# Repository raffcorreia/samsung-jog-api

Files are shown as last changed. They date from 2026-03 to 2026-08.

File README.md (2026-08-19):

# samsung-jog-api

`samsung-jog-api` is a hardware-and-software project to make a Samsung `CJ791` monitor locally programmable by electrically emulating its front-panel `JOG` control, exposing that behavior through a local REST API, and hosting a touch-first local control interface on a Raspberry Pi-based control deck.

This repository is organized around the Samsung `LC34J791WTNXZA / CJ791` hardware in my setup. Related Samsung monitors with a similar multi-jog front-panel board may be adaptable, but the measurements and assumptions here are specific to this unit unless noted otherwise.

## Monitor photo

<p align="center">
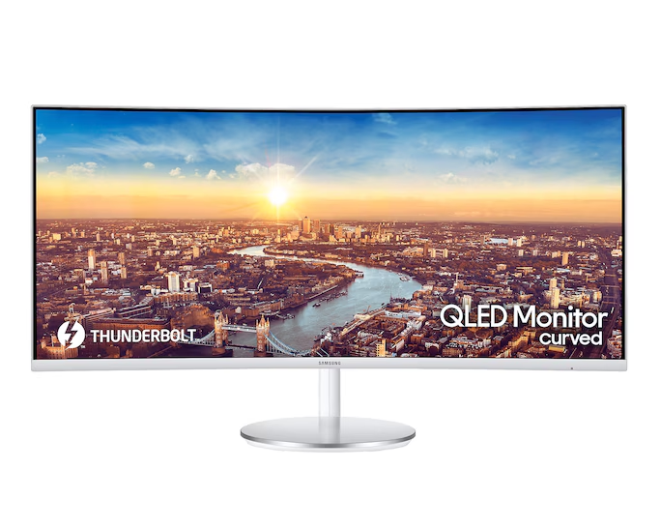
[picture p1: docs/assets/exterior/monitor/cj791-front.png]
Samsung CJ791 front view
  
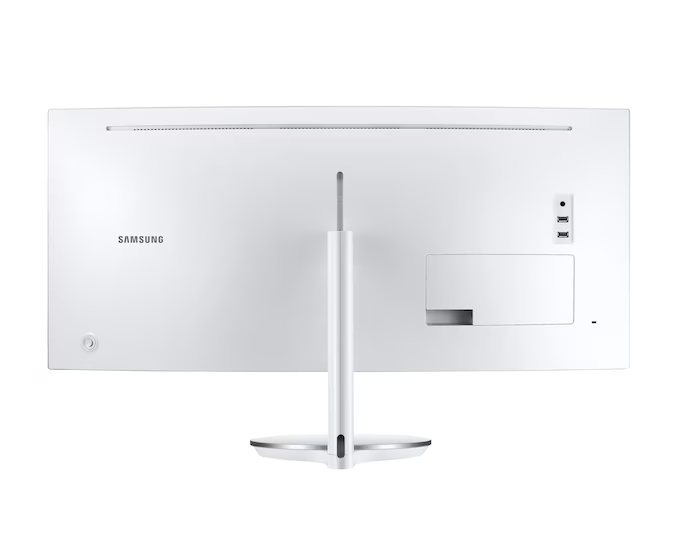
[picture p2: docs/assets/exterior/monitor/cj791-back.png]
Samsung CJ791 rear view
  
</p>

## Status

Current state of the repository:

- completed: `Phase 0: Documentation and Evidence Capture`
- completed: `Phase 1: Host Preparation and Conservative OS Cleanup`
- completed: `Phase 2: Hardware Validation`
- completed: `Phase 3: Bus Observation Circuit Design`
- completed: `Phase 4: Analog Drive Circuit Design` (design docs, KiCad schematic/PCB, BOM, and concept schematic)
- completed: `Phase 5: HDMI and DDC Communication Design`
- completed: `Phase 6: Discrete-Component Protoboard Validation`
- completed: `Phase 8: GPIO Assignment and Low-Level Control Prototype` — [execution record](docs/implementation/phase-8-execution.md)
- completed: `Phase 9: Local Platform Bring-Up` — [execution record](docs/implementation/phase-9-execution.md), [runbook](docs/runbooks/phase-9-platform-bring-up.md) (`systemd` unit `config/systemd/pi-deck.service`, kiosk scripts under `scripts/kiosk/`)
- completed: `Phase 10: Local API` — [execution record](docs/implementation/phase-10-execution.md) (REST `/api/v1`, WebSocket `/ws/events`)
- completed: `Phase 11: Low-Level JOG Console UI` — [execution record](docs/implementation/phase-11-execution.md) (React JOG console in [`frontend/`](frontend/); **live GPIO on the deck host** verified — UI drives real JOG on the appliance)
- completed: `Phase 12: Deployment and Version Tracking` — [execution record](docs/implementation/phase-12-execution.md) (`scripts/deploy.sh`, deploy counter/version badge, kiosk reload workflow)
- completed: `Phase 13: Full-Screen UI Layout with Placeholders` — [execution record](docs/implementation/phase-13-execution.md) (1280×800 deck shell, real JOG/log, calendar and notes placeholders, settings route, popup template, seven-segment clock, LED/record stubs)
- completed: `Phase 14: Log Architecture Refactor` — [execution record](docs/implementation/phase-14-execution.md) (backend-owned live log buffer, WebSocket replay on connect, synced multi-client log stream)
- completed: `Phase 15: Observation Bus and Hardware Interface` — [execution record](docs/implementation/phase-15-execution.md) (interrupt-driven ADS1115 + GPIO observation bus, single websocket authority for holds/releases/LED)
- parked, hardware access pending: `Phase 16: Recording and Replay Subsystem` — recording workspace, sequence runner, upload/download/edit/replay UI complete; on-device validation is blocked until hardware access is available
- completed: `Phase 17: Development Fixture` — [execution record](docs/implementation/phase-17-execution.md) (crude open support to hold monitor/control-deck hardware together for development)
- completed: `Phase 18: Display and Touch Validation` — [execution record](docs/implementation/phase-18-execution.md) (Waveshare DSI display/touch working; HDMI disabled as a display and retained for DDC/CI only; safe brightness ceiling `170/255`)
- completed: `Phase 19: Display Usability and Power Hardening` — [execution record](docs/implementation/phase-19-execution.md) (display/Pi power menu, brightness API/UI cap, color/edge validation page, Xwayland/font readability pass, power measurements)
- completed: `Phase 21: Display Power Control Circuit` — [execution record](docs/implementation/phase-21-execution.md) (high-side 5V switch + RC soft-start to prevent Pi 5 shutdown on display reconnect; hardware design complete)
- completed: `Phase 23: Documentation Reorganization, Versioning, and Deploy Harness` — [execution record](docs/implementation/phase-23-execution.md) (artifact-based naming for all docs and KiCad projects, git-tag versioning, auto-tag on deploy, version panel in settings UI, deploy runbook)
- next: `Phase 20: Raspberry Pi 5 Rebuild and Display Performance Validation` — [execution record scaffold](docs/implementation/phase-20-execution.md), [GPIO schema](docs/hardware/pi5-gpio-schema.md)
- in parallel: `Phase 7: Integrated Controller Board Design` (KiCad / layout in progress)
- repository now includes Phase 1 runbooks and host-preparation scripts
- repository now includes a Phase 2 execution record for hardware validation
- repository now includes a Phase 3 execution record for bus-observation hardware design
- repository now includes a Phase 4 execution record, KiCad design files, and analog-drive BOM artifacts
- repository now includes completed Phase 5 transport design documentation and execution record
- repository now includes completed Phase 6 protoboard validation documentation, schematic, BOM, and execution record
- hardware findings for the `JOG` board and DDC behavior
- requirements, design, test strategy, and implementation planning for a Raspberry Pi kiosk-style control deck
- Application code layout: [`backend/`](backend/) (Python package **`pi_deck`**: `api`, `services`, `hardware`, … per [Architecture](docs/architecture.md)), [`frontend/`](frontend/) (React/TypeScript UI; `npm run build` copies assets into `backend/src/pi_deck/static/`; **`npm run test:e2e`** in `frontend/` builds the UI, runs Playwright against mock `pi-deck` on 8756, or set `E2E_BASE_URL` for a live Pi); protoboard GPIO helpers live under `backend/src/pi_deck/hardware/`. Bring-up script: `scripts/pi-deck-gpio-probe` (see [runbook](docs/runbooks/gpio-bench-probe.md)) — see [Phase 8 Execution Record](docs/implementation/phase-8-execution.md). Host metrics / Pi baseline: `scripts/pi-deck-host-health.py` (see [Phase 9 execution](docs/implementation/phase-9-execution.md) and [Host health gate](docs/implementation/plan.md#host-health-gate-feature-phases-1028)).

## Why this project exists

The CJ791 is a capable monitor, but it is frustrating to automate cleanly.

- It has multiple useful inputs: `HDMI`, `DisplayPort`, and `Thunderbolt / USB-C`
- It has a rear-mounted `JOG` control that can navigate the on-screen display and trigger functions the normal software control path cannot, but it is inconvenient to use repeatedly
- It exposes DDC/CI, which is enough to read some state and control some functions
- It does not reliably expose the full monitor control surface over DDC alone on this unit

In practice, this project uses a hybrid model:

- `JOG` emulation for actions that need true front-panel behavior
- `DDC/CI` for machine-readable feedback and the functions that already work reliably
- front-panel `LED` observation for local feedback cues such as input-change blink patterns, idle state, and possible OSD boundary signals
- a local Raspberry Pi touch device as the always-on operator-facing control surface

This matters especially for input switching. On this monitor, source selection is effectively a cycle through available inputs rather than a reliable direct jump to a named source, so current-state feedback is what tells the controller when to stop cycling.

## System overview

High-level system shape:

- custom inline controller sits between the original `JOG` board and the monitor main board
- controller reproduces the same resistance-to-ground states the monitor expects on `KEY_ADC1` and `KEY_ADC2`
- controller observes the front-panel `LED` state as an additional feedback signal
- local backend software exposes high-level actions through a REST API
- a local touch UI runs in kiosk mode on a Raspberry Pi and calls the same API
- DDC/CI provides state readback and supported direct controls such as brightness and power

The system is expected to support three operating modes:

- `JOG` mode for raw low-level control, investigation, and recovery
- `DDC` mode, where the controller can read the current input and stop source-cycling or `PIP` navigation at the correct state
- `Blind` mode, where the UI asks the user for current and desired input so the controller can perform blind source cycling from a known starting point

## Documentation index

Use these section indexes to navigate the repository documentation:

- [Hardware Reference](docs/hardware/README.md) — GPIO wiring, Raspberry Pi pinout, monitor connections, schematics, and bills of materials
- [Implementation Plan](docs/implementation/plan.md) — planned phases and links to phase execution records
- [Investigation Data](docs/investigation/) — register captures, I2C/DDC scans, and hardware-analysis notes
- [Runbooks](docs/runbooks/) — Raspberry Pi preparation, deployment, and hardware bring-up procedures

Core project documents:

- [Requirements](docs/requirements.md)
- [Solution Overview](docs/design/solution-overview.md)
- [Architecture](docs/architecture.md)
- [Implementation Plan](docs/implementation/plan.md)
- [Test Strategy](docs/testing/test-strategy.md)
- [Code Guidelines](docs/development/code-guidelines.md)

Hardware and reverse-engineering entry points:

- [Hardware Reference index](docs/hardware/README.md)
- [Raspberry Pi 5 GPIO schema and 40-pin header reference](docs/hardware/pi5-gpio-schema.md)
- [Protoboard schematic and Raspberry Pi pinout diagram](docs/hardware/protoboard-schematic.md)
- [CJ791 JOG board notes](docs/hardware/cj791-jog-board.md)
- [CJ791 DDC and VCP Behavior](docs/ddc/cj791-vcp-behavior.md)

Operational docs:

- [Prepare Raspberry Pi](docs/runbooks/prepare-raspberry-pi.md)
- [Phase 9: Local platform bring-up](docs/runbooks/phase-9-platform-bring-up.md)
- [GPIO bench probe (protoboard)](docs/runbooks/gpio-bench-probe.md) — GPIO/I²C bring-up script on the Pi
- [Phase 2 Execution Record](docs/implementation/phase-2-execution.md)
- [Phase 3 Execution Record](docs/implementation/phase-3-execution.md)
- [Phase 4 Execution Record](docs/implementation/phase-4-execution.md)
- [Phase 5 Execution Record](docs/implementation/phase-5-execution.md)
- [Phase 6 Execution Record](docs/implementation/phase-6-execution.md)
- [Phase 8 Execution Record](docs/implementation/phase-8-execution.md)
- [Phase 12 Execution Record](docs/implementation/phase-12-execution.md)
- [Phase 13 Execution Record](docs/implementation/phase-13-execution.md)
- [Phase 14 Execution Record](docs/implementation/phase-14-execution.md)
- [Phase 15 Execution Record](docs/implementation/phase-15-execution.md)
- [Recording Syntax](docs/design/recording-syntax.md)

## Start here

Recommended reading order:

1. [README.md](README.md)
2. [Requirements](docs/requirements.md)
3. [Solution Overview](docs/design/solution-overview.md)
4. [Hardware Reference](docs/hardware/README.md)
5. [CJ791 JOG Board Notes](docs/hardware/cj791-jog-board.md)
6. [CJ791 DDC and VCP Behavior](docs/ddc/cj791-vcp-behavior.md)
7. [Implementation Plan](docs/implementation/plan.md)

## Safety and scope

This project intentionally modifies monitor hardware and is not warranty-safe.

- opening the monitor can damage clips, cables, or boards
- cutting or extending the `JOG` harness can permanently alter the monitor
- mistakes on the key lines can damage the monitor input circuitry
- nothing here should be treated as stock-safe or supportable by the manufacturer

The goal is not to preserve stock condition. The goal is to create a practical, local, programmable control interface for a monitor whose original user interface is difficult to automate cleanly.

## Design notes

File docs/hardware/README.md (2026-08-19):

# Hardware Reference

Living reference documents for the Samsung CJ791 JOG project hardware. These are named by artifact, not by the phase that created them. Phase-specific decisions and validation evidence belong in the corresponding execution records under `docs/implementation/`.

Return to the [project README](../../README.md), or choose a hardware topic below.

## Raspberry Pi and current protoboard

| Document | What it covers |
|---|---|
| [Raspberry Pi 5 GPIO schema](pi5-gpio-schema.md) | BCM numbers, physical pins, signal names, direction, and a visual 40-pin header reference |
| [Protoboard schematic](protoboard-schematic.md) | Wiring and circuit description for the Phase 6 protoboard, including the Raspberry Pi pinout diagram and display power control additions |
| [Protoboard BOM](protoboard-bom.md) | Component list for the Phase 6 discrete-component protoboard (current bring-up hardware) |

## Monitor interface and circuit references

| Document | What it covers |
|---|---|
| [CJ791 JOG board](cj791-jog-board.md) | Samsung CJ791 front-panel JOG board connector pinout, measured signal levels, and resistor-ladder values |
| [Observation circuit BOM](observation-bom.md) | Components for the CN1001 bus observation circuit (`KEY_ADC1`, `KEY_ADC2`, and `KEY_LED` conditioning) |
| [Analog drive circuit BOM](analog-drive-bom.md) | Components for reproducing the analog JOG resistor ladder |
| [HDMI and DDC transport](hdmi-ddc-transport.md) | HDMI/DDC/CI signal path, level shifting, and host integration |

## Diagrams and images

Diagrams are kept under [`docs/assets/hardware/`](../assets/hardware/) and are presented from the relevant reference document. For GPIO wiring, start with the [Raspberry Pi 5 GPIO schema](pi5-gpio-schema.md); for the complete circuit, use the [protoboard schematic](protoboard-schematic.md).

## Naming rule

- **This directory**: artifact-named living references (schematic descriptions, BOMs, GPIO maps, signal characterization)
- **`docs/implementation/phase-*-execution.md`**: frozen phase history (decisions made, measurements taken, work done)
- **`docs/assets/hardware/`**: diagrams and images referenced by the documents above

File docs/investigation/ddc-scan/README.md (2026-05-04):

# DDC VCP Scan — Phase 24 Investigation

Monitor: **Samsung C34J79x** (`SAM`, product code `0x0F1C`)
Host: Raspberry Pi 5 — I2C bus 13 (HDMI0 / `card2-HDMI-A-1`)
Tool: `tools/scripts/ddc-scan.py`

## Methodology

Three independent passes were run to rule out any order-dependent or state-dependent response behaviour.
The retry policy in each pass: if the previous command succeeded but the current one fails, wait 5 s and retry once before moving on.

| Pass | File | Order | Codes scanned | Codes responding |
|---|---|---|---|---|
| 1 | `ddc-scan-20260501-153903` | Ascending (0x00→0xFF) | 256 | **32** |
| 2 | `ddc-scan-20260501-161242` | Descending (0xFD→0x00) — only the 224 that did not respond in Pass 1 | 224 | **0** |
| 3 | `ddc-scan-20260501-161655` | Random (all 256) | 256 | **32** |

**Conclusion: the monitor exposes exactly 32 VCP codes regardless of scan order.** No codes are shy or order-dependent. The capability string returned nothing in all three passes — brute-force was the only reliable method.

## Responding Codes (ground truth)

| Code | Name | Type | Current (Pass 1) | Max / SL |
|---|---|---|---|---|
| `0x02` | New Control Value | CNC | — | x00 xff x00 x02 |
| `0x0B` | Color Temperature Increment | CNC | — | xff xff x00 x32 |
| `0x0C` | Color Temperature Request | C | 40 | 170 |
| `0x10` | Brightness | C | 59 | 100 |
| `0x12` | Contrast | C | 75 | 100 |
| `0x14` | Select Color Preset | SNC | — | x04 |
| `0x16` | Red Video Gain | C | 70 | 100 |
| `0x18` | Green Video Gain | C | 70 | 100 |
| `0x1A` | Blue Video Gain | C | 70 | 100 |
| `0x52` | Active Control | CNC | — | x00 xff x00 x00 |
| `0x60` | Input Source | SNC | — | x04 (value meaning TBD) |
| `0x62` | Audio Speaker Volume | C | 3 | 100 |
| `0x6C` | Video Black Level: Red | C | 50 | 100 |
| `0x6E` | Video Black Level: Green | C | 50 | 100 |
| `0x70` | Video Black Level: Blue | C | 50 | 100 |
| `0x8D` | Audio Mute | SNC | — | x02 |
| `0xAA` | Screen Orientation | SNC | — | x00 |
| `0xAC` | Horizontal Frequency | C | 23364 | 65281 |
| `0xAE` | Vertical Frequency | C | 6000 | 65535 |
| `0xB2` | Flat Panel Sub-Pixel Layout | SNC | — | x01 |
| `0xB6` | Display Technology Type | SNC | — | x03 |
| `0xC0` | Display Usage Time | C | 200 | 65535 |
| `0xC6` | Application Enable Key | CNC | — | xff xff x00 x6f |
| `0xC8` | Display Controller ID | CNC | — | xff xff x00 x12 |
| `0xC9` | Display Firmware Level | CNC | — | xff xff x01 x20 |
| `0xCA` | OSD/Button Control | SNC | — | x02 |
| `0xCC` | OSD Language | SNC | — | x02 (English) |
| `0xD6` | Power Mode | SNC | — | x01 (On) |
| `0xDC` | Display Application | SNC | — | x02 |
| `0xDF` | VCP Version | CNC | — | x02 x01 (v2.1) |
| `0xFE` | Unknown — manufacturer-specific | CNC | — | x00 x02 x00 x02 |
| `0xFF` | Unknown — manufacturer-specific | CNC | — | x00 x01 x00 x00 |

## Notable observations

- **No capability string** — the monitor does not advertise supported codes; brute-force was required.
- **Retry logic fired heavily** — a successful read frequently causes the next query to fail. The 5 s retry is necessary for accurate results.
- **`0xAE` Vertical Frequency** read as `6000` in Pass 1 and `6010` in Pass 3 — minor variance, likely centihz (60.00 / 60.10 Hz).
- **`0xFE` and `0xFF`** respond but are not defined in the MCCS standard — manufacturer-specific, worth further investigation.
- **`0x60` Input Source** current value `x04` — exact Samsung mapping TBD (next step).
- **`0xD6` Power Mode** current value `x01` = On (MCCS standard: 1=On, 2=Standby, 3=Suspend, 4=Off).

## Next steps

1. Decode `0x60` Input Source: enumerate valid values by switching inputs and reading back.
2. Test `0xD6` Power Mode writes for standby/wake control.
3. Investigate `0xFE` and `0xFF` manufacturer-specific codes.

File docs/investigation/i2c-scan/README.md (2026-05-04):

# Samsung C34J79x — Raw I2C Scan Findings

Phase 24 investigation. Raw I2C reads via `smbus2` on I2C bus 13, bypassing DDC/CI protocol.
DDC only surfaces what the firmware advertises; direct I2C exposes the full scaler register map.

Script: `tools/scripts/collect-register-capture.py`

---

## Device map — I2C bus 13

| Address | Device | Notes |
|---|---|---|
| `0x37` | DDC/CI controller (8051 MCU) | Raw I2C returns bus echo only; must use DDC/CI protocol |
| `0x50` | EDID ROM | |
| `0x54` | Likely HDCP controller | Activates when Pi HDMI port is outputting; not display-state-dependent |
| `0x58` | Novatek scaler SoC (probable) | 256/256 registers readable; holds live scaler and pipeline state |

---

## DDC VCP 0x60 — most reliable source indicator

Read via DDC/CI protocol on device 0x37 (no ddcutil needed). Unaffected by OSD or overlays.

| Value | Source |
|---|---|
| `0x01` | HDMI |
| `0x03` | DisplayPort |
| `0x04` | Thunderbolt / USB-C |

In PBP mode: reports the left/primary source.
In PIP mode: reports the main (large) source.

---

## Device 0x58 — register reference

### Reliable registers

| Register | Meaning |
|---|---|
| `0x48=0x0F` | PIP mode active (was `0x00` in all PBP and single-source captures) |
| `0x48=0x00` | PBP or single-source mode |
| `0x4A=0x00` | Sound routed left |
| `0x4A=0x02` | Sound routed right |
| `0xA1=0x00` | No active video signal |
| `0x02=0x79` | Scan sanity check — confirms scaler is in a normal active state |

### Persistently noisy registers — exclude from detection logic

These change between reads of the same state and carry no reliable state information:

- `0x3C`, `0x3D`, `0x3E` — free-running counters
- `0xA0`, `0xA3`, `0xA5` — active-state noise, no stable value
- `0xA1` — toggles between `0x21` and `0x22` unpredictably during active video
- `0x0B`, `0x0C`, `0x0D` — toggle between two fixed values on a ~2–4s period; likely frame sync counters
- `0x1F` — oscillates between `0x00` and `0xEE`

---

## PIP mode — E0–E3 pipeline register matrix

> All PIP scans: style = **Wide**, position = **top-left** (position has no effect on any register — see below).
> All confirmed clean: `0x58:0x02=0x79`, `0xE1≠0xFA` at scan time.

| Directory | Main | PIP | Size | VCP 0x60 | 0xE0 | 0xE1 | 0xE2 | 0xE3 |
|---|---|-----|---|---|---|---|---|---|
| `pip-size1-tb-small-dp-main` | DP | TB | 1 | `0x03` | `0x80` | `0xE2` | `0x00` | `0x00` |
| `pip-size2-tb-small-dp-main` | DP | TB | 2 | `0x03` | `0x40` | `0x8C` | `0x01` | `0x2E` |
| `pip-size3-tb-small-dp-main` | DP | TB | 3 | `0x03` | `0x40` | `0x8C` | `0x01` | `0x2E` |
| `pip-size1-hdmi-small-dp-main` | DP | HDMI | 1 | `0x03` | `0x40` | `0x4E` | `0x00` | `0x00` |
| `pip-size2-hdmi-small-dp-main` | DP | HDMI | 2 | `0x03` | `0x40` | `0x8C` | `0x01` | `0x2E` |
| `pip-size3-hdmi-small-dp-main` | DP | HDMI | 3 | `0x03` | `0x80` | `0xE2` | `0x00` | `0x00` |
| `pip-size1-hdmi-small-tb-main` | TB | HDMI | 1 | `0x04` | `0x40` | `0x35` | `0x05` | `0x20` |
| `pip-size3-hdmi-small-tb-main` | TB | HDMI | 3 | `0x04` | `0x40` | `0x35` | `0x05` | `0x20` |
| `pip-size3-tb-small-hdmi-main` | HDMI | TB | 3 | `0x01` | `0x80` | `0xE2` | `0x00` | `0x00` |

### Key findings from the matrix

- **TB main is fully blind** — E0–E3 are identical (`0x40/0x35/0x05/0x20`) regardless of PIP source or size.
  Cannot detect PIP source, size, or position from registers when TB is the main source.
- **PIP source is not independently detectable for DP main** — TB pip and HDMI pip at size2 produce identical
  E0–E3 values; same at size3 vs size1. Only size1 HDMI pip has a unique value (`0xE1=0x4E`).
- **E0–E3 encode a non-linear combination** of main source, PIP source, and size simultaneously.
  Cannot decode any single dimension independently.
- **VCP 0x60 identifies main source reliably** regardless of PIP source, size, or position.

### Contamination note

`pip-size1-hdmi-small-dp-main` was recaptured on 2026-05-02 after the original scan was found contaminated —
E0–E3 matched the Menu2 OSD state exactly, indicating the OSD was still open when the original scan ran.
The recheck confirmed the clean values above.

---

## PIP window position — register invisible

Tested on HDMI pip / TB main / size1 across all four positions (top-left, top-right, bottom-left, bottom-right).
Full 256-register diff showed no differences in any stable register across all positions.
**PIP window position has no effect on any 0x58 register.**

---

## OSD / overlay register behaviour

Tested 2026-05-02 via scripted button presses, full 256-register scan at 1s intervals.
State: TB main / HDMI pip / size1 / Wide / top-left.

### What is reliable

- **`0xE1=0xFA`** — fires when Menu1 OSD is open (including after UP navigation). Use as a scan guard:
  if `0xE1=0xFA`, abort and retry — the scan will be contaminated.
- **`0xE3=0x6E`** — appears after UP navigation within Menu1. `0x00` at the first Menu1 item.
- **`0xA7=0x00`** — drops during a physical button press, recovers to `0xF8` within ~500ms.

### What cannot be tracked

- **Menu2 is register-identical to baseline.** When CENTER is pressed from Menu1+UP, `0xE1` drops from
  `0xFA` back to its baseline value within ~1s. Registers look exactly like OSD-closed from that point.
  There is no way to tell from 0x58 whether Menu2 is on screen.
- **OSD inactivity close (~18–20s after last input in Menu2) produces no detectable register change.**
  Full 256-register scans at 1s intervals throughout the close window showed nothing definitive.
- **`0xE1=0xFA` is a Menu1 indicator only, not a universal OSD indicator.** The clean-scan guard
  only protects against Menu1 contamination; Menu2 contamination is invisible.

### Suspicious registers observed at OSD close

A one-sample transient was caught at the moment the OSD appeared to close (~+18s after Menu2 entry):
`0x4A`, `0x0D`, and `0x11` all read `0x00` simultaneously, recovering at the next 1s sample.
`0x4A` (sound routing) is normally rock-solid at rest. Not conclusive — the full scan takes ~1s to
execute, so these may have been caught mid-transition rather than representing a stable state.

---

## ⚠️ E0–E3 contamination warning

All PBP scan data for `0xE0`–`0xE3` is potentially contaminated — input-change notifications and OSD
menus were likely displayed during those captures.

**Protocol for clean captures:**
1. Wait for all on-screen messages to fully dismiss
2. Confirm `0xE1 ≠ 0xFA` (no Menu1 OSD open)
3. Be aware that Menu2 is undetectable — wait at least 25s after any OSD interaction before scanning

**Retake policy:** validate every capture inline before moving to the next state. If any of the following fail, call it immediately and retake on the spot — do not defer:
- `0x02 ≠ 0x79` — scaler not in normal state
- `0xE1 = 0xFA` — Menu1 OSD still open
- Values match a known-contaminated pattern (e.g. E0–E3 matching a Menu2 or wrong-mode fingerprint)
- Result looks inconsistent with the expected mode

---

## Scan file index

### Baseline / single-source (Phase 24 initial scans)

| File | State |
|---|---|
| `i2c-scan-idle-20260501-210013.jsonl` | Monitor idle, no active source |
| `i2c-0x58-on-idle-20260501-212914.jsonl` | 0x58 only, post-reboot idle |
| `i2c-0x58-tb-active-20260501-214114.jsonl` | 0x58 only, Thunderbolt active |
| `i2c-all-tb-active-20260501-215231.jsonl` | All devices, Thunderbolt active |
| `i2c-all-dp-active-20260501-220136.jsonl` | All devices, DisplayPort active |
| `i2c-all-hdmi-active-20260501-222201.jsonl` | All devices, HDMI active (Pi, incompatible resolution) |

### PBP (contaminated — E0–E3 not trustworthy)

`pbp-*/` — all 6 combinations × 2 sound positions. E0–E3 captured with input-change messages on screen.

### PIP (clean, Wide style, top-left unless noted)

See matrix table above. Position scans (top-right, bottom-left, bottom-right) stored under
`pip-size1-hdmi-small-tb-main-{topright,bottomleft,bottomright}/` — confirmed identical to top-left.

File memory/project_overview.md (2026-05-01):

---
name: Project Overview — samsung-jog-api-2
description: High-level goal, phase structure, current status, Phase 7 architecture decisions, and Phase 14 UI/log state
type: project
---

Hardware + software project to build a Raspberry Pi 2B-based control deck for a Samsung LC34J791WTNXZA (CJ791) ultrawide monitor. The monitor's only input mechanism is a physical JOG (joystick) on the rear. The goal is to electrically emulate the JOG via resistance-to-ground states on KEY_ADC1/KEY_ADC2 lines, observe KEY_LED feedback, maintain DDC/CI communication, and expose control through a local REST API + WebSocket with a React/TypeScript kiosk UI on a Waveshare 7" DSI display.

**Deck UI:** Phase 13 complete. Single-screen kiosk layout (**1280×800** target). Widgets use **fixed layout bands** so panels do not reflow when the log grows (log scrolls internally). Final Phase 13 geometry: top bar `48px`, left JOG column `350px`, bottom log band `200px`. Optional widget visibility is user-driven later — not implicit layout shift. Identity ("pi-deck") stays in the status/version area, not duplicated as nested marketing chrome around each control.

**Phase structure (28 phases, 0–27). Phases 0–6, 8–15, and 17–18 are closed. Phase 16 is parked because hardware access is unavailable for validation. Phase 7 KiCad/layout remains in progress. Phase 19 has not started.**

**Phase 13 UI state:** Full-screen deck shell is implemented and deployed (`0.1.0+r20`). The real JogPad remains the priority control and lives in the fixed left column. The clock uses `DSEG7 Classic` seven-segment font, enlarged and vertically centered without increasing the `48px` top bar. Settings cog is top-right. LED is an 8mm-style gray default indicator and should turn blue only for future blink/feedback events, not for steady backend `key_led_active`. Record control exists as a visual/logging stub in the upper-right of the JOG column. Calendar, notes, settings, and OSD popup are realistic stubs/placeholders for later phases.

**Phase 14 log state:** Backend-owned live logging is implemented and deployed (`0.1.0+r22`). `LiveLogService` owns the `220`-entry replay buffer and emits structured `log/entry` WebSocket events. New clients receive replayed history immediately; multiple clients receive the same live stream. Frontend log code no longer formats command/control/bus events into local history.

**Phase 16 state:** Recording and replay subsystem code is complete and merged to main. Recording workspace popup, sequence runner, upload/download/edit, and replay UI are all implemented. Hardware validation (on-device recording/replay runs, KEY_ADC2 stall visibility during long captures) is still pending, but the phase is parked because hardware access is unavailable.

**Phase 17 state:** Closed on 2026-04-20 with a crude open support to hold the monitor/control-deck hardware together. This is intentionally not a polished enclosure or detailed mechanical design.

**Phase 18 state:** Closed on 2026-04-22. Waveshare 7" DSI display and touch are working on the Pi 2 deck host. Safe maximum brightness is `170/255`. HDMI visual output destabilized DSI scanout on this stack, so HDMI is disabled as a Linux display with `video=HDMI-A-1:d` and retained for DDC/CI communication only. DDC/CI Get VCP `0x60` succeeded on HDMI DDC while DSI/touch and ADS observation remained active.

**Phase 19 state:** Planned next. Display usability and power hardening: functional display/Pi power menu, capped brightness control, display color/edge validation page, and documentation of display power-off behavior.

**Log / event hygiene (backlog):** WebSocket and derived log traffic may feel excessive or not representative of what operators care about (duplicate `bus/snapshot` with `deck_control`, telemetry poll cadence, verbosity of `command`/`control` lines). Plan a later pass to coalesce, filter, or re-level categories so the live log stays readable without losing auditability.

**Active defect:** `KEY_ADC2` live observation has stalled twice across Phase 15/16 work. In the later case, redeploying the app restored directional observation without changing wiring. Treat this as an unresolved observation-path/runtime defect, not a closed protoboard-only issue.

**Hardware vs software sequencing:** Phase 8+ low-level software is brought up on the **Phase 6 GPIO map** first. When Phase 7 boards are fabricated, an **extra migration phase** will be inserted (slot TBD) to remap GPIO and retest software against the **Phase 7 pinout** — see `docs/implementation/plan.md` ("Deferred integrated-board GPIO and software migration").

**Why:** Input switching on the CJ791 is cycle-through-inputs only. DDC alone can't switch; JOG alone can't read state. Both are needed together.

## Phase 7 Build Path

The original Phase 7 intent was a home-built board using through-hole transistors, resistors, and capacitors (except the ADS1115 which was always SMD). That path is still valid. The KiCad/PCBWay route with SMD components and proper OpAmps is an exciting upgrade opportunity that emerged during design, not a replacement for the original plan. Either path closes Phase 7 — the choice depends on how far the PCBWay enthusiasm carries through layout completion.

**Why:** Keeping the through-hole option alive avoids blocking the project on PCB fabrication if motivation or timeline shifts.

## Phase 7 Architecture (settled as of 2026-04-11)

**Two-board design:**
- Board 1 (Controller): Phase 3 + Phase 4 merged. JST PH 2.0mm 4-pin monitor harness, 2×20 IDC Pi header, 2×7 IDC inter-board connector.
- Board 2 (HDMI DDC): Phase 5 unchanged except J3 replaced with 2×7 IDC inter-board header.

**Connectors:**
- Monitor harness: JST PH 2.0mm 4-pin (B4B-PH-K-S, C157929 at JLCPCB). 30AWG 4-core cable.
- Pi interface: 2×20 shrouded IDC box header + 40-pin ribbon cable.
- Inter-board: 2×7 shrouded IDC box header + 14-pin ribbon cable (pre-made IDC cables).

**Power:** Pi powered by its own 3A micro-USB supply. Pi GPIO rails power boards (no onboard regulation on boards). Pi 2B + Waveshare 7" DSI + USB WiFi + boards = ~1.82A, well within 3A supply.

**GPIO (17 signals used, 9 free):**
- GPIO2/3: I2C SDA/SCL (fixed)
- GPIO17,27,22,23,24: ADC2_LEFT/RIGHT/DOWN/UP_EN, ADC1_CENTER_EN (outputs)
- GPIO25: PI_DDC_DISC_REQ (output)
- GPIO5: MON_5V_DISABLE (output)
- GPIO6,12,13: KEY1_IN_GPIO, LED_IN_GPIO, ADC_ALERT (inputs)
- GPIO19,16,26,20,21: DDC_READY, SRC_5V_SENSE, RESERVED, PIN18_STAT, HPD_SENSE (inputs)

**Passives:** All 0603 metric throughout both boards.

**Peripherals:**
- Waveshare 7" DSI LCD (E), 1280×800 (~700mA)
- USB WiFi adapter (~300mA)
- Logitech USB dongle (development only, ~100mA)

**KiCad files location:**
- Board 1: hardware/kicad/controller-board/
- Board 2: hardware/kicad/hdmi-ddc-board/

**Execution record:** docs/implementation/phase-7-execution.md

**Status as of 2026-04-11:** Execution record written. KiCad schematics in progress. PCB layout not yet done.

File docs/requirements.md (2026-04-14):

# Requirements

## Purpose

This document defines the functional and non-functional requirements for `samsung-jog-api` as a local control deck for the Samsung `CJ791` monitor. The system combines a local kiosk UI, a backend control service, analog `JOG` emulation, `DDC/CI` readback, and front-panel `LED` observation.

This is explicitly a hardware-and-software project. The system requires interface hardware that can bridge between the host's control interfaces and the monitor's analog key and signal paths.

The purpose of this document is to define the system's required behavior, constraints, and acceptance expectations. Setup procedures, implementation details, and exploratory notes belong in other documents unless they are necessary to clarify a requirement.

## System overview

The system consists of:

- a local host device with a display and kiosk-style user interface
- a local frontend UI
- a local backend service
- custom hardware that emulates the monitor's front-panel `JOG` inputs through the monitor's analog key lines
- custom hardware that reads the front-panel `LED` signal and other relevant monitor-side signals
- `DDC/CI` integration for monitor-state readback and supported direct controls

The target monitor is currently the Samsung `LC34J791WTNXZA / CJ791`.

## Functional requirements

### Device and UI

- The system must run as a dedicated local appliance on a control deck or equivalent local host device.
- The system must present a touch-first graphical UI on the device display.
- The UI must run in kiosk mode.
- The UI must be accessible both on the device itself and remotely from other clients on the same trusted local network, such as a phone or another computer.
- The UI must be fully implemented in English.
- The UI must support light mode and dark mode.
- The device must auto-start the application stack on boot.
- The device must recover automatically after process crashes or system reboots.
- Normal operation must not require a keyboard.

### Dashboard and widgets

- The UI must display a clock widget.
- The UI must display a month calendar widget with today's date selected and today's appointments list.
- The UI must display a notes widget.
- The UI must display system performance widgets including:
  - throttling status
  - CPU usage
  - memory usage
- The performance area must support a detailed view showing:
  - storage usage
  - network usage

### Monitor control

- The system must control the monitor by electrically reproducing the analog behavior of the front-panel `JOG` controls.
- The system must expose low-level `JOG` actions equivalent to `up`, `down`, `left`, `right`, and center press.
- The system should preserve use of the original front-panel `JOG` board when practical and electrically safe.
- The system must support recording and replaying `JOG` action sequences so repeatable OSD workflows can be captured and reused.
- The system must expose monitor control through a local backend API.
- The API must support both low-level primitives and higher-level monitor actions.

### Input switching and operating modes

- The system must model input switching as source cycling rather than assuming reliable direct selection is available.
- The system must treat current input state as operationally important for source switching.
- The system must support a `DDC` mode in which current input state is read from the monitor and used to terminate source-cycling at the correct target input.
- The system must support a `Blind` mode for workflows where `DDC` readback is unavailable or unreliable.
- In `Blind` mode, the UI must let the user choose the current input and desired input so the controller can calculate how far to cycle.
- In `DDC` mode, the UI should allow simplified target-driven source selection.

### Picture-in-Picture and related monitor workflows

- The system must support enabling and configuring `PiP`.
- The UI must provide a `PiP` action that lets the user choose the left input and right input.
- In `DDC` mode, the system should simplify `PiP` configuration by using available monitor-state feedback.
- In `Blind` mode, the system must still allow `PiP` workflows using user-provided starting state and blind `JOG` sequencing.

### DDC and LED feedback

- The system must read monitor state through `DDC/CI` whenever reliable and available.
- The system must provide direct software control for features that already work over `DDC`, such as brightness and power state.
- The system must preserve practical use of the monitor's `HDMI` input while maintaining a `DDC` communication path for the control deck.
- The system must include interface hardware that allows an external device to use the monitor's `HDMI` input while the control deck also communicates with the monitor over `DDC`.
- The system must observe the front-panel `LED` state as a feedback input.
- The system should use front-panel `LED` behavior as an additional confirmation signal for monitor-state changes and OSD workflows.
- The UI should reflect relevant `LED` activity visually.
- `LED` signals may be used as command acknowledgment where their meaning is sufficiently characterized.

### Shared state and synchronization

- The system must maintain a single coherent model of `JOG` control ownership and current monitor interaction state.
- The system must prevent conflicting concurrent `JOG` actions from being executed at the same time.
- The system must support real-time communication between frontend clients and the backend.
- Any action performed in one UI instance must be reflected in all connected UI instances.
- Real-time synchronization must include:
  - button presses
  - state changes
  - monitor interactions

## Hardware requirements

### JOG control path

- The system must simulate the monitor's resistive analog key inputs.
- The system must interface with `KEY_ADC1` and `KEY_ADC2`.
- The system must reproduce the required analog states safely and repeatably.
- The project must define and document the electronic components used in the control path.

### Signal reading

- The system must be able to observe the relevant monitor-side signals needed for control-state awareness.
- The system must read or infer the state of `KEY_ADC1` and `KEY_ADC2` as needed for validation and arbitration.
- The system must detect both:
  - system-generated inputs
  - manual user inputs on the physical control path
- The system must provide a hardware path for shared or multiplexed `HDMI` and `DDC` access so monitor input availability is not unnecessarily reduced by the control deck.

### LED input

- The `KEY_LED` signal must be connected as input only.
- The system must not drive the monitor's `LED` output line.

### Physical controls and design outputs

- The system must include a physical button for toggling the display power, while the deck itself remains powered so it can continue controlling the monitor.
- The project must include and document:
  - circuit design and schematic
  - component specification and `BOM`
  - integrated controller board design
  - PCB design, if applicable

## Software architecture requirements

### Layers

The system must be organized into these logical layers:

- hardware control layer
- backend API layer
- frontend UI layer

### Communication

- The frontend and backend must communicate locally over `localhost`.
- The system must support bidirectional communication between frontend and backend.
- Real-time communication is required.

### Deployment

- Deployment may be manual in the current phase.
- Host-device administration may be performed over the local network using `SSH` with public-key authentication when applicable.
- `CI/CD` is out of scope for the current phase.

## Security requirements

### Current phase

- The system must run with an auto-login kiosk user.
- No password is required for local UI access on the kiosk device itself.
- Remote UI and API access must be limited to the trusted local network.
- External internet exposure is out of scope and should be avoided by default.

### Minimal protection

- The system should support optional token-based authentication for API access.

### Future considerations

- authentication and authorization mechanisms
- secure remote access
- role-based access control
- API security hardening

## Non-functional requirements

### Testing

- Testing is a project requirement.
- Testing must cover:
  - backend logic
  - frontend behavior
  - hardware interaction
- No task should be treated as complete before the relevant test coverage has passed.

### Performance

- The system must monitor host-device performance continuously during normal operation.
- The system must detect and expose throttling conditions.
- The software stack should remain lightweight enough for the initial target host class.

### Reliability

- The system must operate continuously in kiosk mode.
- The UI must recover automatically after crashes or reboot.
- The system should degrade gracefully when `DDC` readback is unavailable.
- The system should remain usable in `Blind` mode when `DDC` state is unavailable.

### Usability

- The UI must be touch-friendly.
- The initial UI design target is the **7" DSI capacitive touch display at `1280×800`** while remaining responsive for other screen sizes used through the host URL.
- The UI must adapt to the target screen size and orientation used by the control deck.
- The UI should make the active operating mode clear to the user.

### Maintainability

- The system should preserve a clear separation between hardware control, monitor-state readback, API behavior, and UI logic.
- Hardware assumptions and measured monitor behavior must be documented explicitly.

## Assumptions

- The monitor decodes front-panel actions by measuring analog thresholds on `KEY_ADC1` and `KEY_ADC2`.
- Reproducing the original resistance values closely enough will allow the monitor to interpret emulated actions as native `JOG` input.
- `DDC/CI` remains useful as a feedback and telemetry channel even where it is incomplete as a control channel.
- Input changes are reached by cycling through sources rather than reliably selecting a named input directly.
- The front-panel `LED` exposes observable behavior that can help confirm state changes such as input switching, idle state, and some menu boundary conditions.
- Common user goals can be represented as a combination of low-level button actions, `DDC` readback, `LED`-assisted feedback, and user-provided current-state information when needed.

## Constraints

- The target monitor is currently the Samsung `LC34J791WTNXZA / CJ791`.
- The monitor does not appear to expose full input switching reliably through `DDC/CI` alone.
- Occupying the monitor's `HDMI` path for `DDC` communication would reduce practical input availability unless compensated by custom interface hardware.
- The front-panel control path is analog, not purely digital.
- Hardware modification is expected and accepted.

## Acceptance criteria

The following criteria should be used to judge whether the initial implementation satisfies the requirements:

- Kiosk recovery: after reboot or a forced frontend crash, the device returns automatically to the kiosk UI without manual intervention.
- Local and remote UI access: the UI is usable on the kiosk itself and from another device on the same local network.
- `JOG` control: the system can perform each low-level `JOG` action and the monitor responds as expected.
- `DDC` mode source switching: from a known source, requesting a target source results in the monitor stopping on the requested source as confirmed by `DDC`.
- `Manual` mode source switching: given a user-selected `from` source and `to` source, the system performs the expected source-cycle sequence without relying on hidden state.
- `PiP` configuration: the system can execute a `PiP` workflow where the user selects left and right inputs.
- `LED` capture: the system can observe and expose `LED` behavior during at least idle state and source switching.
- `HDMI` preservation: the control deck maintains `DDC` communication without permanently sacrificing the monitor's practical `HDMI` input for external devices.
- Arbitration: conflicting simultaneous `JOG` actions are blocked, queued, or rejected consistently.
- Synchronization: actions and state changes in one client are reflected in other connected clients in near real time.
- Testing gate: backend, frontend, and hardware-facing tests pass before a feature is considered complete.

## Out of scope for the current phase

- support for unrelated monitor models without confirmed measurements
- external internet-facing access
- mobile native applications
- a physical volume knob, even though monitor volume control over `DDC` has been confirmed to work
- voice control
- multi-deck scaling
- `CI/CD`
- advanced authentication and authorization

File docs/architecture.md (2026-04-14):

# Architecture

## Summary

`samsung-jog-api` is built around a hybrid control architecture for the Samsung `CJ791` monitor:

- electrically emulate the front-panel `JOG` control path
- expose that behavior through a local REST API
- pair it with a small local touch UI running on a Raspberry Pi control deck
- use DDC/CI and front-panel `LED` observation as complementary feedback and status channels whenever possible

The guiding idea is simple: the monitor already knows how to respond to its own front-panel controls, so the most robust path to full control is to reproduce those same electrical states instead of relying on unsupported software-only shortcuts.

## Why this project exists

The CJ791 is a capable monitor, but it is frustrating to automate.

- It has multiple useful inputs: `HDMI`, `DisplayPort`, and `Thunderbolt / USB-C`
- It has a rear-mounted `JOG` control that can navigate the on-screen display and trigger functions the normal software control path cannot, but it is inconvenient to use repeatedly
- It exposes DDC/CI, which is enough to read some state and control some functions
- But it does not reliably expose the full monitor control surface over DDC alone

In a setup where the monitor acts like part of a desk controller, KVM-like workflow, wall panel, or local touch-screen system, blind software-only control is not enough. It needs a control path that matches what a human can do with the physical `JOG` button.

## Why the destructive part

This project intentionally takes an invasive approach.

The front-panel `JOG` assembly is connected to the monitor main board through a small harness. Rather than using motors, servos, or guessed internal software protocols, the plan is to intercept that harness and electrically reproduce the same button states the monitor already understands.

That is the destructive part:

- the monitor must be opened
- access to the front-panel control board and cable is required
- the cable may need to be cut, extended, or replaced with an inline harness
- a custom controller board can then sit between the original `JOG` board and the monitor

This is destructive in the sense that it modifies the physical monitor wiring and is not a stock, warranty-safe accessory. It is still a pragmatic choice because it targets the monitor's native control mechanism instead of relying on brittle mechanical hacks.

## Control model

The intended control model combines two different paths:

- `JOG` emulation for actions that require authentic front-panel behavior
- `DDC/CI` for readback, health checks, and functions that already work reliably
- front-panel `LED` observation for local visual confirmation of monitor behavior
- a local kiosk device as the dedicated human interface layer

At the API layer, the monitor should look like a normal controllable device rather than a collection of resistor values and timing hacks.

One important constraint is that input changes are not reliably direct-addressable. In practice, the monitor behaves like it exposes `next input` behavior through the OSD path, so source control depends on knowing the current input and cycling until the desired state is reached.

## Planned control method

The hardware plan is to insert a controller inline with the `JOG` harness.

The controller will:

- leave the original front-panel board usable when desired
- reproduce the same resistance-to-ground states for `KEY_ADC1` and `KEY_ADC2`
- observe the front `LED` line and expose its state to higher layers
- expose a local API for high-level actions such as `up`, `down`, `left`, `right`, `enter`, `back`, `open-menu`, and scripted navigation sequences
- support a Raspberry Pi-based local touch UI that calls the same API in kiosk mode

Example higher-level actions:

- switch to the next available input
- cycle from one known input to another known input
- open source list
- navigate to `Picture-by-Picture`
- toggle a known setting
- wake or sleep the monitor

## How DDC fits into the design

DDC/CI is a complementary readback channel, not the only control path.

Instead of using DDC as the entire solution, `samsung-jog-api` uses it where it is strongest:

- confirm current input with `VCP 0x60`
- read or set brightness with `VCP 0x10`
- control standby with `VCP 0xD6`
- verify that the monitor is alive and reachable over the video link
- provide state to the local UI without inferring everything from blind menu timing

The front-panel `LED` is the other important feedback source:

- observe blink patterns during input changes
- detect visible confirmation cues when a menu or scroll path reaches its boundary
- distinguish some idle versus active monitor states even when `DDC` is incomplete or delayed

## Operating modes

Two obvious operating modes fall out of this design:

- `DDC` mode: use `DDC` readback to know the current input and stop source-cycling or `PIP` navigation when the target state is reached
- `Blind` mode: when `DDC` is unavailable or untrustworthy, ask the user for current input and desired input, then execute the required blind cycling sequence

This distinction matters because the monitor does not provide a reliable direct `go to HDMI` or `go to Thunderbolt` control path. The safe abstraction is not direct selection. It is controlled cycling with feedback where available.

This hybrid model is the point of the project:

- `JOG` emulation gives access to the same menu and navigation path as a human user
- `DDC` provides machine-readable feedback and state
- `LED` observation provides immediate local feedback from the front-panel path itself
- the control deck turns those capabilities into an always-on appliance-like interface

That is much more robust than using only blind button presses, and much more capable than relying on DDC alone on this monitor. Blind-button operation is still possible, but this project prefers a feedback-aware path when available.

## Project goals

- build a reliable inline `JOG` controller for the Samsung `CJ791`
- expose monitor actions through a local REST API
- provide a Raspberry Pi-based local touch-screen UI for everyday use
- use `DDC/CI` and front-panel `LED` state for feedback and status, and `DDC/CI` for supported direct controls
- keep the design understandable enough that other Samsung owners can adapt it

## Repository layout

The repository is split so **documentation**, **KiCad hardware**, **host scripts**, and **application code** stay separate.

| Path | Purpose |
|---|---|
| `backend/` | Python package **`pi_deck`** (`backend/pyproject.toml`, distribution name `pi-deck`). Source: `backend/src/pi_deck/`. Layers: `api`, `services`, `hardware`, `storage`, `models`. Matches the system model *UI → API → services → hardware (+ DDC)* in [Solution Overview](design/solution-overview.md). |
| `frontend/` | React / TypeScript **JOG console** (kiosk + LAN); `npm run build` emits into `backend/src/pi_deck/static/` ([Code Guidelines](development/code-guidelines.md#frontend-guidelines)). |
| `docs/` | Requirements, design, implementation records, runbooks. |
| `hardware/kicad/` | Schematics and boards (not Python). |
| `scripts/` | Operational shell helpers, **bench / bring-up Python** (e.g. GPIO smoke tests, [`pi-deck-host-health.py`](../../scripts/pi-deck-host-health.py) — not part of the `pi_deck` installable surface). |
| `config/` | Example configs for host preparation and systemd unit templates (`config/systemd/`). |

Application code for Phases 9–12 lands in **`backend/`** and **`frontend/`**; KiCad stays under **`hardware/`**.

## Related documents

- [Requirements](requirements.md)
- [Solution Overview](design/solution-overview.md)
- [Code Guidelines](development/code-guidelines.md)
- [CJ791 JOG Board Notes](hardware/cj791-jog-board.md)
- [CJ791 DDC and VCP Behavior](ddc/cj791-vcp-behavior.md)

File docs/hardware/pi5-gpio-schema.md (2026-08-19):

# Phase 20 Raspberry Pi 5 GPIO Schema

This schema maps the existing Phase 6 discrete protoboard wiring onto a Raspberry Pi 5 16GB host for Phase 20 validation.

[Hardware Reference](README.md) · [Protoboard schematic](protoboard-schematic.md) · [Project README](../../README.md)

The Raspberry Pi 5 keeps the same 40-pin GPIO header pinout used by the earlier Raspberry Pi deck host. Phase 20 therefore uses the same BCM GPIO assignments as `backend/src/pi_deck/hardware/protoboard_pins.py` unless validation proves a Pi 5-specific compatibility issue.

## Interfaces

### Monitor Harness `J1`

No monitor-side wiring changes are planned for Phase 20.

| Pin | Net |
| --- | --- |
| `1` | `GND` |
| `2` | `MON_KEY_ADC2` |
| `3` | `MON_KEY_ADC1` |
| `4` | `MON_KEY_LED` |

### Raspberry Pi 5 Direct GPIO Wiring

Use BCM numbering in software and the physical header pins below for wiring.

| Pi Function | Raspberry Pi 5 Pin |
| --- | --- |
| `logic / ADC rail` | `3.3V`, physical pin `1` or `17` |
| `GND` | physical pin `6` or any other header `GND` |
| `I2C SDA` | `GPIO2`, physical pin `3` |
| `I2C SCL` | `GPIO3`, physical pin `5` |
| `ADS1115 ALERT/RDY` | `GPIO17`, physical pin `11` |
| `KEY_ADC1` input | `GPIO27`, physical pin `13` |
| `KEY_LED` input | `GPIO22`, physical pin `15` |
| `display_power_en` output (Phase 21) | `GPIO24`, physical pin `18` |
| `CENTER` drive | `GPIO5`, physical pin `29` |
| `UP` drive | `GPIO6`, physical pin `31` |
| `DOWN` drive | `GPIO13`, physical pin `33` |
| `LEFT` drive | `GPIO19`, physical pin `35` |
| `RIGHT` drive | `GPIO26`, physical pin `37` |

## 40-Pin Header Reference

Use the board silkscreen, square pad, or a known-good Raspberry Pi 40-pin reference to identify pin `1` before wiring. Do not rely on cable color or ribbon orientation alone.

Raspberry Pi 40-pin GPIO header with project connections

| Physical | Function | Phase 20 use | Physical | Function | Phase 20 use |
| --- | --- | --- | --- | --- | --- |
| `1` | `3.3V` | logic / ADC rail | `2` | `5V` | display 5V only, if header-powered |
| `3` | `GPIO2 / SDA1` | project I2C SDA | `4` | `5V` | display 5V only, if header-powered |
| `5` | `GPIO3 / SCL1` | project I2C SCL | `6` | `GND` | common ground |
| `7` | `GPIO4` | display toggle button SW1 (Phase 22) | `8` | `GPIO14` | unused |
| `9` | `GND` | common ground | `10` | `GPIO15` | unused |
| `11` | `GPIO17` | `ADS1115 ALERT/RDY` | `12` | `GPIO18` | unused |
| `13` | `GPIO27` | `KEY_ADC1` input | `14` | `GND` | common ground |
| `15` | `GPIO22` | `KEY_LED` input | `16` | `GPIO23` | unused |
| `17` | `3.3V` | optional logic / ADC rail | `18` | `GPIO24` | `display_power_en` (Phase 21) |
| `19` | `GPIO10` | WS2812B LED SPI0 MOSI direct (level shifter removed — caused corruption) | `20` | `GND` | common ground |
| `21` | `GPIO9` | unused | `22` | `GPIO25` | unused |
| `23` | `GPIO11` | unused | `24` | `GPIO8` | unused |
| `25` | `GND` | common ground | `26` | `GPIO7` | unused |
| `27` | `GPIO0 / ID_SD` | leave unused | `28` | `GPIO1 / ID_SC` | leave unused |
| `29` | `GPIO5` | `CENTER` drive | `30` | `GND` | common ground |
| `31` | `GPIO6` | `UP` drive | `32` | `GPIO12` | unused |
| `33` | `GPIO13` | `DOWN` drive | `34` | `GND` | common ground |
| `35` | `GPIO19` | `LEFT` drive | `36` | `GPIO16` | unused |
| `37` | `GPIO26` | `RIGHT` drive | `38` | `GPIO20` | unused |
| `39` | `GND` | common ground | `40` | `GPIO21` | unused |

## Display and Touch Connections

The Waveshare DSI display path is not part of the 40-pin GPIO signal map, but it is part of Phase 20 validation:

- connect the display data ribbon to the appropriate Raspberry Pi 5 DSI connector using the correct Pi 5-compatible ribbon/adapter for the panel
- power the display from the Pi 5 `5V` header pin only if the Waveshare wiring expects header power; use physical pin `2` for `5V` and a nearby `GND`
- do not connect display power to the `3.3V` logic rail
- do not hot-plug the display 5V line while the Pi is powered; Phase 18/19 showed display power transients can reset or destabilize the host
- keep the project I2C bus on `GPIO2/GPIO3`; the DSI touch/panel devices should appear on the DSI controller/mux path, not as extra devices on the project I2C bus

## Software Mapping

The expected software map remains:

| Software field | BCM GPIO | Physical pin |
| --- | --- | --- |
| `i2c_sda` | `2` | `3` |
| `i2c_scl` | `3` | `5` |
| `ads_alert` | `17` | `11` |
| `key_adc1_digital` | `27` | `13` |
| `key_led_digital` | `22` | `15` |
| `display_power_en` | `24` | `18` |
| `drive_center` | `5` | `29` |
| `drive_up` | `6` | `31` |
| `drive_down` | `13` | `33` |
| `drive_left` | `19` | `35` |
| `drive_right` | `26` | `37` |

If Phase 20 requires a different pin factory, set it in the systemd environment and record it in the execution record. Do not change these BCM assignments unless a Pi 5-specific conflict is measured and documented.

## Validation Checklist

- `i2cdetect -y 1` sees the ADS1115 on the project I2C bus at the expected address
- `ADS1115 ALERT/RDY` toggles or is observable on `GPIO17`
- `KEY_ADC1` and `KEY_LED` digital inputs read idle and active states correctly
- each drive GPIO actuates only its intended `JOG` direction
- no unused GPIO on the header is accidentally connected to the protoboard
- display touch/panel devices enumerate on the DSI path and do not collide with the project I2C bus
- host health snapshot shows no active under-voltage or throttling during sustained kiosk use

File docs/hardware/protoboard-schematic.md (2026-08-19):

# Phase 6 Protoboard Schematic

This note matches the KiCad schematic and names every active component explicitly.

[Hardware Reference](README.md) · [Raspberry Pi 5 GPIO schema](pi5-gpio-schema.md) · [Project README](../../README.md)

## Interfaces

### Monitor Harness `J1`

| Pin | Net |
| --- | --- |
| `1` | `GND` |
| `2` | `MON_KEY_ADC2` |
| `3` | `MON_KEY_ADC1` |
| `4` | `MON_KEY_LED` |

### Raspberry Pi Direct GPIO Wiring

There is no `J2` or `J3` header in this phase.

| Pi Function | Raspberry Pi Pin |
| --- | --- |
| `logic / ADC rail` | `3.3V`, physical pin `1` |
| `GND` | physical pin `6` |
| `I2C SDA` | `GPIO2`, physical pin `3` |
| `I2C SCL` | `GPIO3`, physical pin `5` |
| `ADS1115 ALERT/RDY` | `GPIO17`, physical pin `11` |
| `KEY_ADC1` input | `GPIO27`, physical pin `13` |
| `KEY_LED` input | `GPIO22`, physical pin `15` |
| `CENTER` drive | `GPIO5`, physical pin `29` |
| `UP` drive | `GPIO6`, physical pin `31` |
| `DOWN` drive | `GPIO13`, physical pin `33` |
| `LEFT` drive | `GPIO19`, physical pin `35` |
| `RIGHT` drive | `GPIO26`, physical pin `37` |
| `display_power_en` output (Phase 21) | `GPIO24`, physical pin `18` |
| `5V power rail for display branch` (Phase 21) | physical pin `2` |

Phase 6 Raspberry Pi pinout

## ADC Block

| Ref | Value | Connection |
| --- | --- | --- |
| `U1` | `ADS1115` | `AIN0 -> R20`, `SDA -> GPIO2`, `SCL -> GPIO3`, `ALERT/RDY -> GPIO17`, `VDD -> 3.3V`, `GND -> GND` |
| `R20` | `100 kOhm` | `MON_KEY_ADC2 -> ADS1115 AIN0` series isolation resistor |
| `C1` | `100 nF` | `3.3V` to `GND` near `U1` |
| `C2` | `1 uF` | `3.3V` to `GND` near `U1` |

`AIN1`, `AIN2`, and `AIN3` are unused in this phase. `ADDR` is strapped to `GND`.

`R20` was added after display bring-up exposed a power-sequencing defect: with the Pi off, the unpowered `ADS1115` input could load `MON_KEY_ADC2` and pull the monitor line near a valid key state. The `100 kOhm` series resistor prevents the unpowered ADC from disturbing the monitor. Bench check: with the Pi off, and even with Pi power disconnected, the monitor no longer sees a false `KEY_ADC2` action.

## Observation Channels

### `KEY_ADC1`

| Ref | Value | Connection |
| --- | --- | --- |
| `R1` | `100 kOhm` | `MON_KEY_ADC1 -> Q1 base` |
| `Q1` | `2N3904` | base from `R1`, collector (`C`) to `GPIO27`, emitter (`E`) to `GND` |
| `R2` | `10 kOhm` | `3.3V -> GPIO27` pull-up |

### `KEY_LED`

| Ref | Value | Connection |
| --- | --- | --- |
| `R3` | `100 kOhm` | `MON_KEY_LED -> Q2 base` |
| `Q2` | `2N3904` | base from `R3`, collector (`C`) to `GPIO22`, emitter (`E`) to `GND` |
| `R4` | `10 kOhm` | `3.3V -> GPIO22` pull-up |

## Drive Channels

Each drive channel uses:
- one GPIO net into a base resistor
- one `100 kOhm` base pull-down to `GND`
- one `2N3904` low-side transistor
- one action resistor between the monitor key line and the transistor collector

### Center

| Ref | Value | Connection |
| --- | --- | --- |
| `R5` | `4.7 kOhm` | `GPIO5 -> Q3 base` |
| `R15` | `100 kOhm` | `Q3 base -> GND` |
| `Q3` | `2N3904` | emitter `-> GND`, collector `-> R10` |
| `R10` | `22 Ohm` | `MON_KEY_ADC1 -> Q3 collector` |

### Up

| Ref | Value | Connection |
| --- | --- | --- |
| `R6` | `4.7 kOhm` | `GPIO6 -> Q4 base` |
| `R16` | `100 kOhm` | `Q4 base -> GND` |
| `Q4` | `2N3904` | emitter `-> GND`, collector `-> R11` |
| `R11` | `22 Ohm` | `MON_KEY_ADC2 -> Q4 collector` |

### Down

| Ref | Value | Connection |
| --- | --- | --- |
| `R7` | `4.7 kOhm` | `GPIO13 -> Q5 base` |
| `R17` | `100 kOhm` | `Q5 base -> GND` |
| `Q5` | `2N3904` | emitter `-> GND`, collector `-> R12` |
| `R12` | `3.3 kOhm` | `MON_KEY_ADC2 -> Q5 collector` |

### Left

| Ref | Value | Connection |
| --- | --- | --- |
| `R8` | `4.7 kOhm` | `GPIO19 -> Q6 base` |
| `R18` | `100 kOhm` | `Q6 base -> GND` |
| `Q6` | `2N3904` | emitter `-> GND`, collector `-> R13` |
| `R13` | `30 kOhm` | `MON_KEY_ADC2 -> Q6 collector` |

### Right

| Ref | Value | Connection |
| --- | --- | --- |
| `R9` | `4.7 kOhm` | `GPIO26 -> Q7 base` |
| `R19` | `100 kOhm` | `Q7 base -> GND` |
| `Q7` | `2N3904` | emitter `-> GND`, collector `-> R14` |
| `R14` | `10 kOhm` | `MON_KEY_ADC2 -> Q7 collector` |

## Display Power Control Block (Phase 21)

This block is added in Phase 21. It switches the display's 5V supply via a PNP high-side transistor driven by a GPIO-controlled NPN stage, with an RC soft-start network to limit inrush.

| Ref | Value | Connection |
| --- | --- | --- |
| `Q8` | `S8550` PNP | emitter → Pi 5V rail (pin 2), collector → `DISP_5V`, base → `R23`/`R24`/`C3` junction |
| `Q9` | `2N3904` NPN | base → `R21`, collector → `R24` → Q8 base junction, emitter → `GND` |
| `R21` | `1 kΩ` | `GPIO24` (physical pin 18) → Q9 base |
| `R22` | `10 kΩ` | Q9 base → `GND` (default-off pull-down; holds display off during boot and reset) |
| `R23` | `10 kΩ` | Pi 5V → Q8 base (default-off pull-up; keeps Q8 off when Q9 is off) |
| `R24` | `4.7 kΩ` | Q8 base junction → Q9 collector (base drive resistor; forms voltage divider with R23) |
| `C3` | `10 µF` electrolytic, + toward 5V | Pi 5V → Q8 base junction (soft-start: delays base pull-down, ramps collector current over ~100 ms, τ ≈ 32 ms) |
| `C4` | `100 µF` electrolytic, + toward display | `DISP_5V` → `GND` (bulk output capacitor; smooths load transients) |

### Net: `DISP_5V`

The display's 5V supply wire is disconnected from the Pi 5V header and reconnected to the `DISP_5V` node (Q8 collector). Display GND remains directly wired to Pi GND — only the 5V supply side is switched.

### GPIO24 logic

- **GPIO24 LOW** (boot default): Q9 off → Q8 base held at 5V by R23 → Q8 off → `DISP_5V` = 0 V → display unpowered.
- **GPIO24 HIGH**: Q9 saturated → Q8 base pulled to ~1.7 V via R23/R24 divider → Q8 on → `DISP_5V` rises to ~4.8 V (Vce(sat) ≈ 0.2 V drop).

## Important Interpretation

- The observation transistors `Q1` and `Q2` are simple inverting open-collector buffers into Pi GPIO: `C` goes to the GPIO input and `E` goes to `GND`.
- The drive transistors `Q3-Q7` do not source voltage onto the monitor lines.
- Each drive action connects a tested resistor leg to ground only when its GPIO is asserted.
- `ADS1115`, `I2C`, and Pi-facing pull-ups all stay on `3.3V`.

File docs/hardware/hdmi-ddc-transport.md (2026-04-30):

# Phase 5 HDMI And DDC Transport Design

## Purpose

This document records the selected transport direction for preserving practical `HDMI` use on the Samsung `CJ791` while still maintaining a reliable `DDC/CI` path for the controller.

It turns the Phase 5 transport brainstorming into a concrete project direction that later hardware phases can consume.

## Problem Statement

The project wants the controller to use `DDC/CI` over the monitor's `HDMI` path without permanently occupying that `HDMI` input.

The controller should be able to:

- read monitor state through `DDC/CI`
- send supported `DDC/CI` commands
- coexist with a normal external `HDMI` source
- preserve a stable user experience for that external source

At the same time, the connected computer should keep seeing behavior close to a normal monitor connection.

## Relevant HDMI Signals

The critical `HDMI` sideband signals for this phase are:

- `pin 15`: `DDC SCL`
- `pin 16`: `DDC SDA`
- `pin 17`: `DDC GND`
- `pin 18`: `+5V`
- `pin 19`: `HPD`

These lines matter because `DDC` is already used by the source and monitor for:

- `EDID`
- ordinary monitor-side `DDC/CI`
- other source/display coordination that may occur after initial connect

Practical direction notes for these lines:

- `pin 18` must be treated as both a source-presence signal and a controllable monitor-side presence input
- the controller should sense whether an external computer is presenting `+5V` on source-side `pin 18`
- the controller should also be able to present monitor-side `pin 18` from either the external source or a Pi-generated local `+5V` rail
- the project must not assume the monitor will answer `HDMI`-side `DDC` normally when no monitor-side `pin 18` `+5V` is present
- `pin 19` `HPD` is a monitor-to-source signal, so the clean default is pass-through plus Pi-side observation unless later testing proves active `HPD` conditioning is required

## Why Passive Tapping Is Rejected

A raw parallel connection between:

- source
- monitor
- Raspberry Pi controller

is not an acceptable final design.

Reasons:

- the source and monitor already assume ownership of the `DDC` bus
- the Pi would become an additional master on a live bus
- extra capacitance and stubs can degrade signal integrity
- uncontrolled multi-master behavior creates collision and retry risk
- failures could affect `EDID`, display bring-up, or later monitor communication

The issue is not just `I2C` addressing. The issue is uncontrolled shared ownership of an already-live `HDMI` control channel.

## Candidate Directions

### Candidate A: Passive Parallel DDC Tap

Attach the Pi directly to the same `DDC` wires used by the computer and monitor.

Decision:

- rejected for final design

Why:

- electrically risky
- protocol ownership is ambiguous
- too fragile for a production-worthy transport design

### Candidate B: Switched DDC Ownership

Only one controller talks to the monitor-side `DDC` bus at a time.

Normal model:

- external computer owns `DDC` during normal attached operation
- Pi remains electrically disconnected from monitor-side `DDC`
- Pi temporarily takes ownership only for short monitor transactions

Decision:

- selected as the core transport direction

Why:

- avoids uncontrolled shared-master behavior
- preserves a realistic path to custom hardware
- gives the Pi direct monitor access when needed
- keeps the design much simpler than a full `HDMI` proxy

### Candidate D: Attached Pi Listener/Slave Plus Temporary Source Disconnect

Keep the Pi attached to the live `DDC` bus during ordinary source-owned operation as an additional non-owning bus participant so it can observe traffic and detect idle without extra observation GPIOs.

Normal model:

- external computer remains the only `DDC` master during normal attached operation
- monitor remains the real target slave
- Pi remains attached in a listener or slave-capable role and may log traffic
- when the Pi needs a monitor transaction, hardware disconnects the external source from monitor-side `DDC`
- Pi then uses its own master-mode `I2C` interface to talk to the monitor
- after the short transaction, the source path is restored

Decision:

- selected for current Phase 5 exploration

Why:

- avoids extra GPIOs dedicated only to `SCL` / `SDA` idle observation
- allows the Pi to observe and log host-side `DDC` traffic for later learning
- preserves the rule that only one master owns monitor-side `DDC` at a time
- stays materially simpler than full monitor emulation

### Candidate C: Full HDMI Proxy Or Bridge

Insert hardware that behaves like a full `HDMI` intermediary, potentially managing `EDID`, `HPD`, and all `DDC` traffic in a fully active way.

Decision:

- rejected for the current project phase

Why:

- too complex for the current hardware plan
- would require specialized `HDMI` hardware beyond the current direction
- poor fit for a Raspberry Pi-centric control deck architecture

## Selected Direction

The selected Phase 5 direction is:

- attached Pi listener/slave plus temporary source disconnect for Pi-owned transactions
- preserve ordinary source access to monitor `EDID` over the normal path
- external-source `pin 18` presence sensing
- selectable monitor-side `pin 18` source: external pass-through or Pi-generated `+5V`
- plus careful `HPD` handling

Current implementation bias inside that direction:

- keep the Pi attached to the source-owned `DDC` bus in a non-owning listener or slave-capable role during normal operation
- use that attached Pi path to observe traffic and infer bus-idle state without extra dedicated `SCL` / `SDA` observation GPIOs
- when the Pi needs its own monitor transaction, disconnect the external source path from monitor-side `DDC`, then let the Pi act as master
- sense source-side `pin 18` to detect whether an external computer is attached
- allow the controller to drive monitor-side `pin 18` from a local regulated `+5V` rail when Pi-only `DDC` access is needed
- isolate the external source `+5V` path from the Pi-generated `+5V` path so they can never backfeed into each other
- treat `pin 18` as a small source-selection problem, not as a permanently fixed pass-through signal
- treat `pin 19` as direct monitor-to-source `HPD` pass-through with observation first
- only add active `HPD` conditioning or source-presence assist circuitry if later validation shows it is required

This is best described as a smart `HDMI` intermediary for the `DDC` and presence sideband signals, not as a passive tap and not as a full `HDMI` video proxy.

## Reference Diagram

Current transport concept diagram:

Phase 5 HDMI and DDC transport concept

The diagram shows:

- which `HDMI` pins pass through directly
- which sideband pins are intercepted or controlled
- the intended `DDC` ownership switch point
- the `HPD` and source / Pi-selected `+5V` handling blocks
- the Raspberry Pi control relationship to those blocks

## Design Intent

The final transport subsystem should provide these behaviors.

### Toward the external computer

It should preserve a usable monitor connection as much as practical without adding unnecessary transport complexity in this phase.

That means:

- the source should still be able to query the monitor's ordinary `EDID`
- `HPD` should not toggle unnecessarily
- normal display re-enumeration should be avoided during routine Pi monitor queries
- when an external source is attached, its `+5V` should remain the default monitor-side `pin 18` source unless the controller deliberately changes state

### Toward the monitor

The controller should be able to access the monitor-side `DDC` bus when needed.

That means:

- the Pi can temporarily own monitor-side `SCL` and `SDA`
- the Pi may remain attached to the source-owned `DDC` bus in a non-owning listener or slave-capable role during normal operation
- Pi monitor transactions should be short and explicit
- the computer and Pi should not both be active as masters on monitor-side `DDC` at the same time
- the controller may need to present monitor-side `pin 18` from a local `+5V` source when no external computer is attached
- Pi takeover should only occur after the source-owned `DDC` bus appears idle

## Required Subsystems

The transport design now assumes the need for these functional blocks:

- source-side `HDMI` connector interface
- monitor-side `HDMI` connector interface
- attached Pi `DDC` interface that can remain present during source-owned operation
- source-path disconnect or ownership-switch hardware for temporary Pi master transactions
- source-side `pin 18` presence sensing
- local regulated `+5V` generation for optional monitor-side `pin 18` assertion
- `pin 18` source-selection and backfeed-isolation hardware
- `HPD` handling or controlled pass-through path
- Raspberry Pi control interface for selecting `DDC` ownership

This means the long-term hardware design is not just "add an `HDMI` connector to the main controller board." It needs a defined sideband-transport strategy.

## PCB Design Approach

The Phase 5 PCB should be designed as a deliberate sideband-transport board, not as an autorouted generic breakout.

Selected PCB-design approach:

- place `HDMI source` and `HDMI monitor` connectors side by side on the same external board edge
- keep the Raspberry Pi control header on the opposite side of the board
- route the high-speed `HDMI` pass-through pins as short, direct connector-to-connector connections with minimal interruption
- route only the controlled sideband signals through the active circuitry:
  - `DDC SCL`
  - `DDC SDA`
  - `pin 18 +5V`
  - `pin 19 HPD`
- treat the board as a mixed-criticality layout:
  - direct pass-through for the untouched `HDMI` lines
  - deliberate manual escape routing for the sideband and control nets
- prefer solid copper reference planes and short fanout paths over long stitched ground traces
- use at least a 2-layer board, with permission to move to 4 layers if routing quality or return-path quality demands it

Explicit Phase 5 rule:

- do not rely on generic autorouting or AI-generated routing as the design method for this board

Why:

- the board combines dense `HDMI` connector geometry with a small number of intentionally intercepted sideband nets
- the routing priorities are architectural, not just net-completion oriented
- careless auto-generated routing can easily create shorts, poor connector escapes, and misleadingly "complete" boards that are not manufacturable

So the expected implementation method is:

- manual placement
- manual routing strategy
- DRC-driven cleanup
- explicit review of connector escape quality and sideband net ownership paths

## Expected Operating States

### State 1: No external computer attached

- Pi presents monitor-side `pin 18` from the local regulated `+5V` source
- Pi owns monitor-side `DDC`
- Pi may query the monitor freely
- Pi may issue supported `DDC/CI` commands

This state assumes the monitor will treat the locally presented `pin 18` `+5V` as sufficient presence for `HDMI`-side `DDC`. That remains a validation target until tested on the actual unit.

### State 2: External computer attached, normal operation

- external source `+5V` is detected on source-side `pin 18`
- external source `+5V` is the default monitor-side `pin 18` source
- computer owns monitor-side `DDC`
- Pi remains attached in a non-owning listener or slave-capable role and may observe traffic
- `EDID` and `HPD` remain stable for the computer

### State 3: Pi temporary control transaction

- monitor-side `pin 18` remains valid from the selected source
- the external source path is disconnected from monitor-side `DDC`
- Pi temporarily owns monitor-side `DDC` as master
- Pi performs a short query or command
- the external source path is restored

This state should be used sparingly. The project should not assume aggressive polling while a normal source is attached.

### State 4: Source-selection conflict or fault

- external-source `+5V` and Pi-generated `+5V` must never be tied together
- hardware defaults should prevent backfeed even if firmware is misconfigured
- on ambiguous state or fault, the transport should prefer isolating the two `+5V` sources over trying to preserve a guessed operating mode

## Practical Rules

The selected transport direction implies these design rules:

- do not rely on passive parallel multi-master `DDC`
- do not assume `EDID` is only read once at startup
- do not toggle `HPD` casually
- do not poll monitor `DDC` aggressively while an external computer is attached
- keep Pi `DDC` ownership windows short
- prefer monitor queries on demand rather than continuous high-rate monitoring over shared `HDMI`
- treat source `pin 18` sensing and monitor-side `pin 18` source selection as separate functions
- never allow Pi-generated `+5V` to backfeed into the external source
- keep the monitor-side `pin 18` source-selection logic explicit rather than implicit
- treat `SCL` and `SDA` as a controlled pair during source disconnect and Pi master takeover
- treat `DDC` bus idle as `SCL = high` and `SDA = high`
- require a bus-idle determination before Pi takeover
- assume the bus may be busy whenever either `SCL` or `SDA` is low
- use temporary source disconnect and master ownership control, not Pi-side monitor emulation, to avoid source/Pi communication conflicts

## DDC Takeover Rules

The current Phase 5 communication-arbitration rule is:

- the external computer is the default `DDC` owner whenever attached
- the Pi may remain attached to the live bus in a non-owning listener or slave-capable role during source-owned operation
- the Pi may only take monitor-side `DDC` for short, explicit transactions after the external source path is disconnected
- the Pi must not emulate the monitor or answer computer-side `DDC` requests in this phase

Practical bus-idle interpretation:

- idle bus: `SCL = high` and `SDA = high`
- potentially busy bus: either `SCL` or `SDA` low

Recommended Pi takeover sequence:

1. detect that an external source is attached if source-side `pin 18` is present
2. observe or infer source-bus idle from the attached Pi listener/slave role
3. wait until the source-owned bus appears idle
4. disconnect the external source path from monitor-side `DDC`
5. let the Pi act as master for one short query or command
6. restore the external source path

Important limitation:

- seeing both lines high means the bus is currently idle, but it does not guarantee the source will not begin a new transaction immediately after that observation
- Pi takeover should therefore be treated as a deliberate, brief interruption window rather than as perfectly cooperative arbitration
- the viability of an attached Pi listener or slave-capable role still depends on clean electrical behavior and reliable bus-role transition under Raspberry Pi OS

## Proposed Electrical Architecture

The current Phase 5 electrical direction is a sideband-only intermediary that leaves the `HDMI` high-speed video lanes untouched and only intervenes on:

- `DDC SCL`
- `DDC SDA`
- `pin 18` `+5V`
- `pin 19` `HPD`
- `GND`

This is not a full `HDMI` repeater or proxy. It is a controlled sideband transport board.

### Electrical Design Goals

The electrical schematic should satisfy these rules:

- the external computer must be the default `DDC` owner when attached
- the Pi must talk only to the real monitor, not emulate it
- the Pi `I2C` domain must not be directly exposed to a raw `HDMI/DDC` voltage domain without proper interfacing
- the monitor-side `DDC` bus must connect to only one master at a time
- source-side `pin 18` and Pi-generated `pin 18` must never backfeed each other
- loss of Pi software control should fall back to a safe source-owned state whenever possible

### DDC Electrical Topology

The preferred schematic shape is:

1. source-side `HDMI` connector exposes `SCL_SRC` and `SDA_SRC`
2. monitor-side `HDMI` connector exposes `SCL_MON` and `SDA_MON`
3. Pi-side `I2C` exposes `SCL_PI_3V3` and `SDA_PI_3V3`
4. Pi-side `I2C` passes through a bidirectional level-translation stage to create a Pi-owned `DDC`-compatible side
5. during normal operation, the translated Pi `DDC` path remains attached to the live `DDC` bus in a non-owning listener or slave-capable role
6. a controlled source-disconnect function can temporarily isolate the external source path from monitor-side `DDC` so the Pi can act as master

Functionally:

- source-owned state:
  - `SCL_SRC -> SCL_MON`
  - `SDA_SRC -> SDA_MON`
  - Pi translated `DDC` path remains attached for observation or slave-capable presence, but is not the active master

- Pi-owned state:
  - source path to monitor-side `DDC` is disconnected
  - Pi translated `SCL -> SCL_MON`
  - Pi translated `SDA -> SDA_MON`

This means the design uses explicit source disconnect and Pi master takeover rather than a strict two-fully-detached-masters mux as the primary architecture.

### Why Level Translation Is Included

The Pi-side `I2C` bus is a `3.3V` domain. `HDMI/DDC` must be treated as a separate bus domain whose pull-up and electrical expectations are not assumed to be safely Pi-native.

So the Phase 5 electrical direction is:

- no direct Pi GPIO connection to raw `HDMI` `SCL` / `SDA`
- include a bidirectional `I2C`-appropriate level-translation stage on the Pi path
- place ownership switching on the translated `DDC` side, not directly on raw Pi GPIO pins

This keeps the Pi electrically conservative and avoids baking an unsafe single-voltage assumption into the design.

### DDC Switch Requirements

The `DDC` control block should meet these functional requirements:

- allow the Pi to remain attached during source-owned operation without becoming the active master
- disconnect the external source path from monitor-side `DDC` when the Pi needs master ownership
- treat `SCL` and `SDA` as a coordinated pair during disconnect and reconnect
- present low added capacitance and low on-resistance
- tolerate open-drain bidirectional signaling cleanly
- default to the external-source path when unpowered or when the controller is not actively taking ownership

The preferred class of part is therefore:

- an `I2C`-appropriate disconnect or bus-control element that can isolate the source path cleanly during Pi-owned transactions

The preferred class is not:

- passive parallel wiring
- a generic logic mux chosen without regard to open-drain bus behavior
- Pi-driven monitor emulation hardware

### Source Presence And Monitor-Side `+5V`

The `pin 18` electrical path should be drawn as two different functions.

#### 1. Source-presence sense

Source-side `pin 18` should feed a high-impedance sense path toward the controller logic.

That sense path should:

- detect whether an external computer is attached and powered enough to present `+5V`
- avoid materially loading the source
- preferably expose a clean logic-level signal to the Pi through a divider, comparator, or protected sense input

#### 2. Monitor-side `+5V` source select

Monitor-side `pin 18` should come from exactly one of:

- external-source `pin 18`
- Pi-generated regulated `+5V`

The schematic should therefore include:

- a local regulated `+5V` source
- explicit source-selection or ideal-diode / power-mux behavior
- backfeed blocking between the two sources
- current limiting or fault protection on the Pi-generated path

Preferred default behavior:

- if external `pin 18` is present and no override is active, the monitor sees the external source `+5V`
- if no external `pin 18` is present and Pi-only `DDC` mode is requested, the monitor may see Pi-generated `+5V`

### `HPD` Electrical Direction

For this phase, `pin 19` `HPD` should remain electrically simple:

- default pass-through from monitor to source
- optional observation by the controller
- no active synthesis or gating required in the base schematic unless later testing proves it necessary

That keeps the initial Phase 5 electrical schema focused on `DDC` ownership and `pin 18` presence handling.

### Suggested Schematic Blocks

The Phase 5 schematic should be organized into these blocks:

- `HDMI Source Connector`
- `HDMI Monitor Connector`
- `TMDS/CEC Pass-Through`
- `Attached Pi DDC Interface`
- `Source DDC Disconnect Control`
- `Pi I2C Level Translation`
- `Source +5V Presence Detect`
- `Monitor +5V Source Select`
- `HPD Pass-Through And Observe`
- `Pi Control GPIO And Status Inputs`
- `Power Regulation And Protection`

### Recommended Default States

Hardware defaults matter as much as software policy.

Recommended defaults:

- `DDC_SOURCE_PATH = CONNECTED`
- `MONITOR_5V_SEL = SOURCE` when external source `+5V` is present
- Pi-generated `+5V` disabled by default
- `HPD` direct pass-through by default

In practical terms, if the controller is reset, unconfigured, or crashed, the safest behavior is:

- external computer still sees the monitor as normally as possible
- Pi loses active control first
- conflicting `+5V` drive is prevented in hardware, not merely by firmware

### Protection And Support Components

The Phase 5 electrical schema should reserve room for at least:

- ESD protection appropriate for the `HDMI` sideband lines
- current limiting or load-switch protection on Pi-generated `+5V`
- pull-up strategy review on the Pi side of the level translator
- optional weak pull or bias resistors that enforce safe switch defaults at boot
- optional test points for:
  - source-side `SCL`
  - source-side `SDA`
  - monitor-side `SCL`
  - monitor-side `SDA`
  - source-side `pin 18`
  - monitor-side `pin 18`
  - `HPD`

### Current Recommendation

The current recommended Phase 5 schematic direction is:

- leave high-speed `HDMI` lanes as direct pass-through
- keep the Pi attached to the live `DDC` bus through an `I2C`-appropriate translated interface during normal source-owned operation
- implement Pi transactions by temporarily disconnecting the external source path from monitor-side `DDC`
- insert bidirectional level translation between Pi `3.3V` `I2C` and the attached `DDC` path
- sense source-side `pin 18`
- provide Pi-generated regulated `+5V` for optional monitor-side presence
- use explicit source selection and backfeed blocking for monitor-side `pin 18`
- keep `HPD` as pass-through plus observation in the base design

This gives the project a realistic electrical schematic target without turning Phase 5 into a full display-emulation design.

## Alternative Deferred Architecture

The main alternative kept in reserve is a stricter pure ownership-switch design:

- the Pi is electrically detached from monitor-side `DDC` during normal source-owned operation
- source-side `SCL` and `SDA` are the only lines connected to the monitor in normal operation
- Pi uses separate observation or GPIO-based sensing to determine bus-idle state
- when the Pi needs a transaction, a dedicated 2:1 `DDC` switch or mux moves monitor-side `DDC` ownership from source to Pi

Why it remains a valid fallback:

- it keeps the Pi electrically absent from the live monitor bus until needed
- it reduces dependence on Pi slave or listener behavior under Linux
- it may be electrically easier to reason about if the attached-listener approach proves noisy or awkward

Why it is not the current first-choice path:

- it consumes extra observation resources if clean idle detection is still required
- it gives up the opportunity to log ordinary host `DDC` traffic directly
- it is less aligned with the current desire to learn from live `DDC` traffic before finalizing the transport design

## Current Development Compromise

For development, a temporary sacrificial `HDMI` path is still acceptable.

That remains only a development compromise. It is not the approved final-system assumption.

## Deferred Detailed Decisions

Phase 5 selects the direction, but does not yet fully lock:

- exact `DDC` switch or mux part family
- exact `pin 18` source-selection implementation
- exact current-limit and fault-protection strategy for Pi-generated `+5V`
- whether `HPD` is passed through, buffered, gated, or selectively synthesized
- exact timing rules for Pi ownership takeover and release
- how much disruption a short Pi takeover causes on a real attached computer
- whether the transport should live on the integrated controller board or on a separate intermediary board

## Descoped Complexity

Dedicated `EDID` emulation was considered and intentionally descoped from Phase 5.

Reason:

- it adds extra hardware and routing complexity beyond the immediate goal
- the current phase goal is monitor `DDC` access without unsafe passive bus sharing
- the external source should still be allowed to query the monitor's own `EDID` through the normal path

## Verification Direction For Later Phases

Later implementation should verify:

- external computer can still query the monitor's `EDID`
- ordinary display bring-up works through the intermediary
- Pi can take monitor-side `DDC` ownership and successfully complete short transactions
- the monitor answers `HDMI`-side `DDC` when no external computer is attached and monitor-side `pin 18` is driven from the Pi-generated `+5V` source
- source-side `pin 18` presence sensing is reliable and does not materially load the external source
- `pin 18` source selection does not backfeed or otherwise disturb the external computer
- takeover and release do not cause unacceptable display re-enumeration
- `HPD` behavior remains stable during normal operation
- the monitor's practical `HDMI` input remains usable for a real external source

## Outcome

Phase 5 now approves a clear hardware direction:

- not a passive `DDC` tap
- not permanent `HDMI` sacrifice as a final-system assumption
- not a full active `HDMI` proxy
- yes to switched `DDC` ownership with ordinary monitor `EDID` still reachable by the source, external `pin 18` presence sensing, selectable monitor-side `pin 18` source ownership, and careful `HPD` handling

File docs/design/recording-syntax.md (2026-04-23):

# Recording Syntax

This document defines the Phase 16 recording file syntax used by the Pi deck macro system.

## Purpose

Recording files are the portable representation of an observed hardware interaction sequence.

The recorder captures real observation-bus semantics:

- `hold`
- `release`
- `delay`
- `led`
- `wait_led`
- `wait_ddc`

The recorder does not invent higher-level actions such as `click center`.

## File Shape

Current files use version `V1`.

```json
{
  "name": "recording_2026-04-16_21-42-49",
  "version": "V1",
  "source": "observation",
  "created_at": "2026-04-16T21:42:49Z",
  "updated_at": "2026-04-16T21:43:02Z",
  "events": [
    { "type": "hold", "action": "center" },
    { "type": "delay", "duration_ms": 88 },
    { "type": "release", "action": "center" },
    {
      "type": "led",
      "active": true,
      "blocking": false
    }
  ]
}
```

## Top-Level Fields

- `name`
  Human-facing recording name. Used as the default filename stem.
- `version`
  Syntax version. Current value: `V1`.
- `source`
  Capture origin. Current value: `observation`.
- `created_at`
  Recording creation timestamp in ISO-8601 UTC form.
- `updated_at`
  Last modification timestamp in ISO-8601 UTC form.
- `events`
  Ordered list of executable macro events.

## Event Semantics

### `hold`

Represents an observed press start for a JOG action.

```json
{ "type": "hold", "action": "left" }
```

Allowed `action` values:

- `up`
- `down`
- `left`
- `right`
- `center`

### `release`

Represents an observed press end for a JOG action.

```json
{ "type": "release", "action": "left" }
```

### `delay`

Represents elapsed time between two semantic events.

```json
{ "type": "delay", "duration_ms": 120 }
```

Notes:

- The recorder does not persist the initial setup delay before the first captured event.
- Internal timing between recorded events is preserved.
- `duration_ms` is derived from explicit event timing, so removing a leading delay reduces the recording length.
- If a macro intentionally needs an initial wait before doing anything, add a leading `delay` event manually to the JSON file.

## Timing Guidance

Observed on the Samsung CJ791 JOG hardware during Phase 16 validation:

- **Minimum hold duration:** 50 ms. Holds shorter than 50 ms are not reliably registered by the monitor firmware.
- **Minimum delay between events:** 50 ms. Delays shorter than 50 ms between a release and the next hold risk the firmware treating them as a single gesture or missing the second input.

The recorder's internal threshold (`_MIN_DELAY_MS = 25 ms`) only controls whether a delay event is emitted in the file; it does not guarantee the monitor will respond. Always use at least 50 ms for any delay intended to separate two distinct inputs.

When editing recordings manually, use 50 ms as the lower bound for any `delay.duration_ms` value that separates a `release` from the next `hold`. Shorter values are syntactically valid but may produce unreliable playback on the monitor.

### `led`

Represents an observed LED state transition from the observation bus.

```json
{
  "type": "led",
  "active": true,
  "blocking": false
}
```

Notes:

- normal recorded LED observations should use `blocking: false`
- this preserves the observed cue without blocking later events
- if a macro needs LED-gated continuation, set `blocking: true` and provide timeout settings
- `led` should be the default form used by the recorder for observed `KEY_LED` changes

### `wait_led`

Blocks playback until the observed LED state matches the requested condition.

```json
{
  "type": "wait_led",
  "match": { "active": false },
  "poll_interval_ms": 50,
  "timeout_ms": 1800
}
```

Important:

- `led` is the normal recorded observation event for LED changes.
- `wait_led` is an observation gate.
- It does not command the hardware LED to blink or change state.
- It only blocks until the observed LED state matches the expected condition or times out.

## LED Rules

The LED rules for Phase 16 are:

- LED changes should be recorded as observation events.
- Recorded LED changes should not block later events by default.
- LED does not represent an output command channel.
- The system must never interpret recorded LED events as instructions to drive the monitor LED.
- Blocking LED behavior is explicit, not implied.

That means:

- use `led` for normal recorded LED state changes
- use `wait_led` when a macro step must pause until a target LED state is observed
- or set `blocking: true` on a `led` event when editing a recording and you want that specific LED event to behave as a gate

## When To Use `wait_led`

Use `wait_led` only when the next event must not continue until LED feedback reaches a known state.

Good uses:

- waiting for an LED cue that indicates an input transition has settled
- pausing until the monitor returns to an idle LED state
- synchronizing a later action to a known LED feedback moment

Bad uses:

- recording every LED change as a blocking wait
- treating LED events as if they were commands
- adding `wait_led` when the sequence can safely continue without it

In short:

- `led` preserves observation
- `wait_led` enforces synchronization

### `wait_ddc`

Reserved for future DDC synchronization gates.

```json
{
  "type": "wait_ddc",
  "match": {},
  "poll_interval_ms": 100,
  "timeout_ms": 2000
}
```

Phase 16 does not execute `wait_ddc` on the live hardware path yet.

## Recording Rules

- The recorder captures observation-bus events, not inferred gestures.
- Pre-held inputs present when recording starts are ignored.
- The first persisted event is the first real semantic event seen after recording begins.
- Initial user hesitation before starting the sequence is intentionally not stored as a leading delay.
- A tap is represented as:
  `hold` -> optional `delay` -> `release`

## Editing Guidance

Manual JSON edits are allowed for advanced use.

Safe edits include:

- renaming `name`
- adding an initial `delay`
- adjusting intermediate `delay.duration_ms`
- changing an observed `led` event to `blocking: true` when a macro should wait on LED
- changing or removing `wait_led` gates

Unsafe edits include:

- mismatching `hold` and `release` pairs
- using unsupported `action` values
- introducing invalid timestamps or negative durations

## Compatibility

- New files are written with `version: "V1"`.
- Older numeric `version: 1` files are accepted for compatibility with files that predate the string format.

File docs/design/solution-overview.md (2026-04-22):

# Solution Overview

## Summary

The proposed solution is a Raspberry Pi-based local control deck for the Samsung `CJ791` monitor. It combines:

- a touch-first web UI
- a local backend service
- custom interface hardware for `JOG` emulation and signal observation
- `DDC/CI` readback and supported direct controls
- file-based sequence recording and replay

The design is intentionally built around the monitor behavior that has already been measured and verified:

- `JOG` input is required for OSD-driven workflows
- `DDC/CI` is useful for feedback and selected direct controls, but not for full OSD control
- front-panel `LED` behavior may provide additional feedback cues

## Design goals

- preserve the original monitor `JOG` behavior and hardware usability
- provide a usable touch controller for daily monitor control
- support LAN access through the same UI used on the deck
- allow low-level control, recording, replay, and later feature productization from recorded sequences
- keep the runtime simple enough for Raspberry Pi `2 B` hardware
- document the hardware design deeply enough to support PCB and circuit implementation

## Target implementation platform

This design phase is explicitly targeting the following implementation platform:

- Raspberry Pi `2 B v1.1`
- `1280×800` capacitive touch display (7" DSI deck panel)
- Raspberry Pi OS Lite or equivalent terminal-only base image
- Chromium kiosk runtime
- `systemd` process supervision

This is an implementation choice for this project phase, not a product-level requirement.

## System model

Conceptually, the system looks like this:

`Touch UI / LAN UI -> backend API and websocket service -> monitor control services -> hardware interface + DDC adapter -> Samsung CJ791`

The system has four major technical areas:

- UI and application control
- monitor-control logic
- custom hardware interface
- host platform and kiosk runtime

## Functional control model

### 1. JOG-driven monitor control

The monitor's OSD-driven features are controlled through `JOG` behavior, not by direct software commands.

This means the system must support:

- low-level directional and center actions
- press and hold timing
- sequence replay
- sequence recording for later cleanup and reuse

This also means higher-level monitor features such as input switching and `PiP` configuration must be built on top of measured and verified `JOG` sequences.

### 2. DDC-assisted feedback

`DDC/CI` is used where it has already proven useful:

- current input readback
- brightness control
- volume control
- power-state related investigation
- general monitor readback

Input switching remains a cycling problem, not a direct-selection problem:

- `Thunderbolt -> HDMI -> DisplayPort -> Thunderbolt -> ...`

So `DDC` is mainly used to know when to stop cycling.

### 3. LED-assisted feedback

The front-panel `KEY_LED` line is treated as another feedback source.

It may help:

- confirm input changes
- distinguish idle versus active behavior
- reveal some OSD boundary conditions

The design should capture and expose this information, but should avoid overstating what the LED means before it has been fully characterized.

## Operating modes

The monitor-control model explicitly supports three operating modes:

### JOG mode

Used for raw low-level monitor control.

Characteristics:

- direct `up`, `down`, `left`, `right`, and `center` actions
- press and hold timing
- useful for investigation, recovery, and direct manual low-level operation
- remains available even after higher-level workflows are added

### DDC mode

Used when `DDC` readback is available and trustworthy.

Characteristics:

- current input is known
- source cycling can stop on the correct state
- `PiP` workflows can be simplified using feedback
- UI can expose target-oriented controls

### Blind mode

Used when `DDC` is unavailable, incomplete, or untrusted.

Characteristics:

- the user provides current and desired input state
- workflows assume `OSD closed` as the baseline
- source changes and `PiP` control are blind `JOG`-driven sequences
- UI must expose a `from -> to` workflow rather than pretend direct selection exists

## UI design approach

### One UI, two access patterns

There is only one UI:

- it runs locally on the deck in kiosk mode
- it is also accessible from other devices on the same trusted LAN

There is no separate deck product and remote product. The same screens and workflows are used in both cases.

### UI evolution by phase

The monitor-control UI should evolve in stages:

- early phases: raw `JOG` controller only
- after validated JSON-backed workflows exist: richer monitor features built on those workflows
- later phases: full user-facing `DDC` mode and `Blind` mode controls

This prevents the project from presenting fake higher-level controls before the underlying monitor behavior has actually been proven.

### Display target

The current design target is the `Waveshare 7inch DSI LCD (E)` (`7"`, `1280x800`, capacitive touch, `DSI`).

The UI should remain responsive for other screen sizes, but the layout and interaction density should be optimized for the selected deck display first.

#### Minimum font size

The panel is ~215 PPI at 7 inches. Viewed at ~50 cm desk distance, the comfortable legibility threshold is approximately **24 px physical**. At the validated kiosk configuration (Chromium via Xwayland at 1:1 scale, `html { font-size: 20px }`), this maps to **1.2 rem**.

**1.2 rem is the enforced minimum font size for all readable UI text on this panel.** This was validated on the physical display during Phase 19 and applies to all components — labels, values, buttons, log content, metadata, and widget text. Elements that are intentionally non-readable (e.g. decorative badges, OSD mock simulation) are exempt.

Implementation anchors:
- `html { font-size: 20px }` — sets 1 rem = 20 px physical at 1:1 Xwayland scale
- `font-weight: 500` on `:root` — improves stroke visibility on the high-PPI panel
- Chromium launched with `--ozone-platform=x11` (Xwayland) — enables subpixel (LCD) font rendering, which native Wayland disables
- fontconfig RGB subpixel rendering enabled via `10-sub-pixel-rgb.conf` (installed by `scripts/host/install_pi_deck_kiosk_autostart.sh`)

### Deck shell and widget geometry

The deck is a **single-screen appliance**, not a marketing site, portal, or landing page: content stays **contained in the viewport** with no gratuitous page chrome.

Monitor control, logs, and future widgets are **deck widgets** (each has a stable `data-widget` id for future layout). **Geometry is fixed by default:** reserved regions do not grow or shrink because another widget’s content changed — that would break muscle memory. The live log scrolls **inside** its band; it does not steal space from the JOG surface. **Optional show/hide** of a widget is an explicit user (or settings) action, not an implicit side effect of log volume.

### Screen model

The UI should be organized around these areas:

- main monitor control area
- dashboard area with live/local widgets
- advanced/settings area
- live log area

The advanced/settings area should include:

- recording controls
- replay tools
- sequence management
- theme and preference controls
- status and debugging information that is useful during development and bring-up

### Visual interaction direction

The UI should take inspiration from the Stream Deck style of interaction:

- icon-driven controls
- large, easy-to-press buttons
- quick visual recognition of primary actions

At the same time, the layout should remain flexible rather than forcing every element into identical button tiles.

That means:

- primary monitor controls should be large and easy to hit
- supporting widgets such as clock and calendar do not need to consume the same amount of space as primary controls
- the screen should be used intentionally based on function, not by giving every panel equal weight

### First usable controller

The first usable controller should be a direct `JOG` console:

- `up`
- `down`
- `left`
- `right`
- `center`
- press and hold support on each button
- visible feedback when a command succeeds or fails
- live log output
- recording controls in the advanced/settings area

This first controller is not the end state of the product. It is the first functional control surface from which reusable monitor features can be developed.

In the early phases, this raw `JOG` controller should be the only monitor-control UI exposed.

Only after validated sequence files exist should the UI grow into the richer feature model discussed elsewhere in the design.

Even after higher-level controls are added, the raw `JOG` controller should remain available behind a manual-control entry point for investigation, recovery, and direct low-level use.

## Sequence recording and replay design

### Purpose

Recorded sequences are central to the project.

They allow:

- exploration of unknown OSD workflows
- cleanup and editing after recording
- promotion of validated recordings into named product features
- timing refinement after capture

### Recording source

Recording observes the bus itself, not only commands sent by the app.

That means both:

- app-generated control actions
- physical monitor `JOG` actions

can become part of a recording.

### Sequence abstraction level

Sequences should be stored at the logical action layer, not at the low-level analog bus layer.

So recordings should represent things like:

- `hold`
- `release`
- `delay`
- `wait_led`
- `wait_ddc`

and not expose internal bus wiring details such as `KEY_ADC1` or `KEY_ADC2`.

The runtime is responsible for mapping those logical actions into:

- bus/channel selection
- resistor-state reproduction
- `DDC` readback and interpretation

### Format

The canonical sequence format should be `JSON`.

Reasons:

- ordered arrays preserve event sequence
- easy parsing and validation
- easy file-based storage
- easy editing and later extension

Each recording should include:

- metadata
- ordered events
- `DDC` status snapshots or normalized status checks where useful
- `LED` wait events where the next event should not continue until a matching `LED` cue is observed
- `DDC` wait or check events with retry interval and timeout behavior
- optional annotations for later cleanup

Event behavior should support:

- logical hold and release actions
- delays
- `LED`-triggered continuation as a blocking wait, not an LED output command
- `DDC` status checks and `DDC` wait loops
- configurable polling interval where repeated checks are needed
- timeout-based failure when an expected `LED` or `DDC` state never arrives

If the last event completes without timeout failure, the sequence is considered successful.

A representative shape for the recording model is:

```json
{
  "name": "enable-pip",
  "version": "V1",
  "description": "Open OSD and enable PiP from OSD-closed state",
  "events": [
    {
      "type": "hold",
      "action": "center"
    },
    {
      "type": "delay",
      "duration_ms": 120
    },
    {
      "type": "release",
      "action": "center"
    },
    {
      "type": "delay",
      "duration_ms": 180
    },
    {
      "type": "wait_led",
      "match": {
        "pattern": "blink"
      },
      "poll_interval_ms": 50,
      "timeout_ms": 1500
    },
    {
      "type": "hold",
      "action": "left"
    },
    {
      "type": "delay",
      "duration_ms": 100
    },
    {
      "type": "release",
      "action": "left"
    },
    {
      "type": "delay",
      "duration_ms": 120
    },
    {
      "type": "wait_ddc",
      "match": {
        "input": "HDMI"
      },
      "poll_interval_ms": 200,
      "timeout_ms": 5000
    }
  ]
}
```

This example is illustrative rather than final code, but it captures the intended abstraction:

- actions remain logical rather than bus-specific
- waits are explicit event types
- timeout semantics are implicit: if a wait times out, the sequence fails

User-created recordings should live in a writable local directory.
Shipped validated sequences should live in the repository and be versioned with the code.

### Productization flow

Expected lifecycle:

1. record a raw sequence
2. inspect and clean it up
3. adjust timing if needed
4. rename it to a meaningful workflow name
5. ship it as part of an implemented feature

Example:

`recording_2026-03-23-21-55-35.json -> cleanup -> enable-pip.json`

## Runtime architecture

### Repository structure

The project should be structured like this:

```text
pi-deck/
  frontend/
  backend/
  docs/
  hardware/
```

### Production process model

Production should use:

- one backend process
- one frontend build artifact
- backend serving the built frontend
- websocket support from the backend

This reduces runtime complexity on Raspberry Pi `2 B`.

### Backend internal layers

Even though production uses a single backend process, the backend code should be layered clearly:

- API layer
- application/service layer
- hardware integration layer
- storage layer

Suggested conceptual structure:

```text
backend/
  api/
  services/
  hardware/
  storage/
  models/
```

Recommended responsibilities:

- `api`: REST endpoints, websocket endpoints, request validation, and response shaping
- `services`: command arbitration, sequence execution, monitor workflow logic, and widget/service orchestration
- `hardware`: `jog_drive`, `jog_observe`, `led_observe`, `ddc`, and `display_power`
- `storage`: recordings, settings, and other local persisted files
- `models`: typed domain objects, validation models, and error types

### Chosen stack

- Backend: `Python`
- Backend framework: `FastAPI`
- Frontend: `React`
- Frontend language: `TypeScript`
- Frontend build tool: `Vite`
- API style: `REST` + `WebSocket`
- Process supervision: `systemd`
- Kiosk browser: `Chromium`
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

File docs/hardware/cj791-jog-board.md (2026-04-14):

# CJ791 JOG Board Notes

## Scope

This document records the current hardware observations for the Samsung `LC34J791WTNXZA / CJ791` front-panel `JOG` control path.

## Monitor information

Target monitor:

- model: `Samsung LC34J791WTNXZA`
- marketing name: `Samsung CJ791`
- panel size: `34-inch ultrawide curved`
- resolution: `3440x1440`
- inputs: `HDMI`, `DisplayPort`, `Thunderbolt 3 / USB-C`
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

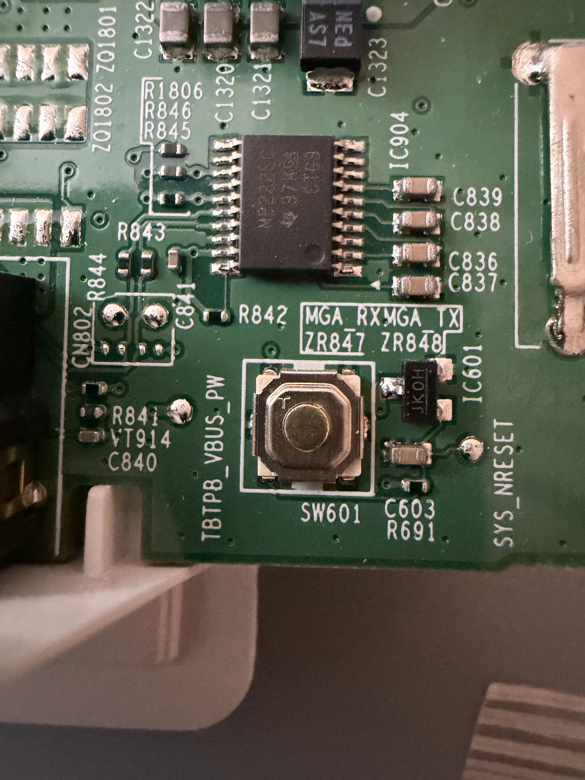
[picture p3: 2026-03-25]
docs/assets/hardware/cj791-pushbutton-close.jpg

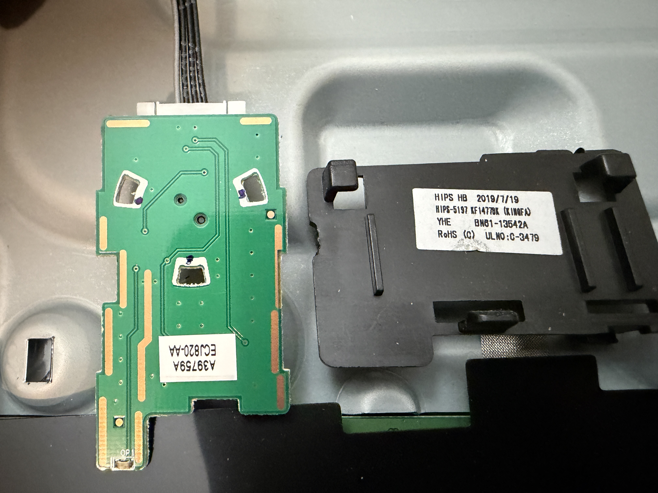
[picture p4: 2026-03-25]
docs/assets/hardware/cj791-joystick-back.jpg

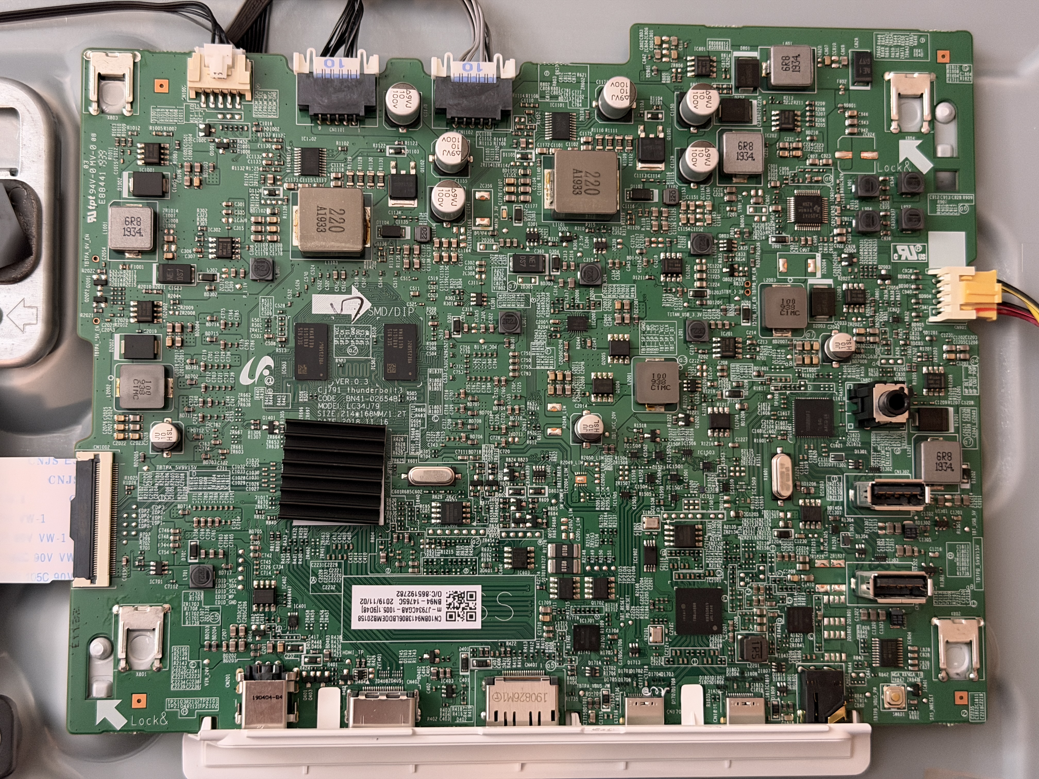
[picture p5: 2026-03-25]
docs/assets/hardware/cj791-mainboard-full.jpg

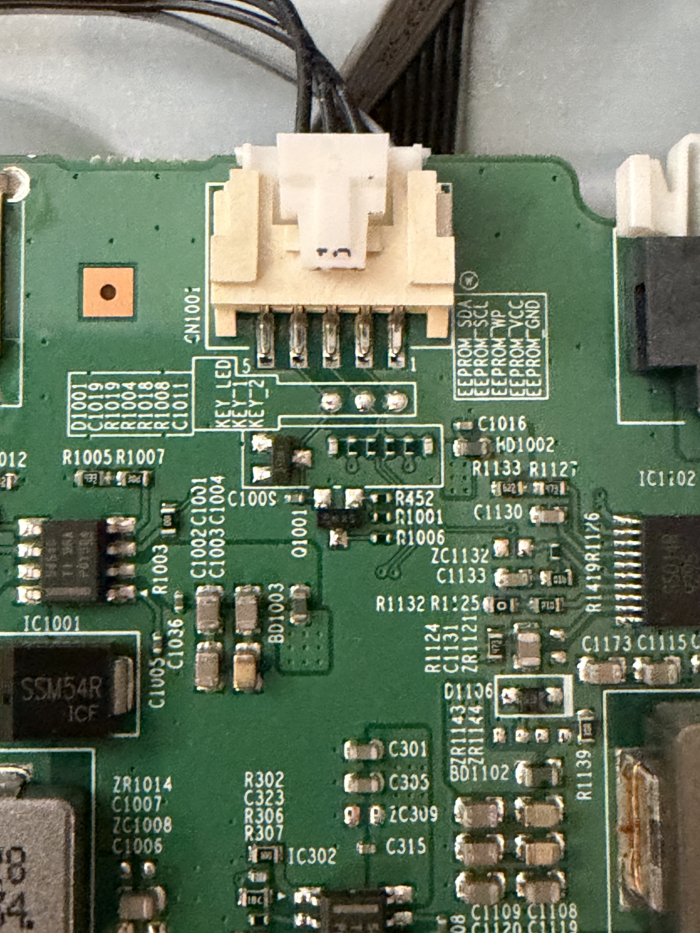
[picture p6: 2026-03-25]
docs/assets/hardware/cj791-joystick-board-connection.jpg

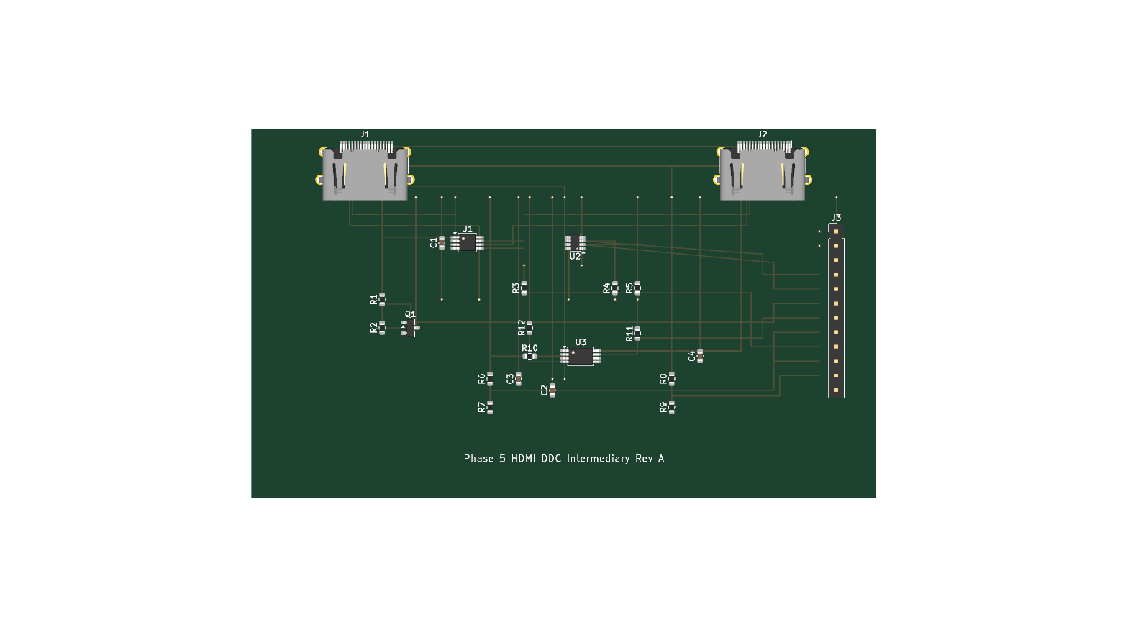
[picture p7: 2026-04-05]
hardware/kicad/hdmi-ddc-intermediary/hdmi-ddc-intermediary-top.png

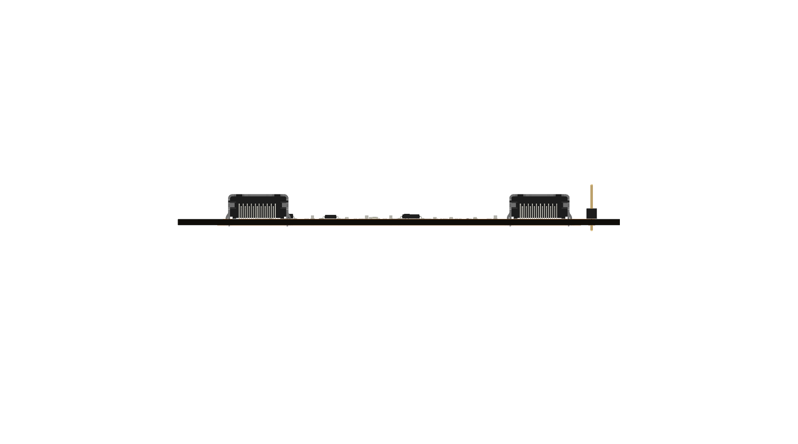
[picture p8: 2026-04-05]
hardware/kicad/hdmi-ddc-intermediary/hdmi-ddc-intermediary-front.png

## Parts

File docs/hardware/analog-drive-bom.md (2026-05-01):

# Phase 4 Analog Drive BOM

## Purpose

This BOM defines the selected component direction and default passive values for `Phase 4: Analog Drive Circuit Design`.

It covers only the analog drive subcircuit for reproducing `JOG` resistance states on `KEY_ADC1` and `KEY_ADC2`.

## BOM Artifact

A JLC-oriented CSV BOM is tracked at:

- [`hardware/kicad/analog-drive/analog-drive.bom.csv`](../../hardware/kicad/analog-drive/analog-drive.bom.csv)

This markdown BOM is the review-friendly version; the CSV is the fabrication-oriented artifact used for PCB ordering and assembly preparation.

## Selected Core Parts

| RefDes | Qty | Part | Package | Purpose | JLCPCB / LCSC | Notes |
| --- | --- | --- | --- | --- | --- | --- |
| `U1` | 1 | `MC74HC4066ADTR2G` | `TSSOP-14` | `KEY_ADC2` per-leg analog switch bank | `C233537` | JLC-orderable prototype choice; higher on-resistance than the original LV4066A target, but retained to keep the board fully orderable |
| `U2` | 1 | `74LVC1G66LT05ARCQ` | `SOT-23-5` | `KEY_ADC1` center pull-down gating | `C46553572` | JLC-orderable single analog switch for the center path |

## Default Passive Values

| RefDes | Qty | Value | JLCPCB / LCSC | Notes |
| --- | --- | --- | --- | --- |
| `R1` | 1 | `30 kOhm` | `C2889371` | `KEY_ADC2_LEFT` tested commercial value; exact JLC match is currently low stock, so verify before ordering |
| `R2` | 1 | `10 kOhm` | `C5362358` | `KEY_ADC2_RIGHT` tested commercial value |
| `R3` | 1 | `3.3 kOhm` | `C3017726` | `KEY_ADC2_DOWN` tested commercial value |
| `R4` | 1 | `22 Ohm` | — | `KEY_ADC2_UP` tested commercial value; LCSC part number to be confirmed for 22 Ohm 0402 |
| `R6` | 1 | `22 Ohm` | — | `KEY_ADC1_CENTER` tested commercial value; LCSC part number to be confirmed for 22 Ohm 0402 |
| `R7-R11` | 5 | `100 kOhm`, `1%` | `C25803` | default-off bias for all five control nets |
| `C1-C2` | 2 | `100 nF`, `X7R` | `C14663` | local decoupling at `U1` and `U2` |
| `C3` | 1 | `1 uF`, `X5R/X7R` | `C15849` | local bulk decoupling on `3.3V` |

## Interface And Assembly Notes

| RefDes | Qty | Part / Type | Purpose |
| --- | --- | --- | --- |
| `J1` | 1 | `1x3` monitor-drive header | `KEY_ADC1`, `KEY_ADC2`, `GND` to the monitor-side harness; through-hole, manual assembly |
| `J2` | 1 | `1x7` host-control header | `CENTER_EN`, `UP_EN`, `DOWN_EN`, `RIGHT_EN`, `LEFT_EN`, `GND`, `3.3V`; through-hole, manual assembly |

## PCB Outcome

- the phase-4 KiCad PCB is now a routed compact prototype board in [`hardware/kicad/analog-drive/analog-drive.kicad_pcb`](../../hardware/kicad/analog-drive/analog-drive.kicad_pcb)
- KiCad successfully exports front-side placement CSV, gerbers, and 3D board renders from the board file
- standard KiCad 3D models are now attached to the board footprints for connectors, ICs, passives, and capacitors
- `kicad-cli pcb drc` still crashes in this environment with a KiCad `10.0.0` macOS CLI runtime error, so final clearance review still needs an interactive KiCad GUI pass before ordering

## Channel Allocation

### `MC74HC4066ADTR2G` (`U1`)

- four independent channels connect `KEY_ADC2` to four dedicated resistor legs toward `GND`
- each directional resistor leg has its own enable input
- all channels remain isolated unless their specific enable line is asserted

### `74LVC1G66LT05ARCQ` (`U2`)

- toggles `KEY_ADC1` center resistor leg to `GND`
- defaults to open/high-impedance when not enabled

## Current Design Intent

- controller never sources voltage onto monitor lines
- controller only switches resistance-to-ground states
- default inactive state is high-impedance on both driven channels
- each switch enable line has a hardware default-off bias resistor
- software still enforces one action at a time, but the hardware default state is already safe before firmware starts

## Remaining Risks

- `U1` is now JLC-orderable, but it is a `74HC4066`-class part rather than the original lower-on-resistance `LV4066A` target, so final bench confirmation on the assembled board is still required
- the selected `30 kOhm` JLC resistor is currently a low-stock listing; if it disappears, swap to a validated stocked alternative before release
- final connector family and keyed harness choice still belongs to the integrated-board phase
- final PCB sign-off is still pending a successful GUI DRC pass because the CLI DRC path is currently unreliable in this environment

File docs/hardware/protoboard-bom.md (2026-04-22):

# Phase 6 Protoboard BOM

## Parts

Each row is grouped by identical part/value, so `Qty` is the total count for that part family.

| Refs | Qty | Part | Value / Use |
| --- | --- | --- | --- |
| `U1` | `1` | `ADS1115` breakout | `KEY_ADC2` ADC, powered from `3.3V` |
| `Q1-Q7` | `7` | `2N3904` | `Q1-Q2` observe, `Q3-Q7` drive |
| `C1` | `1` | capacitor | `100 nF` |
| `C2` | `1` | capacitor | `1 uF` |
| `R1, R3, R15-R20` | `8` | resistor | `100 kOhm` |
| `R2, R4, R14` | `3` | resistor | `10 kOhm` |
| `R5-R9` | `5` | resistor | `4.7 kOhm` |
| `R10-R11` | `2` | resistor | `22 Ohm` |
| `R12` | `1` | resistor | `3.3 kOhm` |
| `R13` | `1` | resistor | `30 kOhm` |
| `J1` | `1` | `1x4` header | monitor harness |

## Raspberry Pi Wiring

| Function | Pi Pin |
| --- | --- |
| `3.3V` | physical pin `1` |
| `GND` | physical pin `6` |
| `SDA` | `GPIO2`, physical pin `3` |
| `SCL` | `GPIO3`, physical pin `5` |
| `ALERT/RDY` | `GPIO17`, physical pin `11` |
| `KEY_ADC1` input | `GPIO27`, physical pin `13` |
| `KEY_LED` input | `GPIO22`, physical pin `15` |
| `CENTER` | `GPIO5`, physical pin `29` |
| `UP` | `GPIO6`, physical pin `31` |
| `DOWN` | `GPIO13`, physical pin `33` |
| `LEFT` | `GPIO19`, physical pin `35` |
| `RIGHT` | `GPIO26`, physical pin `37` |

## Harness

| `J1` Pin | Net |
| --- | --- |
| `1` | `GND` |
| `2` | `MON_KEY_ADC2` |
| `3` | `MON_KEY_ADC1` |
| `4` | `MON_KEY_LED` |

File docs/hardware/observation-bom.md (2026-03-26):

# Phase 3 Observation BOM

## Purpose

This BOM defines the selected parts and default passive values for `Phase 3: Bus Observation Circuit Design`.

It covers only the observation subcircuit:

- `KEY_ADC1` buffered digital observation
- `KEY_ADC2` analog observation
- `KEY_LED` buffered observation with digital interpretation
- local support components needed for this subcircuit

It does not define the final integrated controller-board connectors, board outline, or GPIO assignment. Those belong to later phases.

## Selected Core Parts

| RefDes | Qty | Part | Package | Purpose | Notes |
| --- | --- | --- | --- | --- | --- |
| `U1` | 1 | `TLV9064IDR` | `SOIC-14` | Quad high-input-impedance observation buffer | Channels allocated to `KEY_ADC2`, `KEY_ADC1`, `KEY_LED`, and one spare |
| `U2` | 1 | `ADS1114IDGST` | `VSSOP-10` | 16-bit I2C ADC for analog `KEY_ADC2` observation | `ALERT/RDY` should be routed to the host for interrupt-assisted sampling |
| `U3` | 1 | `74LVC1G17GW` | `SOT-353` | Schmitt-trigger buffer for `KEY_ADC1` digital interpretation | Powered from `3.3V` |
| `U4` | 1 | `74LVC1G17GW` | `SOT-353` | Schmitt-trigger buffer for `KEY_LED` digital interpretation | Powered from `3.3V` |

## Default Passive Values

| RefDes | Qty | Value | Notes |
| --- | --- | --- | --- |
| `R1` | 1 | `10 kOhm`, `1%` | Series resistor on `KEY_ADC2` observation input |
| `R2` | 1 | `10 kOhm`, `1%` | Series resistor on `KEY_ADC1` observation input |
| `R3` | 1 | `10 kOhm`, `1%` | Series resistor on `KEY_LED` observation input |
| `R4` | 1 | `4.7 kOhm`, `1%` | `I2C` pull-up from `SDA` to `3.3V` |
| `R5` | 1 | `4.7 kOhm`, `1%` | `I2C` pull-up from `SCL` to `3.3V` |
| `C1` | 1 | `100 nF`, `X7R` | Local decoupling at `U1` |
| `C2` | 1 | `100 nF`, `X7R` | Local decoupling at `U2` |
| `C3` | 1 | `100 nF`, `X7R` | Local decoupling at `U3` |
| `C4` | 1 | `100 nF`, `X7R` | Local decoupling at `U4` |
| `C5` | 1 | `1 uF`, `X7R` | Local bulk decoupling on `3.3V` rail near analog front end |
| `C6` | 1 | `1 nF`, `DNP` | Optional noise filter footprint for `KEY_ADC2` after bench validation |
| `C7` | 1 | `1 nF`, `DNP` | Optional noise filter footprint for `KEY_ADC1` after bench validation |
| `C8` | 1 | `1 nF`, `DNP` | Optional noise filter footprint for `KEY_LED` after bench validation |

## Interface Placeholders

These are temporary Phase 3 placeholders so the observation subcircuit can be reviewed and prototyped. Final connector selection belongs to the integrated-board phase.

| RefDes | Qty | Part / Type | Purpose |
| --- | --- | --- | --- |
| `J1` | 1 | `1x4` temporary observation header | `GND`, `KEY_ADC2`, `KEY_ADC1`, `KEY_LED` from monitor side |
| `J2` | 1 | `1x7` temporary host header | `3.3V`, `GND`, `SDA`, `SCL`, `ADC_ALERT`, `KEY1_IN_GPIO`, `LED_IN_GPIO` to host |
| `TP1-TP7` | 7 | test points | `KEY_ADC2_BUF`, `KEY_ADC1_BUF`, `KEY_LED_BUF`, `SDA`, `SCL`, `ADC_ALERT`, `3.3V` |

## Channel Allocation

### `TLV9064IDR`

- `U1A`: `KEY_ADC2` buffer
- `U1B`: `KEY_ADC1` buffer
- `U1C`: `KEY_LED` buffer
- `U1D`: spare channel for debug, later conditioning, or future observation needs

### `ADS1114IDGST`

- `AINP`: `KEY_ADC2_BUF`
- `AINN`: `GND` for single-ended use
- `ADDR`: tie to `GND` for the default `I2C` address unless later integration needs a different address
- `ALERT/RDY`: route to host GPIO or test point for interrupt-assisted observation

### `74LVC1G17GW`

- `U3`: `KEY_ADC1_BUF` -> `KEY1_IN_GPIO`
- `U4`: `KEY_LED_BUF` -> `LED_IN_GPIO`

## Current Design Intent

- `KEY_ADC2` stays analog through the op-amp buffer and into the ADC
- `KEY_ADC1` is buffered first and then converted into a clean digital input through `U3`
- `KEY_LED` is buffered first and then converted into a clean digital input through `U4`
- software classifies `KEY_ADC2` analog ranges later, while `KEY_ADC1` and `KEY_LED` are treated as digital states after thresholding
- optional RC filters are intentionally `DNP` until bench noise proves they are needed

## Open Items For Later Phases

- final connector families
- final GPIO pin assignment
- final integrated board outline and mechanical features
- whether extra line protection beyond the current series-resistor strategy is required after bench testing
- whether `KEY_LED` needs any threshold tweaks after prototype validation

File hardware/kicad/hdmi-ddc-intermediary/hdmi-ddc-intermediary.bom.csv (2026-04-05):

Refs | Qty | Value | Footprint | Manufacturer | MPN | JLCPCB Part | Assembly | Notes
J1,J2 | 2 | HDMI_A | Connector_Video:HDMI_A_Amphenol_10029449-x01xLF_Horizontal | Amphenol ICC | 10029449-111RLF | C427307 | SMT | Source and monitor HDMI receptacles
J3 | 1 | PI_HOST_CTRL | Connector_PinHeader_2.54mm:PinHeader_1x12_P2.54mm_Vertical | Generic | PinHeader_1x12_P2.54mm |  | Manual | Pi host/control header
U1 | 1 | TCA4307DGKR | Package_SO:MSOP-8_3x3mm_P0.65mm | Texas Instruments | TCA4307DGKR | C880333 | SMT | Source-side DDC hot-swap buffer and disconnect element
U2 | 1 | PCA9306DCTR | Package_TO_SOT_SMD:SOT-23-8 | Texas Instruments | PCA9306DCTR | C123752 | SMT | Pi-side bidirectional I2C level translator attached to the live DDC bus
U3 | 1 | TPS2113APWR | Package_SO:TSSOP-8_4.4x3mm_P0.65mm | Texas Instruments | TPS2113APWR | C130052 | SMT | Monitor-side HDMI pin 18 source mux with enable and status
Q1 | 1 | 2N7002 | Package_TO_SOT_SMD:SOT-23 | TECH PUBLIC | 2N7002 | C28646312 | SMT | Open-drain pull-down for TCA4307 EN
R1,R2,R6,R7,R8,R9,R10,R11 | 8 | 100k | Resistor_SMD:R_0603_1608Metric | Yageo | RC0603FR-07100KL | C25803 | SMT | Sense dividers, pull networks, VSNS programming
R3 | 1 | 10k | Resistor_SMD:R_0603_1608Metric | TyoHM | RMC_0603_10K_JN | C5362358 | SMT | READY pull-up
R4,R5 | 2 | 4.7k | Resistor_SMD:R_0603_1608Metric | Yageo | RC0603FR-074K7L | C99782 | SMT | Pi-side I2C pull-ups
R12 | 1 | 1k | Resistor_SMD:R_0603_1608Metric | Yageo | RC0603FR-071KL | C22548 | SMT | TPS2113A ILIM set resistor
C1,C2,C3,C4 | 4 | 100n | Capacitor_SMD:C_0603_1608Metric | Samsung Electro-Mechanics | CL10B104KA8NNNC | C14663 | SMT | Local decoupling and pin 18 rail bypass

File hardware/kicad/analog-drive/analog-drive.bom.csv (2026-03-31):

Refs | Qty | Value | Footprint | Manufacturer | MPN | JLCPCB Part | Assembly | Notes
U1 | 1 | MC74HC4066ADTR2G | Package_SO:TSSOP-14_4.4x5mm_P0.65mm | onsemi | MC74HC4066ADTR2G | C233537 | SMT | JLC-orderable quad analog switch; higher on-resistance than LV4066A but acceptable for the tested prototype target set
U2 | 1 | 74LVC1G66LT05ARCQ | Package_TO_SOT_SMD:SOT-23-5 | GR | 74LVC1G66LT05ARCQ | C46553572 | SMT | JLC-orderable single analog switch for KEY_ADC1 center path
J1 | 1 | MONITOR_DRIVE | Connector_PinHeader_2.54mm:PinHeader_1x03_P2.54mm_Vertical | Generic | PinHeader_1x03_P2.54mm |  | Manual | Through-hole header; fit during manual assembly
J2 | 1 | HOST_CTRL | Connector_PinHeader_2.54mm:PinHeader_1x07_P2.54mm_Vertical | Generic | PinHeader_1x07_P2.54mm |  | Manual | Through-hole header; fit during manual assembly
R1 | 1 | 30k | Resistor_SMD:R_0603_1608Metric | VO | 0603 1% 30K | C2889371 | SMT | Exact tested value; low-stock JLC option, verify before order
R2 | 1 | 10k | Resistor_SMD:R_0603_1608Metric | TyoHM | RMC_0603_10K_JN | C5362358 | SMT | Exact tested value
R3 | 1 | 3.3k | Resistor_SMD:R_0603_1608Metric | VO | SCR0603J3K3 | C3017726 | SMT | Exact tested value
R4 | 1 | 22k | Resistor_SMD:R_0603_1608Metric | TE Connectivity | CRGCQ0603F22K | C4223986 | SMT | Exact tested value
R6 | 1 | 22k | Resistor_SMD:R_0603_1608Metric | TE Connectivity | CRGCQ0603F22K | C4223986 | SMT | Exact tested value
R7,R8,R9,R10,R11 | 5 | 100k | Resistor_SMD:R_0603_1608Metric | Yageo | RC0603FR-07100KL | C25803 | SMT | Default-off control pull-down resistors
C1,C2 | 2 | 100n | Capacitor_SMD:C_0603_1608Metric | Samsung Electro-Mechanics | CL10B104KA8NNNC | C14663 | SMT | Local decoupling
C3 | 1 | 1u | Capacitor_SMD:C_0603_1608Metric | Samsung Electro-Mechanics | CL10A105KB8NNNC | C15849 | SMT | 3V3 bulk decoupling

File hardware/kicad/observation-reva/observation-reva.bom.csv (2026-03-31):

Refs | Value | Footprint | Qty | DNP
C1 | 100n | Capacitor_SMD:C_0402_1005Metric | 1
C2 | 100n | Capacitor_SMD:C_0402_1005Metric | 1
C3 | 100n | Capacitor_SMD:C_0402_1005Metric | 1
C4 | 100n | Capacitor_SMD:C_0402_1005Metric | 1
C5 | 1u | Capacitor_SMD:C_0402_1005Metric | 1
C6 | 1n | Capacitor_SMD:C_0402_1005Metric | 1
C7 | 1n | Capacitor_SMD:C_0402_1005Metric | 1
C8 | 1n | Capacitor_SMD:C_0402_1005Metric | 1
J1 | MONITOR_INPUT | Connector_PinHeader_2.54mm:PinHeader_1x04_P2.54mm_Vertical | 1
J2 | HOST_IF | Connector_PinHeader_2.54mm:PinHeader_1x07_P2.54mm_Vertical | 1
J3 | SPARE_IF | Connector_PinHeader_2.54mm:PinHeader_1x02_P2.54mm_Vertical | 1
R1 | 10k 1% | Resistor_SMD:R_0402_1005Metric | 1
R2 | 10k 1% | Resistor_SMD:R_0402_1005Metric | 1
R3 | 10k 1% | Resistor_SMD:R_0402_1005Metric | 1
R4 | 4.7k 1% | Resistor_SMD:R_0402_1005Metric | 1
R5 | 4.7k 1% | Resistor_SMD:R_0402_1005Metric | 1
R6 | 0 | Resistor_SMD:R_0402_1005Metric | 1
R7 | 0 | Resistor_SMD:R_0402_1005Metric | 1
TP8 | U1D_IN | TestPoint:TestPoint_Pad_D1.0mm | 1
TP9 | U1D_OUT | TestPoint:TestPoint_Pad_D1.0mm | 1
U1 | TLV9064IDR | Package_SO:SOIC-14_3.9x8.7mm_P1.27mm | 1
U2 | ADS1115IDGSR | Package_SO:MSOP-10_3x3mm_P0.5mm | 1
U3 | 74LVC1G17GW | Package_TO_SOT_SMD:SOT-353_SC-70-5 | 1
U4 | 74LVC1G17GW | Package_TO_SOT_SMD:SOT-353_SC-70-5 | 1

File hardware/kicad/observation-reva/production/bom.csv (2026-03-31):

Designator | Footprint | Quantity | Value | LCSC Part #
C1, C2, C3, C4 | 0402 | 4 | 100n | C307331
C5 | 0402 | 1 | 1u | C52923
C6, C7, C8 | 0402 | 3 | 1n | C1588
R1, R2, R3 | 0402 | 3 | 10k 1% | C25744
R4, R5 | 0402 | 2 | 4.7k 1% | C25900
R6, R7 | 0402 | 2 | 0 | C17168
U1 | SOIC-14_3.9x8.7mm_P1.27mm | 1 | TLV9064IDR | C388176
U2 | MSOP-10_3x3mm_P0.5mm | 1 | ADS1115IDGSR | C37593
U3, U4 | SOT-353_SC-70-5 | 2 | 74LVC1G17GW | C426705

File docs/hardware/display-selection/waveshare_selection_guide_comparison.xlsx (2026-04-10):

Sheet: Selection Guide
Waveshare Selection Guide extracted from uploaded HTML
Extracted from | 7inch-DSI-LCD-H.htm
Rows | 161
Generated | 2026-04-07
Section | PartNumber | Resolution | Display Port | Display Panel | View Angle | Touch Type | Touch Port | Toughened Glass Panel | Optical Bonding | Speaker | Signal Output | Pi | JETSON NANO | PC | Source Page Used For Extraction
SPI DISPLAYS | 2.8inch RPi LCD (A) | 320×240 | SPI | TFT | – | Resistive | SPI | No | No | No | No | Yes | No | No | Uploaded HTML: 7inch-DSI-LCD-H.htm
SPI DISPLAYS | 3.2inch RPi LCD (B) | 320×240 | SPI | TFT | – | Resistive | SPI | No | No | No | No | Yes | No | No | Uploaded HTML: 7inch-DSI-LCD-H.htm
SPI DISPLAYS | 3.5inch RPi LCD (A) | 480×320 | SPI | TFT | – | Resistive | SPI | No | No | No | No | Yes | No | No | Uploaded HTML: 7inch-DSI-LCD-H.htm
SPI DISPLAYS | 3.5inch RPi LCD (B) | 480×320 | SPI | IPS | 160° | Resistive | SPI | No | No | No | No | Yes | No | No | Uploaded HTML: 7inch-DSI-LCD-H.htm
SPI DISPLAYS | 3.5inch RPi LCD (C) | 480×320 | High-Speed SPI | TFT | – | Resistive | SPI | No | No | No | No | Yes | No | No | Uploaded HTML: 7inch-DSI-LCD-H.htm
SPI DISPLAYS | 3.5inch RPi LCD (F) | 320×480 | SPI | IPS | 170° | Capacitive | I2C | Yes | No | No | No | Yes | No | No | Uploaded HTML: 7inch-DSI-LCD-H.htm
SPI DISPLAYS | 3.5inch RPi LCD (G) | 320×480 | SPI | IPS | 170° | Resistive | SPI | No | No | No | No | Yes | No | No | Uploaded HTML: 7inch-DSI-LCD-H.htm
SPI DISPLAYS | 4inch RPi LCD (A) | 480×320 | SPI | TFT | – | Resistive | SPI | No | No | No | No | Yes | No | No | Uploaded HTML: 7inch-DSI-LCD-H.htm
DPI DISPLAYS | 2.8inch DPI LCD | 480×640 | DPI | IPS | 160° | Capacitive | I2C | Yes | Yes | No | No | Yes | No | No | Uploaded HTML: 7inch-DSI-LCD-H.htm
DPI DISPLAYS | 3.5inch DPI LCD | 640×480 | DPI | IPS | 170° | Capacitive | I2C | Yes | No | No | No | Yes | No | No | Uploaded HTML: 7inch-DSI-LCD-H.htm
DPI DISPLAYS | 4inch DPI LCD (C) | 720×720 | DPI | IPS | 170° | Capacitive | I2C | Yes | Yes | No | No | Yes | No | No | Uploaded HTML: 7inch-DSI-LCD-H.htm
DPI DISPLAYS | 5inch DPI LCD | 800×480 | DPI | IPS | 160° | – | – | No | No | No | No | Yes | No | No | Uploaded HTML: 7inch-DSI-LCD-H.htm
DPI DISPLAYS | 7inch DPI LCD | 1024×600 | DPI | IPS | 170° | – | – | No | No | No | No | Yes | No | No | Uploaded HTML: 7inch-DSI-LCD-H.htm
DSI DISPLAYS | 2.8inch DSI LCD | 480×640 | DSI | IPS | 160° | Capacitive | I2C | Yes | Yes | No | No | Yes | No | No | Uploaded HTML: 7inch-DSI-LCD-H.htm
DSI DISPLAYS | 3.4inch DSI LCD (C) | 800×800 | DSI | IPS | 170° | Capacitive | I2C | Yes | Yes | No | No | Yes | No | No | Uploaded HTML: 7inch-DSI-LCD-H.htm
DSI DISPLAYS | 3.4-DSI-TOUCH-C | 800×800 | DSI | IPS | 170° | Capacitive | I2C | Yes | Yes | No | No | Yes | No | No | Uploaded HTML: 7inch-DSI-LCD-H.htm
DSI DISPLAYS | 3.5inch DSI LCD (E) | 640×480 | DSI | IPS | 170° | Capacitive | I2C | Yes | No | No | No | Yes | No | No | Uploaded HTML: 7inch-DSI-LCD-H.htm
DSI DISPLAYS | 3.5inch DSI LCD (H) | 480×800 | DSI | IPS | 170° | Capacitive | I2C | Yes | No | No | No | Yes | No | No | Uploaded HTML: 7inch-DSI-LCD-H.htm
DSI DISPLAYS | 4inch DSI LCD | 480×800 | DSI | IPS | 170° | Capacitive | I2C | Yes | Yes | No | No | Yes | No | No | Uploaded HTML: 7inch-DSI-LCD-H.htm
DSI DISPLAYS | 4inch DSI LCD (C) | 720×720 | DSI | IPS | 170° | Capacitive | I2C | Yes | Yes | No | No | Yes | No | No | Uploaded HTML: 7inch-DSI-LCD-H.htm
DSI DISPLAYS | 4-DSI-TOUCH-C | 720×720 | DSI | IPS | 170° | Capacitive | I2C | Yes | Yes | No | No | Yes | No | No | Uploaded HTML: 7inch-DSI-LCD-H.htm
DSI DISPLAYS | 4.3inch DSI LCD | 800×480 | DSI | IPS | 160° | Capacitive | I2C | Yes | No | No | No | Yes | No | No | Uploaded HTML: 7inch-DSI-LCD-H.htm
DSI DISPLAYS | 4.3inch DSI LCD (with case) | 800×480 | DSI | IPS | 160° | Capacitive | I2C | Yes | No | No | No | Yes | No | No | Uploaded HTML: 7inch-DSI-LCD-H.htm
DSI DISPLAYS | 4.3inch DSI QLED | 800×480 | DSI | IPS(QLED) | 160° | Capacitive | I2C | Yes | No | No | No | Yes | No | No | Uploaded HTML: 7inch-DSI-LCD-H.htm
DSI DISPLAYS | 5inch DSI LCD | 800×480 | DSI | TFT | – | Capacitive | I2C | Yes | No | No | No | Yes | No | No | Uploaded HTML: 7inch-DSI-LCD-H.htm
DSI DISPLAYS | 5inch DSI LCD (B) | 800×480 | DSI | IPS | 160° | Capacitive | I2C | Yes | No | No | No | Yes | No | No | Uploaded HTML: 7inch-DSI-LCD-H.htm
DSI DISPLAYS | 5inch DSI LCD (C) | 1024×600 | DSI | IPS | 178° | Capacitive | I2C | Yes | No | No | No | Yes | No | No | Uploaded HTML: 7inch-DSI-LCD-H.htm
DSI DISPLAYS | 5inch DSI LCD (D) | 720×1280 | DSI | IPS | 178° | Capacitive | I2C | Yes | Yes | No | No | Yes | No | No | Uploaded HTML: 7inch-DSI-LCD-H.htm
DSI DISPLAYS | 5-DSI-TOUCH-A | 720×1280 | DSI | IPS | 178° | Capacitive | I2C | Yes | Yes | No | No | Yes | No | No | Uploaded HTML: 7inch-DSI-LCD-H.htm
DSI DISPLAYS | 5-DSI-TOUCH-B | 720×1280 | DSI | IPS | 178° | Capacitive | I2C | Yes | Yes | No | No | Yes | No | No | Uploaded HTML: 7inch-DSI-LCD-H.htm
DSI DISPLAYS | 5inch Raspberry Pi Touch Display 2 | 720×1280 | DSI | IPS | 160° | Capacitive | I2C | No | No | No | No | Yes | No | No | Uploaded HTML: 7inch-DSI-LCD-H.htm
DSI DISPLAYS | 6.25inch DSI LCD | 720×1560 | DSI | IPS | 178° | Capacitive | I2C | Yes | Yes | No | No | Yes | No | No | Uploaded HTML: 7inch-DSI-LCD-H.htm
DSI DISPLAYS | 7inch DSI LCD | 800×480 | DSI | TFT | – | Capacitive | I2C | Yes | No | No | No | Yes | No | No | Uploaded HTML: 7inch-DSI-LCD-H.htm
DSI DISPLAYS | 7inch DSI LCD (with case A) | 800×480 | DSI | TFT | – | Capacitive | I2C | Yes | No | No | No | Yes | No | No | Uploaded HTML: 7inch-DSI-LCD-H.htm
DSI DISPLAYS | 7inch DSI LCD (with cam) | 800×480 | DSI | TFT | – | Capacitive | I2C | Yes | No | No | No | Yes | No | No | Uploaded HTML: 7inch-DSI-LCD-H.htm
DSI DISPLAYS | 7inch DSI LCD (with cam and case) | 800×480 | DSI | TFT | – | Capacitive | I2C | Yes | No | No | No | Yes | No | No | Uploaded HTML: 7inch-DSI-LCD-H.htm
DSI DISPLAYS | 7inch DSI LCD (B) | 800×480 | DSI | IPS | 170° | Capacitive | I2C | Yes | No | No | No | Yes | No | No | Uploaded HTML: 7inch-DSI-LCD-H.htm
DSI DISPLAYS | 7inch DSI LCD (B) (with case A) | 800×480 | DSI | IPS | 170° | Capacitive | I2C | Yes | No | No | No | Yes | No | No | Uploaded HTML: 7inch-DSI-LCD-H.htm
DSI DISPLAYS | 7inch DSI LCD (C) | 1024×600 | DSI | IPS | 170° | Capacitive | I2C | Yes | No | No | No | Yes | No | No | Uploaded HTML: 7inch-DSI-LCD-H.htm
DSI DISPLAYS | 7inch DSI LCD (C) (with case A) | 1024×600 | DSI | IPS | 170° | Capacitive | I2C | Yes | No | No | No | Yes | No | No | Uploaded HTML: 7inch-DSI-LCD-H.htm
DSI DISPLAYS | 7inch DSI LCD (E) | 1280×800 | DSI | IPS | 178° | Capacitive | I2C | Yes | Yes | No | No | Yes | No | No | Uploaded HTML: 7inch-DSI-LCD-H.htm
DSI DISPLAYS | 7-DSI-TOUCH-A | 720×1280 | DSI | IPS | 170° | Capacitive | I2C | Yes | Yes | No | No | Yes | No | No | Uploaded HTML: 7inch-DSI-LCD-H.htm
DSI DISPLAYS | 7-DSI-TOUCH-C | 1024×600 | DSI | IPS | 170° | Capacitive | I2C | No | No | No | No | Yes | No | No | Uploaded HTML: 7inch-DSI-LCD-H.htm
DSI DISPLAYS | 7inch DSI LCD (H) | 1280×720 | DSI | IPS | 170° | Capacitive | I2C | Yes | Yes | No | No | Yes | No | No | Uploaded HTML: 7inch-DSI-LCD-H.htm
DSI DISPLAYS | 7.9inch DSI LCD | 400×1280 | DSI | IPS | 170° | Capacitive | I2C | Yes | No | No | No | Yes | No | No | Uploaded HTML: 7inch-DSI-LCD-H.htm
DSI DISPLAYS | 8-DSI-TOUCH-A | 800×1280 | DSI | IPS | 178° | Capacitive | I2C | Yes | Yes | No | No | Yes | No | No | Uploaded HTML: 7inch-DSI-LCD-H.htm
DSI DISPLAYS | 8inch DSI LCD | 800×480 | DSI | TFT | – | Capacitive | I2C | Yes | No | No | No | Yes | No | No | Uploaded HTML: 7inch-DSI-LCD-H.htm
DSI DISPLAYS | 8inch DSI LCD (with cam) | 800×480 | DSI | TFT | – | Capacitive | I2C | Yes | No | No | No | Yes | No | No | Uploaded HTML: 7inch-DSI-LCD-H.htm
DSI DISPLAYS | 8inch DSI LCD (C) | 1280×800 | DSI | IPS | 178° | Capacitive | I2C | Yes | Yes | No | No | Yes | No | No | Uploaded HTML: 7inch-DSI-LCD-H.htm
DSI DISPLAYS | 8.8inch DSI LCD | 480×1920 | DSI | IPS | 178° | Capacitive | I2C | Yes | Yes | No | No | Yes | No | No | Uploaded HTML: 7inch-DSI-LCD-H.htm
DSI DISPLAYS | 8.8-DSI-TOUCH-A | 480×1920 | DSI | IPS | 178° | Capacitive | I2C | Yes | Yes | No | No | Yes | No | No | Uploaded HTML: 7inch-DSI-LCD-H.htm
DSI DISPLAYS | 9-DSI-TOUCH-B | 720×1280 | DSI | IPS | 160° | Capacitive | I2C | Yes | No | No | No | Yes | No | No | Uploaded HTML: 7inch-DSI-LCD-H.htm
DSI DISPLAYS | 10.1-DSI-TOUCH-A | 800×1280 | DSI | IPS | 178° | Capacitive | I2C | Yes | Yes | No | No | Yes | No | No | Uploaded HTML: 7inch-DSI-LCD-H.htm
DSI DISPLAYS | 10.1-DSI-TOUCH-B | 720×1280 | DSI | IPS | 170° | Capacitive | I2C | Yes | No | No | No | Yes | No | No | Uploaded HTML: 7inch-DSI-LCD-H.htm
DSI DISPLAYS | 10.1inch DSI LCD (C) | 1280×800 | DSI | IPS | 178° | Capacitive | I2C | Yes | Yes | No | No | Yes | No | No | Uploaded HTML: 7inch-DSI-LCD-H.htm
DSI DISPLAYS | 11.9inch DSI LCD | 320×1480 | DSI | IPS | 170° | Capacitive | I2C | Yes | No | No | No | Yes | No | No | Uploaded HTML: 7inch-DSI-LCD-H.htm
DSI DISPLAYS | 12.3-DSI-TOUCH-A | 720×1920 | DSI | IPS | 178° | Capacitive | I2C | Yes | Yes | No | No | Yes | No | No | Uploaded HTML: 7inch-DSI-LCD-H.htm
DSI DISPLAYS | 13.3inch DSI LCD | 1920×1080 | DSI | IPS | 178° | Capacitive | I2C | Yes | No | No | No | Yes | No | No | Uploaded HTML: 7inch-DSI-LCD-H.htm
HDMI / TYPE-C DISPLAYS | 2.8inch HDMI LCD (H) | 480×640 | HDMI | IPS | 160° | Capacitive | USB-C / I2C | Yes | Yes | No | No | Yes | Yes | Yes | Uploaded HTML: 7inch-DSI-LCD-H.htm
HDMI / TYPE-C DISPLAYS | 3.2inch HDMI LCD (H) | 480×800 | HDMI | IPS | 160° | × | × | No | No | No | No | Yes | Yes | Display only | Uploaded HTML: 7inch-DSI-LCD-H.htm
HDMI / TYPE-C DISPLAYS | 3.4inch 800x800 LCD | 800x800 | HDMI | IPS | 170° | Capacitive | Type-C | Yes | Yes | No | Yes | Yes | Yes | Yes | Uploaded HTML: 7inch-DSI-LCD-H.htm
HDMI / TYPE-C DISPLAYS | 3.5inch HDMI LCD | 480×320 | HDMI | IPS | 160° | Resistive | SPI | No | No | No | Yes | Yes | No | Display only | Uploaded HTML: 7inch-DSI-LCD-H.htm
HDMI / TYPE-C DISPLAYS | 3.5inch 480x800 LCD | 480×800 | HDMI | IPS | 170° | Capacitive | USB-C | No | No | No | No | Yes | Yes | Yes | Uploaded HTML: 7inch-DSI-LCD-H.htm
HDMI / TYPE-C DISPLAYS | 4inch 720x720 LCD | 720x720 | HDMI | IPS | 170° | Capacitive | Type-C | Yes | Yes | No | Yes | Yes | Yes | Yes | Uploaded HTML: 7inch-DSI-LCD-H.htm
HDMI / TYPE-C DISPLAYS | 4inch HDMI LCD | 480×800 | HDMI | IPS | 170° | Resistive | SPI | No | No | No | No | Yes | No | Display only | Uploaded HTML: 7inch-DSI-LCD-H.htm
HDMI / TYPE-C DISPLAYS | 4inch HDMI LCD (C) | 720×720 | HDMI | IPS | 170° | Capacitive | USB-C / I2C | Yes | Yes | No | Yes | Yes | Yes | Yes | Uploaded HTML: 7inch-DSI-LCD-H.htm
HDMI / TYPE-C DISPLAYS | 4inch HDMI LCD (H) | 480×800 | HDMI | IPS | 170° | Resistive | SPI | No | No | No | Yes | Yes | No | Display only | Uploaded HTML: 7inch-DSI-LCD-H.htm
HDMI / TYPE-C DISPLAYS | 4.3inch HDMI LCD (B) | 800×480 | HDMI | IPS | 160° | Capacitive | USB | No | No | No | Yes | Yes | Yes | Yes | Uploaded HTML: 7inch-DSI-LCD-H.htm
HDMI / TYPE-C DISPLAYS | 5DP-CAPLCD-H | 1024×600 | HDMI | IPS | 178° | Capacitive | Type-C | Yes | No | No | Yes | Yes | Yes | Yes | Uploaded HTML: 7inch-DSI-LCD-H.htm
HDMI / TYPE-C DISPLAYS | 5DP-CAPLCD-B | 1024×600 | HDMI | IPS | 178° | Capacitive | Type-C | Yes | Yes | No | Yes | Yes | Yes | Yes | Uploaded HTML: 7inch-DSI-LCD-H.htm
HDMI / TYPE-C DISPLAYS | 5DP-CAPLCD-G | 1024×600 | HDMI | IPS | 178° | Resistive | Type-C | Yes | No | No | Yes | Yes | Yes | Yes | Uploaded HTML: 7inch-DSI-LCD-H.htm
HDMI / TYPE-C DISPLAYS | 5inch HDMI LCD | 800×480 | HDMI | TFT | – | Resistive | SPI | No | No | No | No | Yes | No | No | Uploaded HTML: 7inch-DSI-LCD-H.htm
HDMI / TYPE-C DISPLAYS | 5inch HDMI LCD (with bicolor case) | 800×480 | HDMI | TFT | – | Resistive | SPI | No | No | No | No | Yes | No | No | Uploaded HTML: 7inch-DSI-LCD-H.htm
HDMI / TYPE-C DISPLAYS | 5inch HDMI LCD (B) | 800×480 | HDMI | TFT | – | Resistive | USB | No | No | No | No | Yes | No | Yes | Uploaded HTML: 7inch-DSI-LCD-H.htm
HDMI / TYPE-C DISPLAYS | 5inch HDMI LCD (B) (with bicolor case) | 800×480 | HDMI | TFT | – | Resistive | USB | No | No | No | No | Yes | No | Yes | Uploaded HTML: 7inch-DSI-LCD-H.htm
HDMI / TYPE-C DISPLAYS | 5inch HDMI LCD (G) | 800×480 | HDMI/VGA | TFT | – | Resistive | USB | No | No | No | Yes | Yes | No | Yes | Uploaded HTML: 7inch-DSI-LCD-H.htm
HDMI / TYPE-C DISPLAYS | 5inch HDMI LCD (H) | 800×480 | HDMI/VGA | TFT | – | Capacitive | USB | Yes | No | No | Yes | Yes | Yes | Yes | Uploaded HTML: 7inch-DSI-LCD-H.htm
HDMI / TYPE-C DISPLAYS | 5inch HDMI LCD (H) V4 | 800×480 | HDMI | TFT | – | Capacitive | USB | Yes | No | No | No | Yes | No | Yes | Uploaded HTML: 7inch-DSI-LCD-H.htm
HDMI / TYPE-C DISPLAYS | 5inch HDMI AMOLED | 960×544 | HDMI | AMOLED | 170° | Capacitive | USB | Yes | Yes | No | Yes | Yes | Yes | Yes | Uploaded HTML: 7inch-DSI-LCD-H.htm
HDMI / TYPE-C DISPLAYS | 5inch 1080x1080 LCD | 1080×1080 | HDMI | IPS | 160° | Capacitive | Type-C | Yes | Yes | Yes | Yes | Yes | Yes | Yes | Uploaded HTML: 7inch-DSI-LCD-H.htm
HDMI / TYPE-C DISPLAYS | 5inch 720x1280 LCD | 720×1280 | HDMI | IPS | 178° | Capacitive | Type-C | Yes | Yes | Yes | No | Yes | Yes | Yes | Uploaded HTML: 7inch-DSI-LCD-H.htm
HDMI / TYPE-C DISPLAYS | 5.5inch HDMI AMOLED | 1080×1920 | HDMI | AMOLED | 170° | Capacitive | USB | Yes | Yes | No | Yes | Yes | Yes | Yes | Uploaded HTML: 7inch-DSI-LCD-H.htm
HDMI / TYPE-C DISPLAYS | 5.5inch HDMI AMOLED (with case A) | 1080×1920 | HDMI | AMOLED | 170° | Capacitive | USB | Yes | Yes | No | Yes | Yes | No | No | Uploaded HTML: 7inch-DSI-LCD-H.htm
HDMI / TYPE-C DISPLAYS | 5.5inch 1440x2560 LCD | 1440×2560 | HDMI | IPS | 170° | Capacitive | USB | Yes | Yes | No | Yes | Yes | No | Yes | Uploaded HTML: 7inch-DSI-LCD-H.htm
HDMI / TYPE-C DISPLAYS | 5.5inch 1440x2560 LCD (with case A) | 1440×2560 | HDMI | IPS | 170° | Capacitive | USB | Yes | Yes | No | Yes | Yes | No | No | Uploaded HTML: 7inch-DSI-LCD-H.htm
HDMI / TYPE-C DISPLAYS | 6.25inch 720x1560 LCD | 720×1560 | HDMI | IPS | 178° | Capacitive | Type-C | Yes | Yes | Yes | No | Yes | Yes | Yes | Uploaded HTML: 7inch-DSI-LCD-H.htm
HDMI / TYPE-C DISPLAYS | PI5-HMI-7A | 720×1280 | HDMI | IPS | 170° | Capacitive | Type-C | Yes | Yes | No | No | Yes | No | No | Uploaded HTML: 7inch-DSI-LCD-H.htm
HDMI / TYPE-C DISPLAYS | 7EP-CAPLCD | 1280×800 | HDMI | IPS | 178° | Capacitive | USB | Yes | Yes | Yes | Yes | Yes | Yes | Yes | Uploaded HTML: 7inch-DSI-LCD-H.htm
HDMI / TYPE-C DISPLAYS | 7EP-CAPLCD Monitor | 1280×800 | HDMI/Type-C | IPS | 178° | Capacitive | Type-C | Yes | Yes | Yes | Yes | Yes | Yes | Yes | Uploaded HTML: 7inch-DSI-LCD-H.htm
HDMI / TYPE-C DISPLAYS | 7inch HDMI LCD | 1024×600 | HDMI | IPS | 170° | Resistive | SPI | No | No | No | No | Yes | No | Display only | Uploaded HTML: 7inch-DSI-LCD-H.htm
HDMI / TYPE-C DISPLAYS | 7inch HDMI LCD (B) | 800×480 | HDMI | TFT | – | Capacitive | USB | No | No | No | No | Yes | No | Yes | Uploaded HTML: 7inch-DSI-LCD-H.htm
HDMI / TYPE-C DISPLAYS | 7inch 1080x1080 LCD | 1080×1080 | HDMI | IPS | 160° | Capacitive | Type-C | Yes | Yes | No | Yes | Yes | Yes | Yes | Uploaded HTML: 7inch-DSI-LCD-H.htm
HDMI / TYPE-C DISPLAYS | 7inch HDMI LCD (B) (with bicolor case) | 800×480 | HDMI | TFT | – | Capacitive | USB | No | No | No | No | Yes | No | Yes | Uploaded HTML: 7inch-DSI-LCD-H.htm
HDMI / TYPE-C DISPLAYS | 7inch HDMI LCD (C) | 1024×600 | HDMI | IPS | 170° | Capacitive | USB | No | No | No | No | Yes | No | Yes | Uploaded HTML: 7inch-DSI-LCD-H.htm
HDMI / TYPE-C DISPLAYS | 7inch HDMI LCD (C) (with bicolor case) | 1024×600 | HDMI | IPS | 170° | Capacitive | USB | No | No | No | No | Yes | No | Yes | Uploaded HTML: 7inch-DSI-LCD-H.htm
HDMI / TYPE-C DISPLAYS | 7inch HDMI LCD (H) | 1024×600 | HDMI/VGA | IPS | 170° | Capacitive | USB | No | No | No | Yes | Yes | Yes | Yes | Uploaded HTML: 7inch-DSI-LCD-H.htm
HDMI / TYPE-C DISPLAYS | 7inch HDMI LCD (H) (with case) | 1024×600 | HDMI/VGA | IPS | 170° | Capacitive | USB | Yes | No | No | Yes | Yes | Yes | Yes | Uploaded HTML: 7inch-DSI-LCD-H.htm
HDMI / TYPE-C DISPLAYS | 7HP-CAPQLED | 1024×600 | HDMI | IPS (QLED) | 170° | Capacitive | USB | Yes | No | No | Yes | Yes | Yes | Yes | Uploaded HTML: 7inch-DSI-LCD-H.htm
HDMI / TYPE-C DISPLAYS | 7.9inch HDMI LCD | 400×1280 | HDMI | IPS | 170° | Capacitive | USB | Yes | No | No | Yes | Yes | Yes | Yes | Uploaded HTML: 7inch-DSI-LCD-H.htm
HDMI / TYPE-C DISPLAYS | 7.9inch Side Monitor | 400×1280 | HDMI | IPS | 170° | × | × | Yes | No | Yes | No | Yes | Yes | Yes | Uploaded HTML: 7inch-DSI-LCD-H.htm
HDMI / TYPE-C DISPLAYS | 7.9inch Touch Monitor | 400×1280 | HDMI | IPS | 170° | Capacitive | USB | Yes | No | Yes | No | Yes | Yes | Yes | Uploaded HTML: 7inch-DSI-LCD-H.htm
HDMI / TYPE-C DISPLAYS | PI5-HMI-080D | 1280×800 | HDMI | IPS | 178° | Capacitive | Type-C | Yes | Yes | No | No | Yes | No | No | Uploaded HTML: 7inch-DSI-LCD-H.htm
HDMI / TYPE-C DISPLAYS | 8DP-CAPLCD | 1280×800 | HDMI | IPS | 178° | Capacitive | USB | Yes | Yes | No | Yes | Yes | Yes | Yes | Uploaded HTML: 7inch-DSI-LCD-H.htm
HDMI / TYPE-C DISPLAYS | 8HP-CAPLCD Monitor | 1280×800 | HDMI/Type-C | IPS | 178° | Capacitive | USB | Yes | Yes | Yes | Yes | Yes | Yes | Yes | Uploaded HTML: 7inch-DSI-LCD-H.htm
HDMI / TYPE-C DISPLAYS | 8inch 768x1024 LCD | 768×1024 | HDMI | IPS | 178° | Capacitive | Type-C | Yes | No | Yes | Yes | Yes | Yes | Yes | Uploaded HTML: 7inch-DSI-LCD-H.htm
HDMI / TYPE-C DISPLAYS | 8inch 1536x2048 LCD | 1536×2048 | HDMI | IPS | 178° | Capacitive | Type-C | Yes | Yes | Yes | Yes | Yes | Yes | Yes | Uploaded HTML: 7inch-DSI-LCD-H.htm
HDMI / TYPE-C DISPLAYS | 8.8inch Side Monitor | 480×1920 | HDMI | IPS | 170° | × | × | No | No | Yes | No | Yes | Yes | Display only | Uploaded HTML: 7inch-DSI-LCD-H.htm
HDMI / TYPE-C DISPLAYS | 9HP-CAPQLED-B | 1280×720 | HDMI | IPS (QLED) | 178° | Capacitive | USB | Yes | No | No | Yes | Yes | Yes | Yes | Uploaded HTML: 7inch-DSI-LCD-H.htm
HDMI / TYPE-C DISPLAYS | 9.3inch 1600x600 LCD | 1600×600 | HDMI | IPS | 178° | Capacitive | Type-C | Yes | Yes | Yes | Yes | Yes | Yes | Yes | Uploaded HTML: 7inch-DSI-LCD-H.htm
HDMI / TYPE-C DISPLAYS | 9.7inch 768x1024 LCD | 768×1024 | HDMI | IPS | 178° | Capacitive | Type-C | Yes | No | Yes | Yes | Yes | Yes | Yes | Uploaded HTML: 7inch-DSI-LCD-H.htm
HDMI / TYPE-C DISPLAYS | PI5-HMI-101D | 1280×800 | HDMI | IPS | 178° | Capacitive | Type-C | Yes | Yes | No | No | Yes | No | No | Uploaded HTML: 7inch-DSI-LCD-H.htm
HDMI / TYPE-C DISPLAYS | 10.1inch HDMI LCD | 1024×600 | HDMI | IPS | 170° | Resistive | SPI | No | No | No | No | Yes | No | Display only | Uploaded HTML: 7inch-DSI-LCD-H.htm
HDMI / TYPE-C DISPLAYS | 10.1inch HDMI LCD (B) (with case) | 1280×800 | HDMI | IPS | 170° | Capacitive | USB | Yes | No | No | No | Yes | No | Yes | Uploaded HTML: 7inch-DSI-LCD-H.htm
HDMI / TYPE-C DISPLAYS | 10.1inch HDMI LCD (E) | 1024×600 | HDMI | IPS | 170° | Capacitive | USB | Yes | Yes | No | Yes | Yes | Yes | Yes | Uploaded HTML: 7inch-DSI-LCD-H.htm
HDMI / TYPE-C DISPLAYS | 10.1inch HDMI LCD (G) (with case) | 1920×1200 | HDMI | IPS | 160° | Capacitive | USB | Yes | Yes | Yes | Yes | Yes | Yes | Yes | Uploaded HTML: 7inch-DSI-LCD-H.htm
HDMI / TYPE-C DISPLAYS | 10.1inch HDMI LCD (H) (with case) | 1024×600 | HDMI/VGA | TFT | – | Capacitive | USB | No | No | No | No | Yes | Yes | Yes | Uploaded HTML: 7inch-DSI-LCD-H.htm
HDMI / TYPE-C DISPLAYS | 10.1inch HDMI LCD (F) (with case) | 1024×600 | HDMI/VGA | IPS | 170° | Capacitive | USB | Yes | No | Yes | No | Yes | Yes | Yes | Uploaded HTML: 7inch-DSI-LCD-H.htm
HDMI / TYPE-C DISPLAYS | 10.1EP-CAPLCD | 1920×1200 | HDMI | IPS | 178° | Capacitive | Type-C | Yes | Yes | Yes | Yes | Yes | Yes | Yes | Uploaded HTML: 7inch-DSI-LCD-H.htm
HDMI / TYPE-C DISPLAYS | 10.1DP-CAPLCD | 1280×800 | HDMI | IPS | 178° | Capacitive | USB | Yes | Yes | No | Yes | Yes | Yes | Yes | Uploaded HTML: 7inch-DSI-LCD-H.htm
HDMI / TYPE-C DISPLAYS | 10.1HP-CAPQLED | 1280×720 | HDMI | IPS (QLED) | 170° | Capacitive | USB | Yes | No | No | Yes | Yes | Yes | Yes | Uploaded HTML: 7inch-DSI-LCD-H.htm
HDMI / TYPE-C DISPLAYS | 10.1HP-CAPLCD Monitor | 1280×800 | HDMI/Type-C | IPS | 178° | Capacitive | USB | Yes | Yes | Yes | Yes | Yes | Yes | Yes | Uploaded HTML: 7inch-DSI-LCD-H.htm
HDMI / TYPE-C DISPLAYS | 10.4HP-CAPQLED | 1600×720 | HDMI | IPS(QLED) | 178° | Capacitive | Type-C | Yes | Yes | Yes | Yes | Yes | Yes | Yes | Uploaded HTML: 7inch-DSI-LCD-H.htm
HDMI / TYPE-C DISPLAYS | 10.5inch HDMI AMOLED | 2560×1600 | HDMI | AMOLED | 160° | Capacitive | USB | Yes | Yes | Yes | Yes | Yes | Yes | Yes | Uploaded HTML: 7inch-DSI-LCD-H.htm
HDMI / TYPE-C DISPLAYS | 11.6inch 1768x828 LCD | 1768×828 | HDMI/Type-C | IPS | 178° | Capacitive | Type-C | In-Cell | No | No | Yes | Yes | Yes | Yes | Uploaded HTML: 7inch-DSI-LCD-H.htm
HDMI / TYPE-C DISPLAYS | 11.6inch HDMI LCD (H) | 1920×1080 | HDMI | IPS | 178° | Capacitive | USB | Yes | Yes | No | Yes | Yes | Yes | Yes | Uploaded HTML: 7inch-DSI-LCD-H.htm
HDMI / TYPE-C DISPLAYS | 11.6inch HDMI LCD (H) (with case) | 1920×1080 | HDMI/VGA | IPS | 178° | Capacitive | USB | Yes | Yes | Yes | Yes | Yes | Yes | Yes | Uploaded HTML: 7inch-DSI-LCD-H.htm
HDMI / TYPE-C DISPLAYS | 11.9inch HDMI LCD | 320×1480 | HDMI | IPS | 170° | Capacitive | USB | Yes | No | No | Yes | Yes | Yes | Yes | Uploaded HTML: 7inch-DSI-LCD-H.htm
HDMI / TYPE-C DISPLAYS | 11.9inch Side Monitor | 320×1480 | HDMI | IPS | 170° | × | × | Yes | No | Yes | No | Yes | Yes | Yes | Uploaded HTML: 7inch-DSI-LCD-H.htm
HDMI / TYPE-C DISPLAYS | 11.9inch Touch Monitor | 320×1480 | HDMI | IPS | 170° | Capacitive | USB | Yes | No | Yes | No | Yes | Yes | Yes | Uploaded HTML: 7inch-DSI-LCD-H.htm
HDMI / TYPE-C DISPLAYS | 12.3inch 1920x720 LCD | 1920×720 | HDMI/Type-C | IPS | 178° | Capacitive | Type-C | In-Cell | No | No | Yes | Yes | Yes | Yes | Uploaded HTML: 7inch-DSI-LCD-H.htm
HDMI / TYPE-C DISPLAYS | 12.3inch HDMI LCD | 1920×720 | HDMI | IPS | 178° | Capacitive | USB | Yes | Yes | Yes | Yes | Yes | Yes | Yes | Uploaded HTML: 7inch-DSI-LCD-H.htm
HDMI / TYPE-C DISPLAYS | 13.3inch HDMI LCD (H) | 1920×1080 | HDMI | IPS | 178° | Capacitive | USB | Yes | No | No | Yes | Yes | Yes | Yes | Uploaded HTML: 7inch-DSI-LCD-H.htm
HDMI / TYPE-C DISPLAYS | 13.3inch HDMI LCD (H) (with case) | 1920×1080 | HDMI/VGA | IPS | 178° | Capacitive | USB | Yes | No | Yes | Yes | Yes | Yes | Yes | Uploaded HTML: 7inch-DSI-LCD-H.htm
HDMI / TYPE-C DISPLAYS | 13.3inch HDMI LCD (H) (with case) V2 | 1920×1080 | HDMI/VGA | IPS | 178° | Capacitive | USB | Yes | No | Yes | Yes | Yes | Yes | Yes | Uploaded HTML: 7inch-DSI-LCD-H.htm
HDMI / TYPE-C DISPLAYS | 13.3inch QHD AMOLED | 2560×1440 | HDMI/Type-C | AMOLED | 178° | Capacitive | Type-C | Yes | Yes | Yes | Yes | Yes | Yes | Yes | Uploaded HTML: 7inch-DSI-LCD-H.htm
HDMI / TYPE-C DISPLAYS | 13.3inch FHD AMOLED | 1920×1080 | HDMI/Type-C | AMOLED | 178° | Capacitive | Type-C | Yes | Yes | Yes | Yes | Yes | Yes | Yes | Uploaded HTML: 7inch-DSI-LCD-H.htm
HDMI / TYPE-C DISPLAYS | 13.3inch FHD Monitor | 1920×1080 | HDMI/Type-C | IPS | 178° | Capacitive | Type-C | Yes | No | No | Yes | Yes | Yes | Yes | Uploaded HTML: 7inch-DSI-LCD-H.htm
HDMI / TYPE-C DISPLAYS | 14-4K-Touch-Monitor | 3840×2160 | HDMI/Type-C | IPS | 178° | Capacitive | Type-C | Yes | Yes | Yes | Yes | Yes | Yes | Yes | Uploaded HTML: 7inch-DSI-LCD-H.htm
HDMI / TYPE-C DISPLAYS | 14-Portable-Monitor | 1920×1200 | HDMI/Type-C | IPS | 178° | × | × | No | No | Yes | Yes | Yes | Yes | Yes | Uploaded HTML: 7inch-DSI-LCD-H.htm
HDMI / TYPE-C DISPLAYS | 14inch Dual Monitor | 1920×1080 | HDMI/Type-C | IPS | 178° | × | × | No | No | Yes | Yes | Yes | Yes | Yes | Uploaded HTML: 7inch-DSI-LCD-H.htm
HDMI / TYPE-C DISPLAYS | 15.6-Portable-Monitor | 1920×1080 | HDMI/Type-C | IPS | 178° | × | × | No | No | Yes | Yes | Yes | Yes | Yes | Uploaded HTML: 7inch-DSI-LCD-H.htm
HDMI / TYPE-C DISPLAYS | 15.6inch FHD Monitor (C) | 1920×1080 | mini HDMI/Type-C | IPS | 178° | Capacitive | Type-C | Yes | Yes | Yes | Yes | Yes | Yes | Yes | Uploaded HTML: 7inch-DSI-LCD-H.htm
HDMI / TYPE-C DISPLAYS | 15.6inch Dual Monitor | 1920×1080 | HDMI/Type-C | IPS | 178° | × | × | No | No | Yes | Yes | Yes | Yes | Yes | Uploaded HTML: 7inch-DSI-LCD-H.htm
HDMI / TYPE-C DISPLAYS | 15.6inch HDMI LCD | 1920×1080 | HDMI | IPS | 178° | Capacitive | USB | Yes | No | No | Yes | Yes | Yes | Yes | Uploaded HTML: 7inch-DSI-LCD-H.htm
HDMI / TYPE-C DISPLAYS | 15.6inch HDMI LCD (H) (with case) | 1920×1080 | HDMI/VGA | IPS | 178° | Capacitive | USB | Yes | No | Yes | Yes | Yes | Yes | Yes | Uploaded HTML: 7inch-DSI-LCD-H.htm
HDMI / TYPE-C DISPLAYS | 15.6inch FHD Monitor | 1920×1080 | HDMI/Type-C | IPS | 178° | Capacitive | Type-C / USB | Yes | No | Yes | Yes | Yes | Yes | Yes | Uploaded HTML: 7inch-DSI-LCD-H.htm
HDMI / TYPE-C DISPLAYS | 15.6HP-CAPQLED | 1920×1080 | HDMI | IPS(QLED) | 178° | Capacitive | USB | Yes | Yes | No | Yes | Yes | Yes | Yes | Uploaded HTML: 7inch-DSI-LCD-H.htm
HDMI / TYPE-C DISPLAYS | 15.6inch QLED Monitor | 1920×1080 | HDMI | IPS(QLED) | 178° | Capacitive | Type-C | Yes | Yes | Yes | Yes | Yes | Yes | Yes | Uploaded HTML: 7inch-DSI-LCD-H.htm
HDMI / TYPE-C DISPLAYS | 18.5inch Dual Monitor | 1920×1080 | HDMI/Type-C | IPS | 178° | × | × | No | No | Yes | Yes | Yes | Yes | Yes | Uploaded HTML: 7inch-DSI-LCD-H.htm
HDMI / TYPE-C DISPLAYS | 16-2K-Touch-Monitor | 2560×1600 | HDMI/Type-C | IPS | 178° | Capacitive | Type-C | Yes | Yes | Yes | Yes | Yes | Yes | Yes | Uploaded HTML: 7inch-DSI-LCD-H.htm
HDMI / TYPE-C DISPLAYS | 16-4K-Touch-Monitor | 3840×2400 | HDMI/Type-C | IPS | 178° | Capacitive | Type-C | Yes | Yes | Yes | Yes | Yes | Yes | Yes | Uploaded HTML: 7inch-DSI-LCD-H.htm
HDMI / TYPE-C DISPLAYS | 18.5inch FHD LCD | 1080×1920 | HDMI/Type-C | IPS | 178° | Capacitive | Type-C | Yes | Yes | No | Yes | Yes | Yes | Yes | Uploaded HTML: 7inch-DSI-LCD-H.htm
HDMI / TYPE-C DISPLAYS | 18.5-Portable-Monitor | 1920×1080 | HDMI/Type-C | IPS | 178° | × | × | No | No | Yes | Yes | Yes | Yes | Yes | Uploaded HTML: 7inch-DSI-LCD-H.htm
HDMI / TYPE-C DISPLAYS | 18.5-Touch-Monitor | 1920×1080 | HDMI/Type-C | IPS | 178° | Capacitive | Type-C | Yes | Yes | Yes | Yes | Yes | Yes | Yes | Uploaded HTML: 7inch-DSI-LCD-H.htm
HDMI / TYPE-C DISPLAYS | 18.5-4K-Portable-Monitor | 3840×2160 | HDMI/Type-C | IPS | 178° | × | × | No | No | Yes | Yes | Yes | Yes | Yes | Uploaded HTML: 7inch-DSI-LCD-H.htm
HDMI / TYPE-C DISPLAYS | 21.5inch FHD LCD | 1080×1920 | HDMI | IPS | 170° | Capacitive | Type-C | Yes | Yes | No | Yes | Yes | Yes | Yes | Uploaded HTML: 7inch-DSI-LCD-H.htm
HDMI / TYPE-C DISPLAYS | 21.5inch FHD Monitor | 1080×1920 | HDMI | IPS | 170° | Capacitive | Type-C | Yes | Yes | Yes | No | Yes | Yes | Yes | Uploaded HTML: 7inch-DSI-LCD-H.htm
HDMI / TYPE-C DISPLAYS | 21.5-Portable-Monitor | 1920×1080 | HDMI/Type-C | IPS | 178° | × | × | No | No | Yes | Yes | Yes | Yes | Yes | Uploaded HTML: 7inch-DSI-LCD-H.htm
HDMI / TYPE-C DISPLAYS | 23.8inch FHD Monitor | 1080×1920 | HDMI | IPS | 178° | Capacitive | Type-C | Yes | Yes | Yes | Yes | Yes | Yes | Yes | Uploaded HTML: 7inch-DSI-LCD-H.htm
HDMI / TYPE-C DISPLAYS | 24.5-2K-Portable-Monitor | 2560×1440 | HDMI/Type-C | IPS | 178° | × | × | No | No | Yes | Yes | Yes | Yes | Yes | Uploaded HTML: 7inch-DSI-LCD-H.htm
HDMI / TYPE-C DISPLAYS | 27inch FHD Monitor | 1080×1920 | HDMI | IPS | 178° | Capacitive | Type-C | Yes | Yes | Yes | Yes | Yes | Yes | Yes | Uploaded HTML: 7inch-DSI-LCD-H.htm

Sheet: Comparison Summary
Comparison of Selection Guide across H, E, and A pages
Source | Location | Comparison basis | Verdict | Notes
Uploaded HTML (H) | 7inch-DSI-LCD-H.htm | Directly extracted full Selection Guide table from uploaded HTML | 161 product rows extracted | Reference source
Waveshare E page | https://www.waveshare.com/7inch-DSI-LCD-E.htm | Selection Guide header structure matches H; sampled DSI and HDMI rows match H | Appears to use the same master Selection Guide list | Compared header and row samples incl. 7inch DSI LCD (E), 7-DSI-TOUCH-A, 7inch DSI LCD (H), plus HDMI rows
Waveshare A page | https://www.waveshare.com/7-dsi-touch-a.htm | Selection Guide header structure matches H; sampled DSI and HDMI rows match H | Appears to use the same master Selection Guide list | Compared header and row samples incl. 7inch DSI LCD (E), 7-DSI-TOUCH-A, 7inch DSI LCD (H), plus HDMI rows
Check area | What was compared | Outcome | Confidence | Source notes
Guide structure | Selection Guide heading + same column groups | Matched | High | E and A pages match H guide structure
DSI section sample | Rows including 7inch DSI LCD (E), 7-DSI-TOUCH-A, 7inch DSI LCD (H) | Matched | High | Compared live E/A pages to uploaded H guide
HDMI section sample | Rows including 7HP-CAPQLED and nearby HDMI entries | Matched | High | Compared live E/A pages to uploaded H guide
Caveat | This workbook contains the full table extracted from the uploaded H page. The E and A verdict is based on page-content comparison in this environment, not a byte-for-byte HTML diff.
Recommendation | Treat these three product pages as using the same master Selection Guide list for practical buying/filtering work.
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

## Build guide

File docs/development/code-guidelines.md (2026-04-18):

# Code Guidelines

## Purpose

This document defines lightweight development guidelines for `samsung-jog-api`.

The goal is not to create a heavy style manual. The goal is to keep implementation aligned with the architecture so the codebase stays understandable as hardware, backend, and frontend work grow together.

## General principles

- keep architecture boundaries visible in the code
- prefer clear names over clever abstractions
- avoid leaking low-level hardware terms into higher-level UI and workflow layers unless necessary
- make logging and error handling consistent
- keep implementation pragmatic and easy to debug

## Code style

- keep functions and methods focused on a single responsibility
- if a function becomes hard to scan or mixes concerns, split it
- prefer descriptive names over abbreviations
- name objects and types by their domain meaning rather than temporary implementation detail
- keep side effects obvious
- avoid deep nesting where a flatter structure is clearer
- prefer explicit data shapes over loose dictionaries where practical
- avoid comments that merely restate obvious code
- add comments only where intent, hardware nuance, or non-obvious behavior would otherwise be unclear
- do not add arbitrary line-count rules if they make the code worse; optimize for readability and maintainability

## Backend guidelines

The Python import package is **`pi_deck`** (directory `backend/src/pi_deck/`; PyPI / `pip` name **`pi-deck`** in `backend/pyproject.toml`). Repository layout: see [Architecture — Repository layout](../architecture.md#repository-layout).

Top-level packages inside **`pi_deck`** (each is a real directory with an `__init__.py`):

| Package | Role |
|---|---|
| `api` | FastAPI routes, HTTP/WebSocket boundary |
| `services` | Workflows, arbitration, sequences |
| `hardware` | GPIO, `JOG`, `LED`, `DDC` adapters — **only** layer that touches signals |
| `storage` | Recordings, settings, local files |
| `models` | Domain types and validation models |

Bring-up and one-off **bench scripts** (not importable API) live under the repository **`scripts/`** directory, next to operational shell helpers.

### Lifecycle across implementation phases

This matches the system model in [Solution Overview](../design/solution-overview.md): *UI → API → monitor-control services → **hardware interface** (+ DDC) → monitor*.

- **Phases 9+ (platform, API, UI, recording):** the **`hardware/`** tree is **not** throwaway scaffolding. It is the **custom hardware interface** layer: `jog_drive`, `jog_observe`, `led_observe`, later `ddc`, etc. **`services`** and **`api`** (Phases 10–12) **import and orchestrate** this layer; they do not replace it each phase.
- **Phase 9 (kiosk, `systemd`, logging)** mostly configures **how the host runs** the eventual backend process. It does **not** imply rewriting or discarding the hardware modules—only **starting** the same package under supervision when the API exists.
- **What may change later:** GPIO numbers and possibly concrete classes when moving from **Phase 6** wiring to **Phase 7** boards ([deferred migration](../implementation/plan.md#deferred-integrated-board-gpio-and-software-migration))—that is **remapping and adaptation**, not deleting the backend and starting over.

### Language and framework

- use `Python`
- use `FastAPI` for HTTP and websocket interfaces

### Module boundaries

Keep the backend split conceptually into:

- `api`
- `services`
- `hardware`
- `storage`
- `models`

Responsibilities:

- `api`
  - request and response handling
  - websocket endpoints
  - validation at the boundary
- `services`
  - monitor workflow logic
  - command arbitration
  - sequence execution orchestration
  - widget-oriented application services
- `hardware`
  - `jog_drive`
  - `jog_observe`
  - `led_observe`
  - `ddc`
  - `display_power`
- `storage`
  - recordings
  - settings
  - local persisted state
- `models`
  - typed domain objects
  - schema and validation models
  - error types

### Backend design rules

- keep low-level monitor signal details inside `hardware`
- keep monitor workflows inside `services`
- keep API routes thin
- do not let route handlers embed monitor workflow logic
- do not let UI-facing layers manipulate GPIO or `DDC` directly
- treat sequences as validated domain objects, not loose dictionaries passed everywhere

### Error handling

- use explicit error categories
- prefer structured failures over generic exceptions at API boundaries
- log operational context when commands fail
- keep failure reasons meaningful enough for the UI to present useful feedback

### Logging

- produce one event per line
- include timestamp, type, and message
- keep log categories consistent across modules
- do not log secrets, credentials, usernames, or private network details

## Frontend guidelines

### Language and framework

- use `React`
- use `TypeScript`

### Frontend design rules

- keep one UI for kiosk and LAN browser access
- optimize layout first for the **1280×800** deck display, while remaining responsive
- keep primary control actions visually dominant
- treat monitor control as the primary interaction surface
- keep dashboard widgets secondary in layout weight

### Component boundaries

- keep presentational components small and focused
- keep workflow and API coordination out of leaf components
- avoid letting unrelated widgets interfere with one another
- keep advanced/settings tooling separate from primary controls in the layout, not as a separate product

### Navigation and URLs

Browser navigation behavior should work properly outside kiosk use.

That means:

- back and forward browser actions should behave correctly
- important screens and views should have stable URLs
- the current URL should be copyable and usable to return directly to the same place later
- routing should not depend on kiosk-only assumptions

The kiosk may not expose browser controls, but the application should still behave like a real web app when accessed from a full browser.

### State and live updates

- use normal API fetches for data that does not require live push
- use websocket-driven updates for live control and status behavior
- keep websocket event handling centralized rather than scattering it across many components
- do not duplicate the same live state in multiple unrelated places without a clear owner

## Domain-model guidelines

- prefer logical action names such as `hold`, `release`, `wait_led`, and `wait_ddc`
- do not expose low-level bus names such as `KEY_ADC1` and `KEY_ADC2` in UI-facing sequence definitions unless truly necessary
- keep logical actions separate from hardware mapping
- keep start-state and end-state assumptions explicit where relevant

## Recording and sequence guidelines

- store recordings as structured JSON files
- validate recordings before execution
- keep recordings editable by humans
- use meaningful names for promoted recordings
- treat timeout behavior as part of sequence correctness, not as an edge case

## Settings guidelines

- prefer toggles and simple choices
- avoid typed settings where possible
- assume no hardware keyboard is present
- design for touch-first interaction

## Security and repository hygiene

- do not commit passwords
- do not commit keys
- do not commit usernames
- do not commit private IP addresses or environment-specific secrets

## Deploying to the deck host

**`scripts/deploy.sh` is the one and only deploy mechanism.** Do not rsync directories manually, restart services by hand, or use `scripts/host/deploy_pi_deck_ui.sh` for routine deployments.

```bash
# From the repository root on the dev machine:
PI_TARGET=user@pi-hostname ./scripts/deploy.sh
```

The script builds the frontend, rsyncs all code, increments the deploy counter, reinstalls the Python package, restarts `pi-deck`, and reloads Chromium. Every deployment must go through this script so the version counter stays accurate and the kiosk always reflects the latest code.

The frontend build is skipped automatically when no files under `frontend/src` or `frontend/public` have changed since the last deploy. To force a full rebuild:

```bash
FORCE_BUILD=1 PI_TARGET=user@pi-hostname ./scripts/deploy.sh
```

`PI_TARGET` must be set as an environment variable — it is never hardcoded. Do not commit IP addresses, usernames, or hostnames.

## When in doubt

- keep low-level hardware concerns low in the stack
- keep the UI working like a normal web app
- prefer explicit structure over hidden coupling
- favor debuggability over premature cleverness

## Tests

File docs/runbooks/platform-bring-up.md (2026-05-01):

# Phase 9: Local Platform Bring-Up

## Purpose

Bring the control-deck host to the [Solution Overview — Host platform design](../design/solution-overview.md) baseline:

- `systemd`-supervised `pi-deck` HTTP server (serves the React **JOG console** from `pi_deck/static`; build via `frontend/npm run build`)
- daily rotated file logs with long retention
- Chromium kiosk pointed at `http://127.0.0.1:8756/` — the **JOG console** UI (after a graphical session exists)
- documented recovery: `Restart=on-failure` on the service; kiosk restarts with session login

## Prerequisites

- Raspberry Pi OS with network access
- Repository clone on the Pi (this document assumes `~/samsung-jog-api`, matching the systemd unit template)
- SSH access for setup

## 1. Install the backend service

From the repository root on the Pi:

```bash
chmod +x scripts/host/install_pi_deck_systemd.sh scripts/kiosk/pi-deck-chromium-kiosk.sh
sudo ./scripts/host/install_pi_deck_systemd.sh
```

Run the installer with `sudo` so it can write `/etc/systemd/system/pi-deck.service`. The script substitutes `@REPO_ROOT@`, `@SERVICE_USER@`, and `@SERVICE_HOME@` in `config/systemd/pi-deck.service`. By default it uses `SUDO_USER` (the account that invoked `sudo`) as the service user. To override:

```bash
sudo PI_DECK_SERVICE_USER=pi ./scripts/host/install_pi_deck_systemd.sh
```

The unit sets `HOME` and `PI_DECK_LOG_DIR` to explicit paths under that user’s home so logging never tries to create `/root/.local/...` when the process drops privileges.

This creates `backend/.venv`, installs `pi-deck` in editable mode, installs `/etc/systemd/system/pi-deck.service`, enables and starts the unit.

Check:

```bash
systemctl status pi-deck
curl -sf http://127.0.0.1:8756/health
journalctl -u pi-deck -n 50 --no-pager
```

Logs on disk (daily rotation, ~93 retained files):

```text
~/.local/share/pi-deck/logs/pi-deck.log
```

Environment overrides (optional):

| Variable | Default | Meaning |
|---|---|---|
| `PI_DECK_HOST` | `0.0.0.0` | Bind address (`0.0.0.0` = LAN + localhost; use `127.0.0.1` only if you refuse non-local connections) |
| `PI_DECK_PORT` | `8756` | Listen port |
| `PI_DECK_LOG_DIR` | `~/.local/share/pi-deck/logs` | Directory for `pi-deck.log` |
| `PI_DECK_HARDWARE` | `live` (template default) | **`mock`** only for dev without wiring. On startup, `pi-deck` selects gpiozero’s **`rpigpio`** (`RPi.GPIO`) factory unless **`GPIOZERO_PIN_FACTORY`** is already set — the **native** sysfs backend often fails on older Pis (`OSError` on export). If **`live`** still fails during startup, **`pi-deck` never listens on 8756** and the [kiosk script](../../scripts/kiosk/pi-deck-chromium-kiosk.sh) **never opens Chromium** (waits for `/health`). Install deps: `pip install -e .` in `backend/` (pulls **`RPi.GPIO`** on Linux). On Pi 4+ Bookworm you may prefer `Environment=GPIOZERO_PIN_FACTORY=lgpio` after `apt install python3-lgpio` / venv `pip install lgpio`. |

Edit the unit with `sudo systemctl edit pi-deck` to add `Environment=` lines, then `sudo systemctl daemon-reload && sudo systemctl restart pi-deck`.

## 2. Graphical session and kiosk (deck display)

**Kiosk cannot work** while the Pi boots to the text console only (`multi-user.target`). There must be a graphical session, Chromium, and an autostart entry. Symptoms: blank display, no Chromium, `systemctl is-active display-manager` → `inactive`.

If the Pi currently boots to multi-user (console only), install a desktop stack once:

```bash
sudo ./scripts/host/phase9_install_desktop_stack.sh
sudo reboot
```

After reboot, the system should land in a graphical session logged in as your user.

Install the autostart entry so Chromium opens fullscreen to the local app:

```bash
chmod +x scripts/host/install_pi_deck_kiosk_autostart.sh
./scripts/host/install_pi_deck_kiosk_autostart.sh
```

Log out and back in, or reboot, to verify Chromium loads the **JOG console** (hero, controls, live log).

The kiosk script (`scripts/kiosk/pi-deck-chromium-kiosk.sh`) waits for `/health` before launching. **Pointer hiding:** on X11 it runs `unclutter` when installed; on **Wayland** it runs `wlrctl pointer hide` when that tool is available ([Phase 11](../implementation/phase-11-execution.md) polish). If the pointer still shows, install `wlrctl` or use X11 — see the [implementation plan](../implementation/plan.md#phase-9-local-platform-bring-up) history.

After changing any code, use the canonical deploy script from the dev machine (repo root):

```bash
PI_TARGET=user@pi-hostname ./scripts/deploy.sh
```

This builds the frontend, rsyncs all code to the Pi, auto-tags on main, restarts `pi-deck`, and reloads Chromium. Do not rsync partial directories or restart the service manually — use the script so the deploy counter increments and the kiosk picks up the latest assets.

### SSH key setup (one time)

The script uses `BatchMode=yes` (no password prompts). Set up key-based auth before the first deploy:

```bash
ssh-keygen -t ed25519 -C "pi-deck-deploy"   # skip if you already have a key
ssh-copy-id user@192.168.x.x                # copies ~/.ssh/id_ed25519.pub to the Pi
ssh user@192.168.x.x                        # verify it connects without a password
```

Optional — add a `~/.ssh/config` entry so you can use a short alias:

```
Host pi-deck
    HostName 192.168.x.x
    User rafael
    IdentityFile ~/.ssh/id_ed25519
```

Then `PI_TARGET=pi-deck ./scripts/deploy.sh` works from any directory.

### Environment variables

| Variable | Required | Description |
|---|---|---|
| `PI_TARGET` | yes | SSH destination, e.g. `rafael@10.0.0.116` or `pi-deck` if using `~/.ssh/config`. |
| `FORCE_BUILD` | no | Set to `1` to rebuild the frontend even when no source files changed. |

Persist `PI_TARGET` for your shell session so you don't have to prefix every command:

```bash
export PI_TARGET=rafael@10.0.0.116   # add to ~/.zshrc or ~/.bashrc to make it permanent
./scripts/deploy.sh
```

## 3. Recovery checks

- **Backend crash:** `systemctl status pi-deck` should show automatic restart (`Restart=on-failure`).
- **Reboot:** after `sudo reboot`, `curl http://127.0.0.1:8756/health` should succeed once networking is up (service starts after `network-online.target`).
- **Kiosk:** if Chromium dies, restarting the graphical session (logout/login) relaunches autostart; the backend keeps running independently.

## 4. “Default Keyring” / GNOME Keyring password prompt (autologin)

With **LightDM autologin**, PAM does not unlock **GNOME Keyring**, so you may see a dialog asking to set or unlock the default keyring.

For an appliance/kiosk host you usually want to avoid that prompt:

1. Run once as the graphical user (not `root`):

   ```bash
   chmod +x scripts/kiosk/pi-deck-disable-gnome-keyring-autostart.sh
   ./scripts/kiosk/pi-deck-disable-gnome-keyring-autostart.sh
   ```

2. The kiosk launcher already passes **`--password-store=basic`** to Chromium so it does not rely on the GNOME keyring for its password store.

3. **Reboot** or log out and back in.

If a prompt is already on screen, you can **Cancel** it after applying the steps above; the next session should not start the keyring components the same way.

## 5. Changing the clone path

`config/systemd/pi-deck.service` uses `@REPO_ROOT@` placeholders. Re-run `install_pi_deck_systemd.sh` with the absolute path to the repository root, or edit the installed unit under `/etc/systemd/system/pi-deck.service`.

## Host health snapshot

After bring-up, capture a baseline on the deck with:

```bash
python3 scripts/pi-deck-host-health.py
```

Use the **default text output** in Markdown execution records. `--json` is optional (tooling/archives only), not the main documentation format.

See [Phase 9 execution record](../implementation/phase-9-execution.md#host-health-snapshot-baseline) for an example. Feature phases (**10–28**) must record an updated snapshot when closing the phase ([Host health gate](../implementation/plan.md#host-health-gate-feature-phases-1028)).

## Related documents

- [Implementation plan — Phase 9](../implementation/plan.md#phase-9-local-platform-bring-up)
- [Code guidelines — lifecycle](../development/code-guidelines.md#lifecycle-across-implementation-phases)
- [Prepare Raspberry Pi](prepare-raspberry-pi.md) (Phase 1 baseline)

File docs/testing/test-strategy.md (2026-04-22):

# Test Strategy

## Purpose

This document defines the testing strategy for `samsung-jog-api`.

The goal is to make testing an intentional part of the project rather than something deferred until late implementation. Because this project spans UI, backend logic, monitor communication, and custom hardware, the test strategy must cover more than unit tests.

## Testing goals

- verify correctness of backend logic and command arbitration
- verify correctness of frontend behavior and user feedback
- verify low-level hardware behavior and monitor interaction
- verify sequence validation, execution, timeout, and abort behavior
- verify productized monitor workflows such as source switching and `PiP`
- verify reboot, recovery, and daily-use stability

## Test layers

The project should use multiple test layers.

### 1. Backend tests

Purpose:

- validate API behavior
- validate service logic
- validate command arbitration
- validate error handling
- validate settings and storage behavior

Examples:

- reject same-bus command conflicts
- accept simultaneous cross-bus actions where supported
- return correct error type when a bus is busy
- reject invalid sequence files
- stop a running sequence when a manual abort is requested

### 2. Frontend tests

Purpose:

- validate control interactions
- validate websocket-driven updates
- validate visible success/failure feedback
- validate advanced/settings flows
- validate responsive behavior for the intended layout model

Examples:

- button press shows active feedback
- rejected command shows failure feedback
- live log panel updates when new log events arrive
- recording tools appear in advanced/settings
- mode-specific controls change correctly between `DDC` and `Blind`

#### Playwright integrated E2E (`frontend/`)

End-to-end tests run **Chromium** against the built SPA served by **`pi-deck`** on port 8756 (same origin for REST and `/ws/events`, no dev proxy). `npm run test:e2e` runs `vite build` first so `backend/src/pi_deck/static/` matches the UI under test, then starts mock-hardware `pi-deck` if needed. This catches REST + WebSocket + UI integration that Vitest/jsdom cannot.

To hit a **running deck** instead (e.g. Raspberry Pi on the LAN):

```bash
cd frontend
E2E_BASE_URL=http://<deck-host-ip>:8756 npm run test:e2e
```

When `E2E_BASE_URL` is set, Playwright does not start local servers—ensure `websockets` is installed on the Pi and `pi-deck` is running.

### 3. Sequence validation tests

Purpose:

- validate recording schema correctness
- validate domain-object parsing
- validate event ordering rules
- validate wait-event semantics

Examples:

- valid `hold`, `release`, `delay`, `wait_led`, and `wait_ddc` events are accepted
- missing required fields fail validation
- unsupported event types fail validation
- invalid timeout or polling values fail validation

### 4. Sequence runner tests

Purpose:

- validate execution logic independent of the physical monitor where possible
- validate timeout behavior
- validate abort behavior
- validate rejection of concurrent sequence execution

Examples:

- a sequence stops when `wait_led` times out
- a sequence stops when `wait_ddc` times out
- manual abort stops a running sequence immediately
- a second sequence request fails while one is already running

### 5. Hardware-facing verification tests

Purpose:

- validate low-level monitor interaction
- validate observe-path behavior
- validate drive-path behavior
- validate `DDC` and `LED` assumptions against the real monitor

Examples:

- each low-level `JOG` action is interpreted correctly by the monitor
- idle bus state is observed correctly
- `KEY_LED` transitions are captured when expected
- supported `DDC` reads return expected values
- supported `DDC` writes succeed where confirmed

### 6. Integration tests

Purpose:

- validate user-facing monitor workflows end to end
- validate coordination between UI, backend, sequence execution, and monitor feedback

Examples:

- source switch in `DDC` mode
- source switch in `Blind` mode
- `PiP` enable flow
- `PiP` source selection flow
- replay of a shipped validated sequence

### 7. End-to-end and endurance tests

Purpose:

- validate regular-use stability
- validate recovery after reboot or crashes
- validate repeated monitor workflows over time

Examples:

- reboot returns to kiosk UI
- repeated source switching remains reliable
- repeated sequence execution does not leave the system stuck
- log retention and restart behavior operate as intended

### 8. Deck host health snapshots

Purpose:

- capture CPU, memory, disk, thermals, Raspberry Pi throttling/voltage, and `pi-deck` service health on the real deck when closing feature phases (see [Host health gate](../implementation/plan.md#host-health-gate-feature-phases-1028))

Tool: `scripts/pi-deck-host-health.py` — paste the **default text output** into the **Markdown** phase execution record (not JSON as the primary write-up; `--json` is optional for tooling or archives). Complements automated tests for resource and power regressions. For how that snapshot relates to **JOG kiosk / LAN UI** behavior, see [Phase 11 execution — JOG UI performance baseline](../implementation/phase-11-execution.md#jog-ui-performance-baseline) (short pointer: [ui-performance.md](ui-performance.md)).

## Test environment model

The project should assume more than one test environment.

### Local development environment

Used for:

- backend tests
- frontend tests
- schema validation tests
- some sequence-runner tests with mocks or stubs

### Hardware-attached development environment

Used for:

- low-level `JOG` verification
- `LED` observation testing
- `DDC` validation
- integration testing against the real monitor

### Daily-use validation environment

Used for:

- repeated workflow testing
- reboot recovery validation
- endurance testing

In practice, these may all be the same Raspberry Pi and monitor setup, but the test intent should remain distinct.

## Mock vs real-hardware boundary

The test strategy should explicitly separate what can be mocked from what must be proven on real hardware.

Suitable for mocks or stubs:

- API validation
- websocket event shape
- sequence schema parsing
- sequence-runner control flow
- settings persistence
- widget data-provider logic

Must be validated on real hardware:

- analog `JOG` action reproduction
- physical bus observation
- `KEY_LED` behavior
- real `DDC` timing and reliability
- interaction between physical `JOG` use and app-driven control

## Sequence-specific test design

Because sequences are central to the project, they need explicit validation rules.

Each promoted sequence should be checked for:

- valid schema
- meaningful name
- known start-state assumptions
- timeout behavior for any wait events
- success criteria
- expected failure behavior

Promoted sequences should not be treated as production-ready just because they replay once successfully.

## Error classes that tests should cover

The test design should cover at least these failure categories:

- bus busy
- overlapping same-bus command rejected
- sequence already running
- timeout waiting for `LED`
- timeout waiting for `DDC`
- `DDC` unavailable
- invalid start-state assumption
- manual abort
- internal hardware/control error

## Logging and observability tests

Because logs are part of the operational model, testing should also cover:

- event formatting
- log type/category labeling
- live log streaming to the UI
- file rotation by day
- retention behavior over time
- ability to disable persistent logging

## Completion gates

No phase should be treated as complete unless the relevant testing work for that phase has been done.

At minimum:

- backend-facing features need backend tests
- frontend-facing features need frontend tests
- hardware assumptions need hardware verification
- promoted monitor workflows need integration validation

## Recommended next test-design artifacts

After this strategy document, the project should eventually add:

- sequence schema validation rules
- hardware verification checklist
- integration test checklist for monitor workflows
- stabilization checklist for daily-use readiness

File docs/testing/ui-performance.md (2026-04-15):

# JOG UI performance (testing docs pointer)

The **full procedure and interpretation** for documenting JOG UI performance on the deck host—including `pi-deck-host-health.py`, when to run `scripts/deploy.sh`, reading `[pi-deck HTTP]` vs kiosk paint, and kiosk vs LAN browser—is recorded as part of **Phase 11**:

**[Phase 11 execution — JOG UI performance baseline](../implementation/phase-11-execution.md#jog-ui-performance-baseline)**

The [test strategy](test-strategy.md) “Deck host health snapshots” section links there for the same workflow.

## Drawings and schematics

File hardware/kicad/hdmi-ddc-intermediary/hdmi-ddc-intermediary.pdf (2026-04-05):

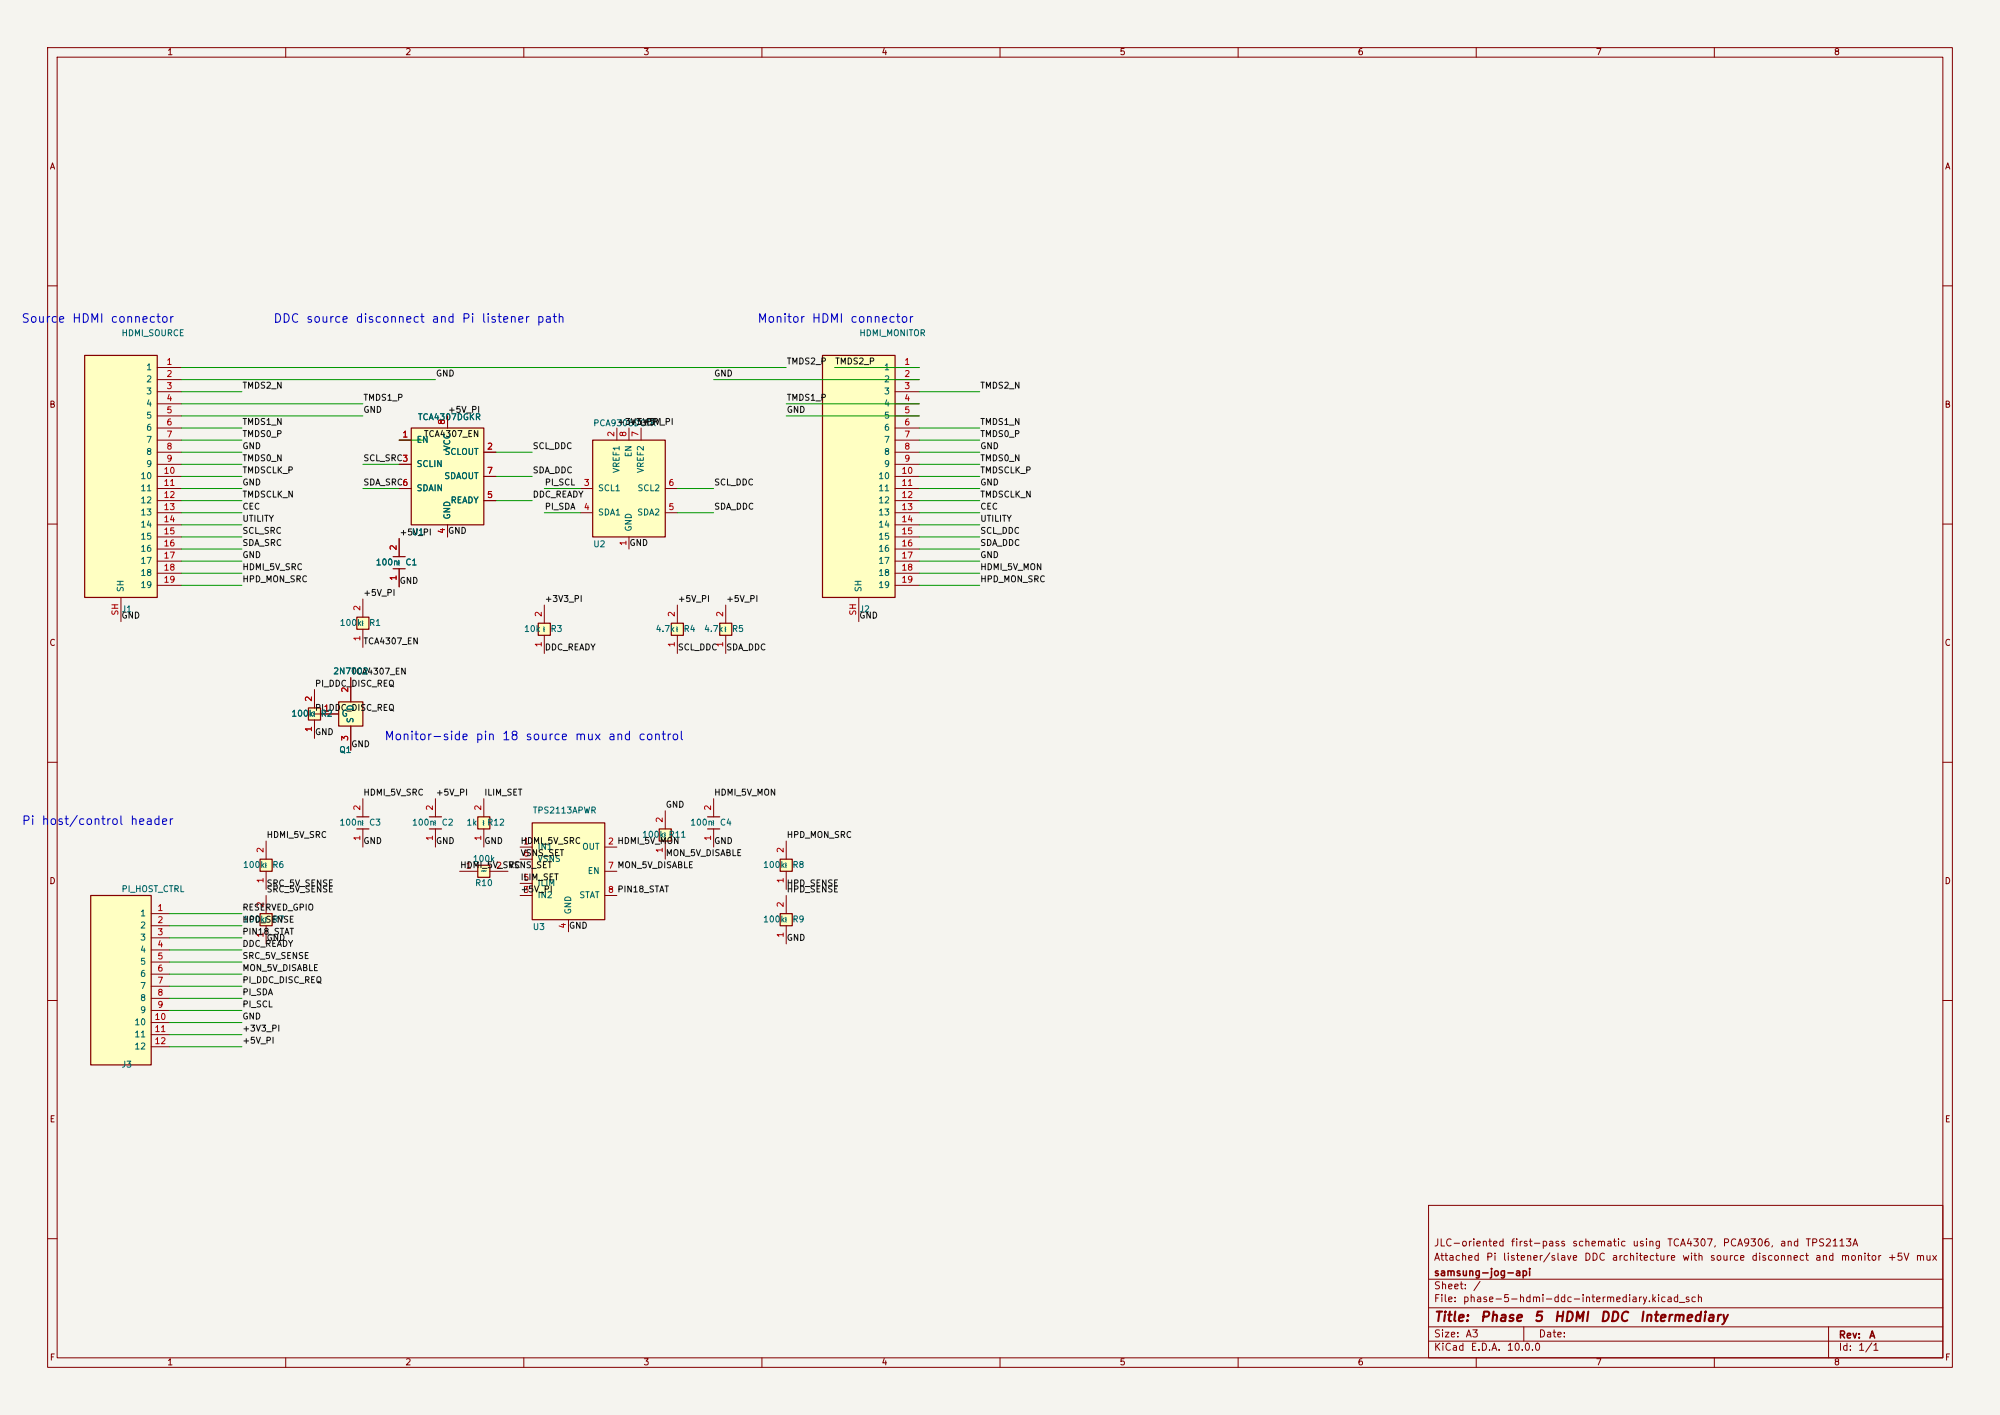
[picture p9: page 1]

Monitor-side pin 18 source mux and control

Pi host/control header
J3PI_HOST_CTRL

JLC-oriented first-pass schematic using TCA4307, PCA9306, and TPS2113A

Attached Pi listener/slave DDC architecture with source disconnect and monitor +5V mux
samsung-jog-api
Sheet: /
File: phase-5-hdmi-ddc-intermediary.kicad_sch
Title: Phase 5 HDMI DDC Intermediary

Size: A3 | Rev: A | F Date:
KiCad E.D.A. 10.0.0 | Id: 1/1

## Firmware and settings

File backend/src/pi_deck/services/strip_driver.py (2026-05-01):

"""Addressable RGB LED strip driver — WS2812B via SPI (GPIO10 / SPI0 MOSI).

Pi 5 (RP1 chip) does not expose the GPU DMA mailbox that rpi_ws281x uses,
so we drive the strip with the SPI bus instead.  SPI generates the precise
800 kHz NRZ waveform in hardware without needing root or DMA access.

Encoding (8 SPI bits per WS2812B bit at 6.4 MHz → 156.25 ns per SPI bit):
  WS2812B '1' → 0xF8 (11111000) : 781.25 ns high / 468.75 ns low  ✓
  WS2812B '0' → 0xC0 (11000000) : 312.5 ns high  / 937.5 ns low   ✓

This matches the Adafruit NeoPixel SPI encoding and gives well-centred
timing margins vs the WS2812B spec (±150 ns tolerance).

Hardware: GPIO10 (SPI0 MOSI, physical pin 19) → WS2812B DIN (direct, no level shifter).
The SN74AHCT125 level shifter was removed after testing showed it caused random frame
corruption and missed updates. WS2812B tolerates 3.3 V logic reliably at this distance.

Color order: the installed LED responds to RGB byte order (Red, Green, Blue), not the
GRB order specified by the standard WS2812B datasheet. This is common in clone/variant
units. If a replacement LED shows red and green swapped, change _encode_pixel to send
(g, r, b) instead of (r, g, b).

Lock model (per LED index):
  send(index, color)                         — normal; ignored if LED is locked
                                               always updates saved state
  send(index, color, lock=LockMode.LOCK)     — lock LED to color immediately
  send(index, color, lock=LockMode.UNLOCK)   — unlock and display color; color=None
                                               reverts to last saved state

Threading:
  send() is non-blocking — it enqueues a command and returns immediately.
  A single worker thread drains the queue, mutates per-LED state, and writes
  the full strip frame to SPI.  All state is owned by the worker thread so
  no additional locks are needed.
"""

from __future__ import annotations

import glob
import logging
import queue
import threading
from dataclasses import dataclass
from enum import Enum
from pathlib import Path

logger = logging.getLogger(__name__)

_SPI_SPEED_HZ = 6_400_000
_DEFAULT_BRIGHTNESS_PCT = 1  # 1 % default; persisted to ~/.pi-deck-led-brightness
_RESET = bytes(80)           # 80 bytes × 8 bits / 6.4 MHz = 100 µs reset pulse
_BRIGHTNESS_FILE = Path.home() / ".pi-deck-led-brightness"

# Named color constants — also accept any (r, g, b) tuple directly.
OFF   = (0,   0,   0)
GREEN = (0,   255, 0)
RED   = (255, 0,   0)
AMBER = (255, 165, 0)
BLUE  = (0,   0,   255)


class LockMode(Enum):
    LOCK   = "lock"
    UNLOCK = "unlock"


def _find_spi() -> tuple[int, int] | None:
    devices = sorted(glob.glob("/dev/spidev*.0"))
    if not devices:
        return None
    path = devices[0]
    parts = path.replace("/dev/spidev", "").split(".")
    return int(parts[0]), int(parts[1])


def _encode_pixel(r: int, g: int, b: int) -> bytes:
    buf = bytearray(24)
    for ch_idx, byte_val in enumerate((r, g, b)):
        for bit in range(8):
            buf[ch_idx * 8 + bit] = 0xF8 if (byte_val >> (7 - bit)) & 1 else 0xC0
    return bytes(buf)


@dataclass
class _LedState:
    saved:  tuple[int, int, int]        # last non-locked color
    locked: tuple[int, int, int] | None # None = not locked


@dataclass
class _Cmd:
    index: int
    color: tuple[int, int, int] | None
    lock:  LockMode | None


class StripDriver:
    """Addressable RGB LED strip with per-LED lock arbitration.

    send(index, color)                       — normal update, ignored if locked
    send(index, color, lock=LockMode.LOCK)   — lock LED to color
    send(index, color, lock=LockMode.UNLOCK) — unlock; color overrides saved if given
    """

    def __init__(self, num_leds: int, hw_mode: str) -> None:
        self._num_leds = num_leds
        self._live = hw_mode == "live"
        self._spi = None
        self._queue: queue.SimpleQueue[_Cmd | None] = queue.SimpleQueue()
        self._worker: threading.Thread | None = None
        # Worker-owned state — only touched from the worker thread.
        self._state: list[_LedState] = [_LedState(saved=OFF, locked=None) for _ in range(num_leds)]
        # Brightness — readable from any thread, written only via set_brightness_pct().
        self._brightness_pct: int = self._load_brightness()
        self._brightness_lock = threading.Lock()
        if self._live:
            self._init_spi()

    # ── lifecycle ─────────────────────────────────────────────────────────────

    def start(self) -> None:
        self._worker = threading.Thread(target=self._drain, daemon=True, name="strip-driver")
        self._worker.start()
        self._queue.put(_Cmd(index=-1, color=None, lock=None))  # initial assert
        logger.info("strip-driver: started (%d LED(s))", self._num_leds)

    def stop(self) -> None:
        self._queue.put(None)  # sentinel
        if self._worker is not None:
            self._worker.join(timeout=2)

    # ── public API ────────────────────────────────────────────────────────────

    def get_brightness_pct(self) -> int:
        with self._brightness_lock:
            return self._brightness_pct

    def set_brightness_pct(self, pct: int) -> None:
        pct = max(0, min(100, pct))
        with self._brightness_lock:
            self._brightness_pct = pct
        self._persist_brightness(pct)
        self._queue.put(_Cmd(index=-1, color=None, lock=None))  # reassert with new brightness
        logger.info("strip-driver: brightness → %d%%", pct)

    def send(
        self,
        index: int,
        color: tuple[int, int, int] | None,
        lock: LockMode | None = None,
    ) -> None:
        """Enqueue a command for LED at index. Non-blocking."""
        if not 0 <= index < self._num_leds:
            raise IndexError(f"LED index {index} out of range (0..{self._num_leds - 1})")
        self._queue.put(_Cmd(index=index, color=color, lock=lock))

    # ── worker ────────────────────────────────────────────────────────────────

    def _drain(self) -> None:
        while True:
            cmd = self._queue.get()
            if cmd is None:
                self._write_all_off()
                break
            self._process(cmd)

    def _process(self, cmd: _Cmd) -> None:
        if cmd.index == -1:
            self._write_strip()
            return

        s = self._state[cmd.index]

        if cmd.lock is LockMode.LOCK:
            s.locked = cmd.color
            logger.info("strip-driver: LED[%d] locked %s", cmd.index, cmd.color)

        elif cmd.lock is LockMode.UNLOCK:
            if cmd.color is not None:
                s.saved = cmd.color
            s.locked = None
            logger.info("strip-driver: LED[%d] unlocked → %s", cmd.index, s.saved)
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

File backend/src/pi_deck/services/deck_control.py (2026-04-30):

"""Command arbitration and jog orchestration (API and websocket notifications)."""

from __future__ import annotations

import asyncio
import logging
import platform
import sys
import time
from dataclasses import dataclass, field
from typing import Literal, cast

from pi_deck.hardware.protoboard_pins import JogAction
from pi_deck.models.schemas import (
    CommandRejectedReason,
    ControlState,
    OperatingMode,
    StatusOut,
    ws_command_rejected,
)
from pi_deck.services.hardware_facade import DeckHardwareFacade
from pi_deck.services.live_log import LiveLogService
from pi_deck.services.ws_hub import WsHub

logger = logging.getLogger(__name__)

_ACTION_MAP: dict[str, JogAction] = {
    "center": JogAction.CENTER,
    "up": JogAction.UP,
    "down": JogAction.DOWN,
    "left": JogAction.LEFT,
    "right": JogAction.RIGHT,
}
_STR_FOR_ACTION: dict[JogAction, str] = {v: k for k, v in _ACTION_MAP.items()}

_MAX_HOLD_S = 20.0


@dataclass
class HoldRecord:
    start_monotonic: float
    watchdog: asyncio.Task[None] | None = None


@dataclass
class DeckControlService:
    """Jog orchestration with one authoritative hold per direction."""

    hardware: DeckHardwareFacade
    ws_hub: WsHub
    live_log: LiveLogService
    version: str
    _operating_mode: OperatingMode = OperatingMode.JOG
    _control_state: ControlState = ControlState.IDLE
    _hold: dict[JogAction, HoldRecord] = field(default_factory=dict)
    _pulse_in_progress: bool = field(default=False, repr=False)

    def status(self) -> StatusOut:
        return StatusOut(
            version=self.version,
            hardware=cast(Literal["live", "mock"], self.hardware.kind),
            operating_mode=self._operating_mode,
            control_state=self._control_state,
            signals=self.hardware.read_bus_snapshot(),
            os_version=platform.platform(terse=True),
            python_version=sys.version.split()[0],
        )

    def set_operating_mode(self, mode: OperatingMode) -> None:
        self._operating_mode = mode

    def _any_holds(self) -> bool:
        return len(self._hold) > 0

    def _cancel_watchdog(self, rec: HoldRecord) -> None:
        if rec.watchdog is not None:
            rec.watchdog.cancel()
            rec.watchdog = None

    def _schedule_watchdog(self, jog: JogAction) -> None:
        deck = self
        action_str = _STR_FOR_ACTION[jog]

        async def _run() -> None:
            try:
                await asyncio.sleep(_MAX_HOLD_S)
                err, _ms = await deck.jog_release(action_str)
                if err is not None:
                    logger.warning("watchdog release %s: %s", action_str, err)
            except asyncio.CancelledError:
                pass

        rec = self._hold.get(jog)
        if rec is None:
            return
        self._cancel_watchdog(rec)
        rec.watchdog = asyncio.create_task(_run())

    async def jog_hold(self, action: str) -> CommandRejectedReason | None:
        """Assert ``action``; same-direction replacement avoids a GPIO glitch."""
        jog = _ACTION_MAP.get(action)
        if jog is None:
            return CommandRejectedReason.HARDWARE_ERROR

        # Replace same direction: no GPIO toggle (no extra drive edge).
        if jog in self._hold:
            prev = self._hold[jog]
            self._cancel_watchdog(prev)
            now = time.monotonic()
            self._hold[jog] = HoldRecord(start_monotonic=now)
            self._schedule_watchdog(jog)
            return None

        try:
            await asyncio.to_thread(self.hardware.set_jog_line, jog, True)
        except Exception:
            logger.exception("set_jog_line failed")
            msg = "Hardware failure while asserting jog line"
            await self._emit(
                ws_command_rejected(reason=CommandRejectedReason.HARDWARE_ERROR, message=msg),
            )
            return CommandRejectedReason.HARDWARE_ERROR

        self._hold[jog] = HoldRecord(start_monotonic=time.monotonic())
        self._schedule_watchdog(jog)
        self._control_state = ControlState.COMMANDING if self._any_holds() else ControlState.IDLE
        return None

    async def jog_release(self, action: str) -> tuple[CommandRejectedReason | None, int]:
        """Release ``action``; idempotent when already idle for that direction (duration_ms 0)."""
        jog = _ACTION_MAP.get(action)
        if jog is None:
            return CommandRejectedReason.HARDWARE_ERROR, 0

        rec = self._hold.pop(jog, None)
        if rec is None:
            return None, 0

        self._cancel_watchdog(rec)
        duration_ms = int((time.monotonic() - rec.start_monotonic) * 1000)
        duration_ms = max(0, min(duration_ms, 60_000))

        try:
            await asyncio.to_thread(self.hardware.set_jog_line, jog, False)
        except Exception:
            logger.exception("set_jog_line off failed")
            want = ControlState.COMMANDING if self._any_holds() else ControlState.IDLE
            self._control_state = want
            return CommandRejectedReason.HARDWARE_ERROR, 0

        self._control_state = (
            ControlState.COMMANDING if self._any_holds() else ControlState.IDLE
        )
        return None, duration_ms

    async def jog_press(self, action: str, duration_ms: int) -> None | CommandRejectedReason:
        """Legacy timed pulse — not allowed while directional holds are active."""
        if self._any_holds():
            await self._emit(
                ws_command_rejected(
                    reason=CommandRejectedReason.ACTIVE_HOLDS,
                    message="Release active jog holds before using timed pulse",
                ),
            )
            return CommandRejectedReason.ACTIVE_HOLDS

        if self._pulse_in_progress:
            await self._emit(
                ws_command_rejected(
                    reason=CommandRejectedReason.CONCURRENT_COMMAND,
                    message="Another timed pulse is in progress",
                ),
            )
            return CommandRejectedReason.CONCURRENT_COMMAND

        jog = _ACTION_MAP.get(action)
        if jog is None:
            return CommandRejectedReason.HARDWARE_ERROR

        duration_s = duration_ms / 1000.0
        if duration_s <= 0:
            return CommandRejectedReason.INVALID_DURATION
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

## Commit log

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2026-03-28 Complete phase 3 observation circuit fabrication files
    - Lock final part selection: ADS1115IDGSR (sub for ADS1114), TLV9064IDR,
    74LVC1G17GW x2; all passives on 0402 with verified LCSC part numbers
    - Update schematic symbol fields (MPNs, footprints) and link 3D models
    - Add custom symbol library (ADS1115IDGSR MSOP-10)
    - Generate production files via Fabrication Toolkit: Gerbers, BOM with
    LCSC numbers, CPL with corrected IC rotations (U1/U2 270°, U3/U4 180°)
    - Update phase-3-execution.md with final BOM table, LCSC numbers,
    fabrication file inventory, and revised status
    - Extend .gitignore with production/ subdirectory noise patterns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
    [bom.csv, phase-3-observation-reva.bom.csv, phase-3-observation-reva.kicad_pcb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]
2026-03-29 Migrate phase-3 schematic and project to KiCad 10 format
    - Update .kicad_sch: version 20250114→20260306, generator_version 9.0→10.0
    - Update .kicad_pro: solder_mask_to_copper_clearance 0.0→0.005, sch_revision →A, sheet name corrected to phase-3-observation-reva
    [phase-3-observation-reva.kicad_sch]
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2026-03-29 Fix ADS1115IDGS embedded symbol and bump rev to A.04
    The schematic had an empty geometry stub for Analog_ADC:ADS1115IDGS
    because the generation script never embedded the actual symbol body.
    Replaced with the fully resolved definition from the standard KiCad
    library (geometry inherited from ADS1015IDGS parent). Also corrected
    lib_id from ADS1115IDGSR to ADS1115IDGS to match the standard library
    name; Value and MPN fields retain ADS1115IDGSR as the actual order part.
    [phase-3-observation-reva.kicad_sch]
2026-03-29 Fix schematic: remove U1D spare channel, correct U1E power labels, bump rev A.06
    - Remove entire U1D spare channel sub-circuit (J3, R6, R7, TP8, TP9,
    associated wires, and net labels SPARE_BUF/SPARE_IN_RAW)
    - Fix swapped +3V3/GND net labels on U1E power unit (V+ pin was labeled
    GND, V- pin was labeled +3V3)
    - Bump schematic revision A.04 → A.06
    [phase-3-observation-reva.kicad_sch]
2026-03-29 Fix op-amp wiring: swap + and - inputs for correct voltage-follower topology
    The Python generator had connected the SENSE signal to the inverting (-)
    input and fed the output back to the non-inverting (+) input — positive
    feedback, not a buffer. Corrected for all three channels (U1A/U1B/U1C):
    - Remove wrong feedback stubs going from pin+ through symbol body to output
    - Remove SENSE labels from pin- positions
    - Add SENSE net labels directly at pin+ tips (pins 3, 5, 10)
    - Add negative feedback wires: output → down → pin- (pins 2, 6, 9)
    Op-amps now wired as proper unity-gain voltage followers. Rev A.07.
    [phase-3-observation-reva.kicad_sch]
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2026-03-29 Replace floating net labels with explicit wires from filter caps to op-amp + inputs
    Remove the floating KEY_*_SENSE net labels at cap tops and op-amp pin+ positions.
    Instead route visible L-shaped wires: cap top → right → down/up → pin+, giving
    a clear visible signal path from the R/C filter section into each op-amp. Rev A.09.
    [phase-3-observation-reva.kicad_sch]
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2026-03-30 Fix op-amp topology, restore U1D, populate filter caps, fix PWR_FLAG placement
    - Fix U1A/B/C voltage-follower wiring: output was feeding back to IN+ (positive
    feedback); rewired so SENSE signal goes to IN+ and output feeds back to IN-
    - Restore U1D (4th op-amp unit): was incorrectly removed; added back with IN+
    tied to GND and OUT looped to IN- to safely terminate the unused channel
    - Remove DNP from C6/C7/C8: filter caps are now populated by default (1n)
    - Fix PWR_FLAG placement: #FLG01 was stranded and redundant on +3V3; moved to
    GND net so each power rail has exactly one flag
    [phase-3-observation-reva.kicad_sch]
2026-03-30 Fix TLV9064 power pin wiring and move C1 next to C5
    - Fix U1E power connections: library had pin 4/11 labelled opposite to TLV9064
    datasheet (pin 4=V-, pin 11=V+); schematic was powering the chip with reversed
    supply rails which would damage the IC. Corrected pin 4 to GND and pin 11 to
    +3V3, and fixed embedded symbol pin names to match the datasheet
    - Move C1 (100nF) next to C5 (1uF) in the power supply section; both are +3V3
    decoupling caps and belong together on the schematic sheet. C1 now connects
    directly to existing wire endpoints, no new wires needed
    [phase-3-observation-reva.kicad_sch]
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2026-03-30 Fix dangling wire: connect R4 pull-up to +3V3 bus
    Wire from R4 pin 1 ended at (198.12, 13.97) with a 2.54mm gap to the
    +3V3 bus at (200.66, 13.97). Added bridge wire and junction at the
    T-intersection where the R4 vertical wire, R5 vertical wire, and
    horizontal +3V3 bus all meet.
    [phase-3-observation-reva.kicad_sch]
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2026-03-31 Fix misplaced no-connects, orphan PWR_FLAG wire, duplicate rail labels
    - Move AIN2/AIN3 no-connect markers from (147.32, 26.67/29.21) to the
    actual pin endpoints (144.78, 36.83/39.37) — they were 2.54mm off and
    floating in space
    - Remove the 32mm vertical wire connecting #FLG02 far below the +3V3
    bus; move #FLG02 directly onto the +3V3 bus junction at (226.06, 13.97)
    - Remove duplicate +3V3 and GND labels on C1 — both caps share the same
    rail wire so one label pair is sufficient
    [phase-3-observation-reva.kicad_sch]
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2026-03-31 Fix PCB overlaps, remove DNP from C6-C8, regenerate BOM and CPL
    - Move R6 (18,7.46)→(21.5,11) and R7 (18,9)→(23.5,11): both were inside
    U2 MSOP-10 courtyard, now clear with 1.2mm+ spacing
    - Move C3 (22.5,12)→(20.5,13) and C4 (22.5,17)→(20.5,17): were overlapping
    U3/U4 SOT-353 courtyards, now 0.87mm clear
    - Move C5 (25,3.5)→(25,8): was overlapping J3 courtyard, now clear
    - Remove DNP flag and "DNP" suffix from C6/C7/C8 value: these filter caps
    were changed from DNP to populated in the schematic corrections
    - production/bom.csv: add C6/C7/C8 row (LCSC C1588, 1nF C0G 0402)
    - production/positions.csv: regenerate with all updated positions, add
    C6/C7/C8 (previously absent due to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
    [bom.csv, phase-3-observation-reva.bom.csv, phase-3-observation-reva.kicad_pcb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]
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2026-04-13 Add Phase 7 Controller Board schematic baseline
    Synthesised from Phase 3 (analog sensing) + Phase 4 (key switch mux)
    sources via gen_board1.py. ERC passes with 0 errors, 161 warnings
    (all warnings are inherited source artifacts or suppressed by design).
    Key decisions:
    - ADS1115IDGSR → ADS1015IDGSR (C193969): direct VSSOP-10 drop-in,
    in stock at JLCPCB; 12-bit resolution is sufficient for resistor-
    ladder key detection
    - power_pin_not_driven and label_dangling downgraded to warning:
    custom +3V3_PI net name causes KiCad ERC quirk vs standard +3V3,
    but the design is functionally correct
    - Footprints verified: all 13 footprints resolve in installed KiCad
    libraries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
    [phase-7-controller-board.kicad_sch, phase-7-hdmi-ddc-board.kicad_sch]
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2026-04-13 Implement Phase 10 local API (REST, WebSocket, tests)
    Add /api/v1 routes for status, operating mode, and jog press with
    structured 409 rejections. Expose /ws/events with versioned envelopes.
    Wire DeckControlService with mock/live hardware and PI_DECK_HARDWARE=auto
    fallback when GPIO init fails. Extend /health with version; update systemd
    template and README; add phase-10 execution record and plan next steps.
    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
    [deck_control.py, hardware_facade.py, schemas.py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]
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2026-04-14 test(e2e): run Playwright against pi-deck (no Vite WS proxy noise)
    - Point local E2E at http://127.0.0.1:8756 so SPA, REST, and /ws/events share origin
    - test:e2e runs vite build first so static assets match the UI under test
    - Playwright: single webServer (mock-hardware pi-deck); optional E2E_BASE_URL for Pi
    - JOG UI polish, WS integration test, docs/README updates
    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
    [test_phase10_api.py]
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2026-04-14 fix(hardware): PI_DECK_HARDWARE live only, remove silent auto→mock fallback
    - build_hardware: mock | live only; default unset = mock; live fails fast on GPIO init
    - systemd template: PI_DECK_HARDWARE=live for production
    - Update phase-10 execution + test for live propagating init failure
    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
    [hardware_facade.py, test_phase10_api.py]
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2026-04-14 fix(hardware): live GPIO on Pi — rpigpio + RPi.GPIO polling for observe inputs
    - Default GPIOZERO_PIN_FACTORY=rpigpio before LiveDeckHardware (avoids native sysfs OSError 22)
    - Replace gpiozero DigitalInputDevice with RPi.GPIO read polling (add_event_detect failed on Pi 2)
    - Depend on RPi.GPIO on Linux; systemd template PI_DECK_HARDWARE=live
    - deploy_pi_deck_ui.sh: rsync pyproject, pip install -e ., systemd live; use ~/ paths on Pi
    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
    [hardware_facade.py, jog_observe.py, led_observe.py]
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2026-04-14 feat(jog): multitouch holds with hold tokens and refcounted GPIO
    Replace single global jog hold with per-gesture UUID hold_token, refcounted jog directions on the backend, and independent GPIO line toggles via set_jog_line. POST /jog/up now requires hold_token; timed pulses are serialized and rejected while holds are active.
    The web UI tracks one token per pointer, sends matching jog/up on release, and uses per-direction press counts for feedback. Deck chrome moves into reusable widgets; embedded static assets and docs are refreshed accordingly.
    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
    [deck_control.py, hardware_facade.py, jog_drive.py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]
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2026-04-14 fix(http): no-store for HTML shell, long-cache for hashed assets
    Prevents kiosk and LAN browsers from keeping an old index.html that references removed /assets/*.js after deploy. Add Phase 10 API tests for Cache-Control headers.
    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
    [test_phase10_api.py]
2026-04-14 feat(pi-deck): jog hold/release, drop center bus_busy, kiosk cache hardening
    - Replace jog down/up with POST /jog/hold and /jog/release; WS held/released/pulse
    - One hold per direction with replace semantics; remove hold_token flow
    - Stop gating center hold/press on KEY_ADC1 idle (bus observation deferred to later phase)
    - Stronger HTML cache headers; meta no-store; Chromium kiosk --disable-http-cache
    - Deploy script rsyncs kiosk launcher; fix client.ts JSDoc that commented out exports
    - Rebuild static bundle (hashed assets)
    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
    [deck_control.py, schemas.py, test_phase10_api.py]
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2026-04-15 Remove BUS_BUSY, tighten watchdog, add missing tests - Remove CommandRejectedReason.BUS_BUSY and adc1_physical_idle: physical bus conflicts are by design and the check was never implemented - Reduce 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
    [deck_control.py, hardware_facade.py, schemas.py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]
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2026-04-15 Phase 15: observation bus, deck WS restore, UI LED and OSD tweaks
    Add ADS1115 continuous read and asyncio telemetry poll for bus snapshots
    and KEY_LED changes; KEY_ADC2 decode helper and tests. DeckControlService
    again emits command held/released and bus snapshots so the UI stays reliable.
    Frontend: optimistic JogPad styling, LedIndicator follows key_led state
    from websocket status (no pulse), OSD mock no longer auto-opens on bus
    events. Document phase-15 execution record and update plan/README status.
    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
    [ads1115.py, deck_control.py, hardware_facade.py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]
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2026-04-16 WIP: bus telemetry from observation only; quieter live log
    - DeckControlService: drop ws_bus_snapshot after jog hold/release/pulse
    - ObservationBusService: mock poll loop + _observe_signals; live unchanged
    - LiveLogService: skip bus/snapshot and control/state in buffer; docstring
    - test_phase10: fix jog hold WS assertion comment
    - docs: plan-bus-log-hygiene (consolidated notes + implemented section)
    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
    [deck_control.py, live_log.py, observation_bus.py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]
2026-04-16 feat(observation): bus-only telemetry for jog UI; KEY_ADC2 in snapshot
    - Stop emitting command/held, released, pulse, and control/state from DeckControlService;
    keep command/rejected for API errors. Jog state in the UI comes only from bus/snapshot.
    - Add key_adc2_direction to SignalSnapshot; LiveDeckHardware owns ADS1115 and read_bus_snapshot();
    mock derives direction from drive lines; mock pulse holds lines for observation.
    - ObservationBusService: mock change notifier; record bus lines for replay; one WS frame per bus
    event (no duplicate log broadcast); snapshot-first non-idle emit race fix.
    - Live log: store readable bus snapshot/LED lines for replay; UI mirrors bus with busLogForma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
    [deck_control.py, hardware_facade.py, live_log.py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]
2026-04-16 fix(gpio): KEY_ADC1 digital observe is active-high (3.3 V = pressed)
    Pi pin was interpreted as active-low; on this net idle reads ~0 V (false) and
    assert reads ~3.3 V (true). Align is_active with GPIO.HIGH and update schema note.
    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
    [jog_observe.py, schemas.py]
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2026-04-16 fix(log): semantic bus lines only; drop snapshot dump from UI
    - Record short per-signal lines (key_adc1/key_adc2) via bus_delta_log_messages + publish;
    KEY_LED stays on led_changed. bus/snapshot no longer appends a replay row or a
    client-mirrored fat line.
    - Remove formatBusSnapshotLogMessage; WebSocket log/entry is the single source for lines.
    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
    [live_log.py, observation_bus.py, test_live_log_bus.py]
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2026-04-16 fix(gpio): do not crash when RPi.GPIO edge APIs are unavailable
    On Pi 5 / newer kernels add_event_detect and wait_for_edge can raise; catch
    and fall back to asyncio poll. Downgrade ADS alert thread errors to warning.
    Verified: deploy to live Pi returns /health OK.
    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
    [jog_observe.py, led_observe.py, observation_bus.py]
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2026-04-16 feat(gpio): IRQ telemetry via gpiozero+lgpio (replace RPi.GPIO edges)
    - Prefer lgpio pin factory when available; add lgpio linux dependency.
    - KeyAdc1Observe, KeyLedObserve, AdsAlertPin use DigitalInputDevice with when_*
    callbacks into the existing coalesced observe path; remove ADS wait_for_edge thread.
    - active_state=None for conditioned inputs (gpiozero PinInvalidState on lgpio).
    - Update phase-15 telemetry doc.
    Verified: deploy to Pi /health OK.
    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
    [ads_alert_pin.py, hardware_facade.py, jog_observe.py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]
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2026-04-16 chore: remove RPi ADS demo, optional AdsAlertPinRpi, and stale telemetry notes
    - Delete ads_alert_rpi_gpio.py and pi-deck-ads-alert-rpi-demo.py
    - LiveDeckHardware always uses gpiozero AdsAlertPin
    - Shorten phase-15 doc and observation_bus module docstrings
    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
    [hardware_facade.py, observation_bus.py, protoboard_pins.py]
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2026-04-17 Small fixes and improvements; 1. stop_playback() swallows non-cancellation exceptions — services/recordings.py:289-302 The except asyncio.CancelledError only catches cancellation. If the playback tas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
    2. Storage TOCTOU race in write_new() and rename() — storage/recordings.py:74-97
    Both check if a filename exists, then write. Two concurrent requests with the same stem can both pass the check and one will
    clobber the other. Fix with open(..., 'x') exclusive-create mode.
    3. RecordingWorkspace selection clears on delete instead o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
    [recordings.py, test_phase16_recordings.py]
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2026-04-22 Phase 19: display power hardening, Xwayland subpixel rendering, font-size lift
    - Replace bl_power sysfs with wlr-randr compositor control for display power-off;
    also zero sysfs backlight on power-off and restore on power-on (saves ~0.17A)
    - Fix TopBar power-on race: always fetch fresh display state before branching
    - Switch Chromium kiosk to Xwayland (--ozone-platform=x11) for subpixel font rendering
    - Enable fontconfig RGB subpixel rendering (remove 10-sub-pixel-none.conf)
    - Set html font-size: 20px base and font-weight: 500 for panel legibility
    - Lift all primary UI font sizes toward 1.2rem minimum (partial — follow-up commit)
    - Add display brightness/power/shutdown API routes and serv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
    [display_power.py, display_service.py, schemas.py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]
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2026-04-29 Close Phase 20: Raspberry Pi 5 rebuild and validation
    Infrastructure and fixes:
    - Auto-discover DSI output name (DSI-2 on Pi 5) and backlight path (11-0045)
    - Add i2c-dev module requirement to /etc/modules for Pi 5
    - Add --disable-gpu-vsync to kiosk script (fixes Chromium black screen on Pi 5/Xwayland)
    - Fix wlr-randr scale line to try both DSI-1 and DSI-2
    - Remove brightness cap (170→255); Pi 5 power delivery handles full brightness
    - Fix brightness persistence: always fsync to disk and remove spurious power-state guard
    - Add GET /api/v1/system/network endpoint (hostname + interfaces)
    - Add NetworkPanel to Settings page (hostname, connected status, IPv4 per interface)
    - Replace CSS border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
    [display_power.py, display_service.py, schemas.py]
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2026-04-29 Reposition Phase 21 display power control block in KiCad schematic
    Phase 21 components were placed at X≈152–188mm, overlapping the Drive
    Channels section that ends at X≈146mm. Moved the entire block to
    X=210–244mm, giving 60mm+ clearance. Component spacing: Q8 (S8550) at
    Y=100, Q9 (2N3904) at Y=150, passives spread vertically around each stage.
    [phase-6-protoboard-validation.kicad_sch]
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2026-04-29 Rewrite Phase 21 KiCad block: wire connections, remove DISP_GATE, fix spacing
    Replace all DISP_GATE net labels with actual wire segments. Q8 base node
    is now a physical junction connected by wires to R23.pin2, R24.pin1,
    C3.pin2 stub, and Q8.B. Q9 base is similarly wired from R21.pin1/R22.pin1
    to Q9.B. Increased vertical separation: Q8 at Y=104, Q9 at Y=130.
    [phase-6-protoboard-validation.kicad_sch]
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2026-04-29 Close Phase 21: display power on at service startup, schematic and docs finalised
    - Turn display on automatically in lifespan startup (display.power_on())
    - Add Pi 5 click-too-fast finding to phase-20-execution.md; remove from plan.md
    - KiCad: rewrite Phase 21 block — fix crowded layout, reconnect Q8, replace
    DISP_GATE labels with real wires and junctions, move C3/C4 to clear positions
    [phase-6-protoboard-validation.kicad_sch]
2026-04-29 Phase 21: reinit Waveshare panel registers after 5V power cycle
    The ws_touchscreen driver only writes panel init registers in probe(),
    which runs at boot but not after the panel loses power. Force-writing
    via i2cset -y -f bypasses driver ownership so the panel comes back
    without a reboot. Tested twice: controlled power_off → 5V disconnect
    → reconnect → power_on fully restores image and backlight.
    [display_power.py, display_service.py]
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2026-04-30 Phase 21: spinning indicator during power-on; cache DSI name; local power state
    - Replace CSS animation with spinning arc icon while display is turning on;
    minimum 3s pending duration so the animation is always visible
    - Cache DSI output name after first discovery to eliminate repeated wlr-randr
    subprocess calls
    - Track power state locally in DisplayService to avoid wlr-randr read on
    every API response
    [display_power.py, display_service.py]
2026-04-30 Close Phase 21: GPIO24 display power circuit validated on protoboard
    Hardware fixes confirmed during validation:
    - Q9 (2N3904) and Q8 (S8550) E-C swaps corrected
    - R24 reduced 4.7 kOhm to 220 Ohm for sufficient base drive (DISP_5V 2.8V to 4.7V)
    - gpio=24=op,dh added to config.txt so Goodix-TS touch probe() succeeds at boot
    Software changes:
    - initial_value=True so gpiozero does not glitch GPIO24 LOW on service start
    - DSI output cache and local power state cache (no extra wlr-randr calls)
    - reinit_panel() trimmed to 0xc0 + 0xc2 (minimum for image recovery)
    - 200ms delay after GPIO24 HIGH before i2cset (panel controller boot time)
    [display_power.py, display_service.py]
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2026-04-30 Phase 22: SW1 display button, status LED state machine, WS2811 RGB fix
    Physical button (SW1, GPIO4):
    - Short press: opens PowerMenu via WS display/open_power_menu event
    - Hold 3 s: powers display off at exactly 3 s (threading.Timer, no release needed)
    - Any press when display off: turns display on
    Status LED (WS2811, GPIO10 SPI):
    - Panel on → green; panel off → red; button held → amber
    - Monitor LED active → dims to 30% brightness (DIM_FACTOR kept for future use)
    - Fixed channel order: WS2811 uses RGB, not GRB
    - Switched from rpi-ws281x to spidev (Pi 5 RP1 incompatibility)
    Frontend:
    - display/open_power_menu WS category wired to TopBar.openPowerMenuTick
    - PowerMenu redesigned: Disp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
    [phase-6-protoboard-validation.kicad_sch]
2026-04-30 Phase 22: display button, status LED state machine, and UI state sync
    - Physical button: short press → open PowerMenu via WS; hold 3 s → display off
    at the 3 s mark (not on release); display off → any press turns on
    - Status LED: green=panel on, red=panel off, amber=button held; monitor LED on
    → LED fully off (0 %), monitor LED off → restore brightness + correct color
    - WS2811 RGB channel order fixed (was GRB)
    - UI power button: same 3 s hold behaviour as physical button (pointer events)
    - PowerMenu: Escape steps back countdown → menu → close
    - Display state sync: all controllers (button, UI, browser) share state via
    WS display/power_changed broadcast; displayOn lifted to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
    [display_button.py, schemas.py]
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2026-04-30 Rewrite status LED + implement Plan1 power button WS events
    LED: pre-computed SPI frames, direct _send_frame() from caller threads,
    _spi_lock for concurrency, correction thread every 5s, BLUE when monitor
    on + panel on, bounce_time=None on KeyLedObserve, direct set_state_callback
    path bypassing asyncio/CoalesceGate.
    Plan1: add display/power_button_held and display/power_button_released WS
    events so all browsers see physical button state; UI power button turns
    amber on physical hold (powerButtonHeld) or local 3s pointer hold (localHeld).
    [led_observe.py, schemas.py]
2026-04-30 Phase 23: doc reorganization, git-tag versioning, deploy harness
    Docs: rename all phase-scoped living reference docs to artifact names
    (observation-bom, analog-drive-bom, hdmi-ddc-transport, protoboard-bom,
    protoboard-schematic, pi5-gpio-schema, platform-bring-up); rename matching
    SVG assets; update all inbound links; add docs/hardware/README.md index.
    Versioning: replace hardcoded __version__ + deploy-counter append with
    _version.py generated at deploy time from git describe + branch + counter.
    StatusOut gains os_version and python_version for diagnostics. Tag v0.1.0
    created on this base commit; deploys now report 0.1.0+r<N>.
    Harness: deploy script pre-checks SSH connectivity (5 s timeout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
    [deck_control.py, schemas.py]
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2026-05-01 Phase 22: fix WS2812B LED — 8-bit SPI encoding, level shifter removed
    Switch to Adafruit 8-bit SPI encoding at 6.4 MHz for correct WS2812B
    timing margins. Remove correction daemon (was clobbering non-panel states).
    Fix race condition in _reassert by reading state inside _spi_lock. Add
    ms-precision timestamps and LED state/button/monitor logging. Document that
    SN74AHCT125 level shifter was removed after it caused random frame corruption.
    [display_button.py]
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2026-05-01 Replace StatusLedService with StripDriver
    Renames and redesigns the LED driver with a proper priority model:
    - Non-priority commands update saved state; applied immediately unless a
    priority override is active for that LED index
    - Priority commands override immediately; cancelled with color=None,
    which reverts to the last saved non-priority state
    - Worker thread owns all state and drains a queue — send() is non-blocking
    and no extra locks are needed
    - Supports N LEDs; full strip frame written on every state change
    - Color logic (monitor/panel/button → color) moves to app.py callbacks
    where all events are visible; StripDriver knows nothing about app state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
    [strip_driver.py]
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
